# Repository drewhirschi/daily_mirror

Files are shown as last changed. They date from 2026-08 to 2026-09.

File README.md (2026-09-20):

# Daily Mirror

Daily Mirror is a small physical camera appliance: press one button, take one
photograph, and upload it to a private chronological gallery.

The current revival keeps the interaction deliberately narrow. There is no
identity recognition, comparison, notes, alignment, or time-lapse generation.

## Repository layout

- `mobile/` — native Expo iOS gallery and account app, with a persistent,
  bounded thumbnail cache. See [`docs/mobile.md`](docs/mobile.md).
  For remote iPhone builds and installation, see the
  [free Tailscale/Xcode bridge guide](docs/tailscale-xcode-bridge.md).
- `packages/api/` — portable TypeScript API client with types generated from
  the Rust server's OpenAPI contract.
- `device/` — new Rust Raspberry Pi client: camera command, GPIO button and
  three LEDs, durable upload queue, and retries.
- `server/` — new NextRS/Axum API, local filesystem storage, React gallery,
  and Docker Compose configuration.
- `processor/` — intermittent Rust face-processing CLI and leased batch runner;
  the inference adapter is intentionally pending model selection.
- `crates/vision-contract/` — shared queue and face-result wire types used by
  the server and processor.
- `src/`, `snapr/`, and `view/` — the original 2022 Python, Rust/OpenCV, and
  React prototypes retained for reference.
- `data/` — photographs and face-recognition experiments from the original
  prototype. New captures do not belong in Git.

## Prototype flow

```text
button -> LED countdown -> ArduCam JPEG -> durable Pi queue
       -> signed upload grant -> local storage or private R2 -> web gallery
```

The device writes a completed JPEG to its queue before uploading. It removes
that file only after the server acknowledges it. A stable capture ID makes
network retries idempotent.

## Start the web server

```sh
cd server
cp .env.example .env
npm install
npm run client:generate
cargo dev
```

See `server/README.md` for the upload API and container setup.

The password-protected production gallery is deployed at
<https://daily-mirror-pearl.vercel.app>.

The planned path from breadboard prototype to an enclosed Pi appliance, R2 and
Vercel deployment, and a later ESP32 port is documented in
[`docs/productization-plan.md`](docs/productization-plan.md).
Deployment commands and the direct-to-R2 upload flow are documented in
[`docs/deployment.md`](docs/deployment.md).
The local Rust processing worker, durable job queue, face landmarks, identity
review workflow, and centered portrait pipeline are documented in
[`docs/face-processing-architecture.md`](docs/face-processing-architecture.md).

## Bring up the Raspberry Pi camera

```sh
cd device
cp .env.example .env
cargo run --release -- capture-once --no-upload
```

After validating the ArduCam output, configure the server URL and test an
upload before wiring GPIO. See `device/README.md` for pin assignments and LED
behavior.

## Inspect the face-processing queue

After setting `DAILY_MIRROR_SERVER_URL`, `DAILY_MIRROR_PROCESSOR_TOKEN`, and
`DAILY_MIRROR_PROCESSING_PIPELINE` in `processor/.env`, run:

```sh
just process-status
```

The leased Rust processing loop is implemented, but `just process` will refuse
to claim production photos until a face inference engine is selected. See
[`processor/README.md`](processor/README.md) and the
[face-processing architecture](docs/face-processing-architecture.md).

## Quality gates

Run `just check` to format-check, lint, generate and validate the typed client,
type-check the gallery, and test all Rust applications. Run
`just install-hooks` once per clone to make the same suite a mandatory local
pre-push hook. GitHub Actions runs it again for every push and pull request,
and production deployment refuses to start until it passes.

The root npm workspace manages mobile and shared TypeScript packages; the
NextRS server keeps its existing generated-client workspace. Run `npm ci` at
the repository root to install mobile dependencies, then `npm run mobile` for
Metro or `npm run ios` on a Mac to build and open the simulator.

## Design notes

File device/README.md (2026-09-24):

# Daily Mirror device

Rust owns the complete Raspberry Pi interaction loop: camera invocation,
durable local queue, upload retry, button debounce, and the three status LEDs.
The camera itself is invoked through Raspberry Pi's supported
`rpicam-still` command (falling back to `libcamera-still` on older images).

## Bring up the camera before wiring GPIO

```sh
cp .env.example .env
cargo run --release -- capture-once --no-upload
cargo run --release -- upload /path/to/test.jpg
cargo run --release -- retry
```

`capture-once` writes to the durable queue first. With `--no-upload`, it prints
the resulting path and leaves the file there. Without it, the device uploads
the image and removes the local queue copy only after a successful server
response.

Every upload first requests `POST /api/uploads` with the capture ID, JPEG size,
and bearer token. A local server sends the device back to its filesystem upload
route; production returns a short-lived R2 `PUT` URL. The Pi never stores R2
credentials and requests a fresh URL for every retry.

Use `DAILY_MIRROR_CAMERA_ARGS` for sensor-specific tuning after inspecting the
ArduCam. The default is:

```text
--nopreview --timeout 3000 --encoding jpg --quality 95 --autofocus-mode continuous --autofocus-range normal --autofocus-speed fast --autofocus-window 0.2,0.15,0.6,0.7 --metadata-format json --metadata -
```

## GPIO service

Pins use BCM numbering. Defaults are button 2, green 17, yellow 27, and red 22;
all can be changed in `.env`. The button is active-low with its internal pull-up
enabled. LEDs are active-high and must use appropriate current-limiting
resistors.

```sh
cargo run --release -- run
```

- Green: two quick flashes only when the complete workflow succeeds.
  Standby and processing keep the indicator off.
- Yellow: three one-second countdown pulses only.
- Red: a capture/upload error or at least one photograph awaiting retry.

The camera process and continuous autofocus start before the first yellow pulse.
Focus keeps tracking throughout the countdown, allowing the person who pressed
the button to move into the expected 3–5 foot portrait position. The default
focus window covers the central 60% of the frame width and 70% of its height,
rather than only the camera stack's middle third. Yellow stays solid after the
third pulse only until the actual full-resolution frame arrives, so it remains
an unambiguous “hold still” indicator. Green flashes twice on success, then returns to off. Yellow is never reused for background work.

Each normal capture also writes the camera metadata JSON to standard output,
which makes fields supplied by the camera stack such as `AfState`,
`LensPosition`, and `FocusFoM` available in the service journal. Available
fields depend on the installed camera and camera software.

The physical button always takes a picture. Holding it cannot trigger multiple
captures because the service waits for release and debounces both edges.

`run` also starts a small, server-rendered Axum admin page at
`http://<pi-address>:8080`. It shows camera, queue, GPIO, and process status and
mirrors the green, yellow, and red GPIO indicators in real time. It also reports
CPU temperature, one-minute load, memory use, and used/available storage for the
durable queue's filesystem. Status changes are sent over `/api/events` using
server-sent events; the page automatically reconnects and keeps a slow status
request as a fallback. It also has controls to take a picture, retry pending
uploads, and hold any one physical LED on for wiring diagnostics. The LED test
remains active until Restore status is chosen or the physical button is pressed.
Configure the listener with
`DAILY_MIRROR_ADMIN_BIND`. The prototype has no login and should remain on a
trusted LAN; it is intentionally independent of the NextRS archive/gallery.

`GET /healthz` is the lightweight readiness probe. It returns HTTP 200 when the
service is initialized, the camera command exists, uploads are configured, and
the device is not in an error phase; otherwise it returns HTTP 503 with the same
small JSON diagnostic body. The response includes `software_version` from the
running Rust package. It does not capture a photograph.

## Upload credentials and capture metadata

Set `DAILY_MIRROR_DEVICE_TOKEN` to the token this camera was issued when it
paired, and it is used as the `Authorization: Bearer` credential for every
server call: the upload grant, the signed upload when it targets the server
itself, and the completion call. Photographs then land against this device with
`capture_source` `device`. When it is unset (or blank), the legacy shared
`DAILY_MIRROR_UPLOAD_TOKEN` is used exactly as before and photographs land as
`legacy` with no device attached.

Each queued capture also writes a `<capture-id>.json` sidecar beside its
`<capture-id>.jpg` in the durable queue, holding the `capture` object described
in `docs/capture-metadata.md` — sensor, geometry, JPEG quality, exposure, gains,
lens position, AF state, colour temperature, firmware version, trigger and
`captured_at` — plus the raw libcamera control block as `sensor_metadata`. The
uploader reads it when requesting the grant and removes it with the JPEG once
the upload completes, so the metadata survives a restart or a queue drained
hours later. A queued photograph with no sidecar (one left by an older binary,
or a corrupt sidecar) still uploads; the `capture` object is simply omitted.

The trigger is recorded as `button` for the physical button, `app` for the
admin page's Capture now and `POST /api/actions/capture`, and `debug` for the
`capture-once` subcommand. Test-mode and camera-lab captures keep their own
richer local sidecars and are never uploaded.

## Camera lab

The admin's camera lab forces the IMX519's full-field 2328×1748 binned sensor
mode, then scales it to a persistent 960×720 MJPEG viewfinder in memory. It
can adjust exposure compensation, brightness, contrast, saturation, sharpness,
denoising, white balance, metering, exposure profile, manual shutter/gain, and
the complete focus strategy. Focus controls include continuous, single, or
manual modes; range and speed; normalized autofocus-window coordinates; direct
lens position; and one-click fixed-focus presets for 3, 4, and 5 feet. The live
image overlays the selected autofocus region. Starting preview or taking a test
snap automatically applies every visible control, while Apply settings restarts
an active preview so the camera algorithms settle under the new configuration.

The lab also provides persistent 0°/180° rotation and horizontal or vertical
mirroring. Applying settings writes those mounting controls to
`data/camera-settings.json`; the service reloads them at startup and applies
them to the live preview, full-resolution test snaps, and normal button
captures. Override the file location with
`DAILY_MIRROR_CAMERA_SETTINGS_PATH` when packaging the device differently.

`Apply + test snap` stops preview, captures one 4656×3496 JPEG with the visible
lab settings, and retains only its bytes and camera metadata in service memory.
The page shows autofocus state, lens position, focus score, exposure, analogue
gain, the complete metadata JSON, and a link that opens the full-resolution
image for 100% inspection. It does not touch the durable queue, local photo
storage, or gallery upload endpoint. Starting preview again or pressing the
physical button safely releases/reclaims the camera; a physical capture always
stops lab preview before running the normal workflow.

## rpi2: common-anode RGB indicator

The four-leg LED identified on rpi2 has leg 3 as common positive (3.3 V),
leg 2 green (P17 through its own resistor), leg 1 blue (P27 through its own
resistor), and leg 4 red (P22 through its own resistor). Button: SDA/P2 to GND.
Set `DAILY_MIRROR_LED_MODE=rgb-common-anode`. Keep the legacy pin environment
names: `YELLOW_LED_PIN=27` now identifies the physical blue output.

RGB mode starts all channels HIGH/off. Countdown yellow
combines red and green; success flashes green while ready/processing stay off. A queued upload
shows steady red instead of combining ready green and error red into yellow.
The admin's green/yellow/red lamps represent logical status colors; `/api/status`
also reports `led_mode`. Blue and white are reserved for later behavior.
The default `discrete` mode preserves rpi1's active-high three-LED hardware.

Select `DAILY_MIRROR_CAMERA_PROFILE=ov5647` for Camera v1 or `imx219` for
Camera v2. Omit `DAILY_MIRROR_CAMERA_ARGS` to use the profile defaults.

A matching systemd unit is in `deploy/daily-mirror-device.service`. It expects
`/home/drew/daily-mirror-device/bin/daily-mirror-device` and a mode-0600 `.env` in
`/home/drew/daily-mirror-device`. Enable the unit after installing both.
Use `DAILY_MIRROR_ADMIN_BIND=0.0.0.0:8081` for the new Pi.

## Camera profiles and local development

Two independent settings control hardware behavior and photo destination:

```text
DAILY_MIRROR_CAMERA_PROFILE=ov5647
DAILY_MIRROR_CAPTURE_MODE=local
DAILY_MIRROR_LOCAL_DIR=./data/local
```

| Profile | Camera | Full-resolution still | Focus |
| --- | --- | --- | --- |
| `imx519` | IMX519 | 4656 × 3496 | Autofocus, manual lens control |
| `ov5647` | Pi Camera v1 / Rev 1.3 | 2592 × 1944 | Fixed focus |
| `imx219` | Pi Camera v2 | 3280 × 2464 | Fixed focus |

`camera_profile.rs` holds the sensor-specific resolution, focus capabilities,
and preview-mode choices. The shared rpicam backend owns file capture, JPEG
validation, camera locking and orientation. Both normal capture and the lab
(still and preview) use the same profile; the UI disables unsupported focus
controls. Add future rpicam-compatible sensors here rather than scattering
sensor checks through the application. A USB/OpenCV camera would require a
separate capture backend, not merely another sensor profile.

Profiles are selected explicitly; they do not install kernel drivers or identify
a disconnected sensor. The default stays `imx519` for existing installations.
`DAILY_MIRROR_CAMERA_ARGS` remains an advanced override for normal capture only;
it replaces profile-generated arguments, so remove stale overrides when changing
sensors. Preview and lab stills continue to use the selected profile.

`local` mode saves button and admin captures in `data/local`, never queues or
uploads them, disables upload retries, and ignores server credentials even if
present. The admin page shows the latest 24 local photos, with full-resolution
links. This page is accessible on the LAN. Files remain until manually removed;
monitor free disk space during development. `capture-once --no-upload` also uses
this separate local directory, even when configured for upload mode.

`upload` mode retains the existing durable queue/retry behavior in `data/pending`.
Switching to upload mode does not sweep local photos into that queue. The two
directories must be distinct. The code defaults to `upload` for compatibility;
the example environment explicitly selects `local` for new development setups.
The standalone `upload` command refuses to run in local mode.

On rpi2, uploads are disabled and production credentials have been removed.
The replacement camera is now IMX519. Boot configuration sets
`camera_auto_detect=0` and `dtoverlay=imx519`; detection was verified after reboot.
The stock sensor tuning lacked `rpi.af`, even though the AK7375 lens driver was
bound. A separate `config/imx519-portrait.json` adds contrast autofocus and a gentle
shadow lift, selected by
`LIBCAMERA_RPI_TUNING_FILE` in the device `.env` for both stills and preview.
The actuator map is provisional: reported lens position and distance presets
are not calibrated physical distances for this replacement module.
See [the calibration record](../docs/imx519-rpi2-calibration.md). The admin `camera_available` API field
remains an executable check, not a sensor probe.

### Inspect local test photos

In local capture mode, click a photo in **Local test photos** to open the
in-page viewer. Use the newer/older buttons or left/right arrow keys to move
through the listed photos; Escape or Close returns to the grid. **100%** shows
native image detail with scrolling, and **Fit** returns to the whole frame.
The Metadata button hides or shows the overlay without leaving the image.

The overlay reads embedded JPEG EXIF: exposure, ISO, reported focus distance,
camera/software, timestamp, and other supported fields, plus file size and
displayed dimensions. Missing fields are explicitly unavailable; current lab
settings are never attributed to old captures. EXIF timestamps have no assumed
timezone, and reported focus distance is not a measurement of subject distance.
This does not change capture processing or rewrite the originals.

Parser checks: `node device/tests/local_photo_viewer.test.cjs` from the repository root.

### Admin Test mode and photo profiles

In **Photo settings**, enable **Test mode**, choose a profile, and press **Save photo settings**.
This controls the physical button and **Capture now**. Test captures go to `data/local/` with
JSON sidecars containing the profile, command arguments, orientation, tuning file, and sensor
metadata. They are never queued for upload, including after Test mode is disabled. Upload
retries pause in Test mode. A mode change waits for an existing capture/upload to finish;
the saved confirmation marks when the new policy applies.

The selection survives service restarts in `data/photo-settings.json` (override with
`DAILY_MIRROR_PHOTO_SETTINGS_PATH`); saved settings take precedence over the environment's
initial capture mode. `capture-once --no-upload` still forces a local capture.

IMX519 profiles:
- **Current device configuration** preserves the configured camera arguments and tuning.
- **Neutral**: 4656×3496, stock tone with contrast AF, neutral color/sharpness.
- **Vibrant**: 4656×3496, lifted shadows, saturation/sharpness 1.15, sport exposure.
- **Fast**: 2328×1748 with the full-field binned sensor mode, Vibrant processing.

Named profiles require `config/imx519-af.json` and/or `config/imx519-portrait.json` relative
to the service working directory. These already exist on rpi2; use
`scripts/prepare_imx519_tuning.py` on the Pi to generate them (shadow exponent 1 and 0.85).
Other sensors retain their device configuration. Multi-frame merging is not yet an admin profile.

**Local test photos** offers photo and settings downloads in either mode. For bulk retrieval,
copy the device's `data/local/` directory with SCP/rsync. Existing photos predating metadata
sidecars may have no settings download. Custom camera-lab captures also save here, labeled
`custom-lab`; the lab keeps its independent controls rather than applying the photo profile.
No automatic local-photo deletion is performed; the admin page shows remaining storage.

API: `POST /api/photo-settings` with `{"test_mode":true,"profile":"vibrant"}`; active settings
appear in `/api/status`. Local files: `/api/local/photos`, `/api/local/photos/{name}`, and
`/api/local/photos/{name}/metadata`. Returning to cloud capture requires configured server
URL and upload token; it resumes the existing upload queue, never local test photos.

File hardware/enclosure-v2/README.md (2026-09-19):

# Daily Mirror - rail enclosure prototype 02

This is the September 10, 2026 revision for the **confirmed Raspberry Pi 4 Model B**.
It replaces the old rail motion study with printable mating parts, a thumb lock,
removable end stops, actual camera standoffs, and front control holes.
The earlier `hardware/enclosure` concept remains available unchanged.

**Start with `output/model-viewer.html` in a browser** to rotate the real model,
show the internals, separate the lid, and move it through its full travel.
FreeCAD's window is not needed for viewing this preview or printing the STLs.

For the mounting details, select **How the Pi screws in** or **How the rail
attaches** in the viewer. Both views separate the parts and show reference
screws; move separation to zero to see them assembled. The attachment view
shows only a short section of the actual rail for clarity. The four enclosure
screws are inserted from inside the case into the orange sliding block.
The Pi uses its four existing mounting holes; additional retaining clips are
not part of this screw-mounted design. Reference fasteners are not printed.

For scale, the enclosure is about **5.5 x 6.7 x 2.2 inches**, versus an
85 x 56 mm Pi PCB. It deliberately includes room for the camera, controls,
power-plug routing, cooling and later flash components. It is smaller than
the earlier 180 x 180 x 73 mm enclosure concept.

Enclosure, internal mounts and rail

## What is modeled

| Feature | Prototype dimensions / behavior |
| --- | --- |
| Enclosure | 140 wide x 170 tall x 55 deep mm including front panel; 3 mm walls; rounded corners |
| Pi mounts | Four 8 mm raised posts, 58 x 49 mm hole centers; 2.0 mm pilot bores |
| Camera mounts | Four 9 mm raised posts on the front panel; 21 x 12.5 mm hole centers; 1.6 mm pilots |
| Front openings | 18 mm lens, 5.2 mm status LED, 12.2 mm button |
| Power | One 14 mm bottom cable passage, internal zip-tie saddles; no exposed USB/Ethernet/HDMI ports |
| Rail | Two 208 mm sections, 416 mm assembled; 80 mm wide, 12 mm maximum wall depth |
| Rail joint | 6 mm rear alignment tongue; each section independently screws to the wall |
| Carriage | 60 x 100 mm, captive dovetail, 0.4 mm horizontal side and top allowances |
| Adjustment | 300 mm continuous travel between separately installed end stops |
| Lock | M4 thumb screw, captive nut, 8 mm rubber/TPU brake pad; knob accessible below the box |
| Wall projection | 78 mm nominal to front face, excluding button/lens projection |
| Future flash | 24 x 28 x 20 mm reserved volume; replaceable front panel for later optics |

The **entire box moves**: Pi, camera, LED, button and their wiring. Only the
external power cable flexes during height adjustment. Leave a loose service loop
that reaches both travel limits without tugging on the plug.

This design assumes a **new printed rail**, not compatibility with a purchased
rail. It uses wall screws, not adhesive strips. Each rail section must be fixed
to the wall; the small tongue aligns the joint and does not carry the wall load.

## Files and slicer basics

- `output/DailyMirror-Rail-Enclosure-v2.FCStd`: native FreeCAD document with
  named solids, grouped printable parts, hardware references and fit coupons.
- `OpenModel.FCMacro`: optional FreeCAD macro that opens the document with
  clean visibility and part colors. Run via Macro > Macros, or open the macro
  file in FreeCAD. The model can be opened directly without running the macro.
- `output/*.stl`: **one physical part per file**, in millimeters, pre-oriented
  and moved onto the print bed. Import each as an independent part at 100% scale.
- `output/*.step`: CAD solids in **assembly coordinates**, useful for editing
  or moving to another CAD program. `Assembly.step` has the nine print parts.
- `output/model-viewer.html`: self-contained interactive preview; no account,
  external library, network, or FreeCAD install needed. It requires WebGL.
- `output/enclosure-preview.png` and `output/mount-details.png`: still previews.
- `dimensions.json` and `build.py`: the coordinated dimension source and
  modeling recipe. Change the JSON and rebuild to change the fit. The FCStd
  contains editable solids, **not a fully constrained sketch-based feature tree**.
- `output/validation.json`: actual geometry/interference check results.

An STL describes the shape. Your **slicer** combines it with your printer,
nozzle and material settings to produce the printer's job file, often G-code.
No printer-specific job has been generated because the printer is not yet known.
Do not send STEP/FCStd files directly to the printer.

## Print these small pieces first

1. `RailFitMale.stl` and `RailFitFemale.stl`: matching short sections of the
   exact dovetail. They should slide by hand without being forced and without
   excessive rocking. Remove elephant's foot first. Change `rail_clearance`
   in 0.1 mm increments and rebuild if needed; do not globally scale the parts.
2. `CameraFitCoupon.stl`: a small section of the actual front panel, containing
   the real lens opening and four real posts. Screw the camera onto it from
   behind. Confirm hole positions, screw engagement, component clearance and
   full-field image coverage. The camera faces through the hole; its ribbon
   connector points toward the bottom of the enclosure.
3. Check a Pi screw gently in one post and confirm your M4 nut and bolt head fit
   the carriage and knob pockets before assembling everything.

## Full print list

| STL | Quantity | Supplied print orientation | Notes |
| --- | --- | --- | --- |
| Housing | 1 | Flat rear on bed, cavity up | Vents bridge 3 mm; tie saddles bridge 3 mm |
| FrontPanel | 1 | Exterior face on bed, camera posts up | Keep lens hole and posts clean |
| RailLower | 1 | Flat back on bed | 80 x 214 mm footprint including alignment tongue |
| RailUpper | 1 | Flat back on bed | 80 x 208 mm; small rear key pocket bridges 16.5 mm |
| Carriage | 1 | Standing on short end | 60 x 18.6 mm footprint, 100 mm tall; use brim |
| StopLower / StopUpper | 1 each | Standing on short end | These are separately installed pieces |
| LockKnob | 1 | Flat back on bed, hex pocket up | Captures M4 hex-head screw |
| BrakePad | 1 | Flat | TPU, or cut an 8 mm disc from 1.5 mm rubber |

Starting settings for a fit prototype: 0.4 mm nozzle, 0.2 mm layers, four walls,
five top/bottom layers, 25-35% infill. Use a brim on the upright carriage and
small stops. Inspect overhangs and bridging in your slicer, especially the
rail's alignment pocket and the lock-nut loading slot. Remove any support or
brim residue from sliding surfaces and threaded pilots.

All rigid parts fit a nominal **220 x 220 mm bed**, before printer-specific
exclusion zones. The 214 mm rail leaves only 3 mm at either end on that bed:
omit a wide brim there or change the segment length for a smaller printer.
The design is intended to print without extensive supports in the supplied
orientations, but the actual slicer preview and first print decide this.

PLA is suitable for the first dimensional trial. Choose the installed material
after measuring enclosure temperature; PETG is a candidate for the final trial.
Use the same material/settings for rail coupons and final rail parts. No
temperature, friction, lifetime or load performance has been physically tested.

## Hardware

Lengths below are **under the head**, with no additional washers unless you
adjust length. Use small pan/wafer heads for PCB screws. The printed pilots are
intended for thread-forming screws for plastic; do not force unsuitable screws.

| Hardware | Quantity | Purpose |
| --- | --- | --- |
| M2 x 6 thread-forming screws | 4 | Camera through PCB into front posts |
| M2.5 x 8 thread-forming screws | 4 | Pi through PCB into 8 mm posts |
| M3 x 12 thread-forming screws | 4 | Front panel to shell, 9 mm engagement |
| M3 x 10 thread-forming screws | 4 | Through inside of housing rear into carriage, 7 mm engagement |
| M3 x 12 thread-forming screws | 4 | Two per recessed end stop, 4 mm rail engagement |
| M4 x 16 hex-head machine screw | 1 | Thumb lock; nominal 7 mm across-flats head |
| M4 hex nut | 1 | Captive carriage nut, nominal 7 mm across flats x 3.2 mm thick |
| Rubber/TPU disc, 8 mm diameter x 1.5 mm | 1 | Brake contact pad; may use BrakePad STL |
| Wall screws and suitable anchors | 8 | Rail holes are 4.5 mm; heads must be <=8 mm diameter |
| Small zip ties | 2 | Internal power cable restraint |
| 5 mm LED + wiring, 12 mm panel button | 1 each | Placeholder control sizes; choose exact parts before full panel print |

The status LED's flange fits within the 7 mm baffle bore. Secure it with a small
amount of suitable removable adhesive after checking fit. The button must accept
a 3 mm panel and its internal body/nut must fit within the 18 mm diameter,
25 mm depth allowance. Hardware shown in the viewer is simplified, not supplied.

## Assembly sequence

1. Print and test the fit coupons. Deburr openings and sliding edges. Verify
   that each pilot accepts its intended screw without splitting the post.
2. Insert the M4 nut into the carriage's slot from the **lower end**. Insert
   the M4 x 16 bolt into the knob's front hex recess and engage it in the nut.
   Place the brake pad in its 8.5 mm pocket facing the rail. A tiny dab of flexible
   adhesive on the screw tip can retain the pad; keep adhesive off the rail.
   Back the knob out enough that the pad does not drag during insertion.
3. Fasten the carriage to the enclosure with four M3 x 10 screws from inside.
   Its long section projects below the housing; the knob must remain reachable.
4. Feed the unplugged USB-C lead through the bottom opening. This assumes the
   plug overmold is no more than about 13 mm across. Fit a protective sleeve if
   needed, plug into the Pi, and secure the cable to the internal saddles with
   zip ties. The printed opening itself is a passage, not a sealing gland.
5. Screw the Pi onto its four posts. Confirm that no screw tip or mounting part
   touches a PCB component. The model allows 26 mm above the board for cooler,
   components and header plugs; check your actual assembly against that space.
6. Install the camera on the front-panel posts, lens facing outward. Add the
   LED and button, connect their wiring, and route the camera ribbon with a
   relaxed service bend. No repeated ribbon flex is needed during rail motion.
   Support the lid when opening it: it carries the camera and is tethered by the
   ribbon. Use the four M3 x 12 screws to close the panel.
7. Align the two rail sections vertically on a flat mounting surface with the
   tongue engaged. **Use the carriage straddling the joint as an alignment gauge**
   before final tightening. Fix both sections with the eight wall screws. Keep
   the screw heads outside the carriage path; the model allows <=8 mm heads.
8. Fit the lower stop. Slide the carriage onto the rail from the open upper end,
   then screw on the upper stop. The separate stops make insertion and servicing
   possible. Do not leave the sliding assembly without both stops fitted.
9. Support the enclosure with one hand, loosen the knob, choose a height, and
   tighten gently. The pad presses the rail and takes up play against the
   dovetail. Check holding force at several heights and across the joint before
   leaving it mounted. The stops limit travel but are not a rated safety catch.

**There is no validated holding-load rating yet.** Weigh the complete unit and
bench-test the actual printed rail, brake, fasteners and wall attachment with
that load, including repeated adjustment and button presses. After fit-up,
verify that sustained camera operation does not cause Pi throttling or excess
heat inside the enclosure. Keep the external power service loop free through
the full 300 mm of travel.

## Remaining measurements

The Pi model is confirmed. These dimensions remain provisional:

- Actual sensor board/lens: 25 x 23.862 mm PCB reference, 21 x 12.5 mm mounting
  centers; lens center assumed 9.5 mm from the top PCB edge, lens envelope
  15 mm diameter x 11 mm projection. PiCam-compatible holes do **not** guarantee
  identical lens position or component heights. The camera coupon checks this.
- Exact button and LED parts, printer model, material and useful bed area.
- Installed cooler, GPIO connectors, ribbon length/bend and USB-C plug overmold.
- Required wall location, useful height range and mounting surface.

The flash is **reserved space only**, not a working flash mount, diffuser or
electrical design. A future flash can use a revised front panel; it needs its
own chosen light source, optics, driver and heat management. The status LED
opening does not assume it can light a photograph.

## Geometry checks and rebuilding

```bash
bash hardware/enclosure-v2/build.sh
```

The build uses the installed FreeCAD 1.1.3 modeling engine without opening a
window. It checks all printable solids, closed meshes, pairwise printable-part
interference, hardware-to-shell/front clearances, sampled movement across the
rail joint and through both travel limits, and geometric retention by the
dovetail and end stops. Saved FCStd/STEP/STL files are reopened to check that
geometry, volumes, print dimensions and bed placement survive export.

These checks establish coherent printable geometry, **not physical fit or
structural certification**. The numeric report is in `output/validation.json`.
The generator asserts the minimum fixed-layout envelope when dimensions change;
larger layout changes may require edits to the Python recipe as well as JSON.
Rebuild with the model closed, or save manual FreeCAD edits to another filename.

## Dimension sources

- [Official Raspberry Pi 4 B mechanical drawing](https://datasheets.raspberrypi.com/rpi4/raspberry-pi-4-mechanical-drawing.pdf):
  85 x 56 mm board, 58 x 49 mm hole pattern, 3.5 mm edge offsets. Saved in `reference/`.
- [Official Camera Module 2 mechanical drawing](https://datasheets.raspberrypi.com/camera/camera-module-2-mechanical-drawing.pdf):
  25 x 23.862 mm board, four 2.2 mm holes, 21 x 12.5 mm pattern after orienting
  the ribbon downward. Saved in `reference/`. This establishes a reference
  pattern, not the dimensions of the user's different sensor/lens.
- [Raspberry Pi camera hardware documentation](https://www.raspberrypi.com/documentation/accessories/camera.html):
  shared board/hole geometry does not imply interchangeable lens clearance.

Camera posts and locking carriage

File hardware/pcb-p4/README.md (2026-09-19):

# Daily Mirror custom PCB - A1 component study

Open **daily-mirror-p4.kicad_pro** in KiCad 10. This is an editable starting
project with the connected controls schematic and **64 additional candidate
components** on four new schematic pages and the board. It now has 80 electrical
references plus four mounting holes. The imported main components have no circuit
connections yet; the board has no routed traces. **Do not order this board.**

See [sourcing.md](sourcing.md) for the part choices, 3D-model limitations and
open-reference workflow. [candidate-parts.csv](candidate-parts.csv) records
the new parts and their sources; it is not an order-ready BOM.

An editable, routed Olimex P4 development-board reference is in
[reference/olimex-esp32-p4-devkit](reference/olimex-esp32-p4-devkit).
Open its `ESP32-P4-DevKit_Rev_D1.kicad_pro` separately to inspect the original
connected design. It has not been merged into the Daily Mirror circuit.
The previous A0 files/previews are saved in `revisions/a0`.

## Decisions from this session

- Keep the existing Arducam IMX519 as the camera baseline; preserve the goal of
  16 MP stills. Use a purchased camera module on a ribbon cable. The image
  sensor and lens do not need to be integrated onto the main custom PCB.
- USB-C wall power; a new enclosure designed around the final electronics.
- Cost matters: favor a standard four-layer main board for the P4, common
  stocked components, and assembly on one side where practical. Evaluate total
  assembled cost, including setup and shipping, rather than promotional bare-PCB
  prices. No per-unit budget or production quantity has been specified yet.
- One small four-pin RGB status indicator, plus a momentary capture/pairing button.
- **White-only emitters are preferred** around the perimeter for photographs.
  The three-color CL651-3S modules are optional prototype parts, not a required
  final component. Choose documented white LEDs/modules and their current
  drivers once the brightness, optical layout and power budget are established.
- Snap-in removable diffuser above the light modules. Include an opaque lens
  baffle, room between diffuser and emitters, and space behind the modules for
  a heat-spreading mount. Diffuser material, thickness, gap and clips need an
  optical/mechanical prototype; the current enclosure models are Pi-specific.

## Important processor finding

**The ESP32-P4 is still a candidate, not a confirmed solution for full-resolution
IMX519 capture.** Having a matching MIPI interface does not establish camera support.

Espressif's current ISP header defines `ISP_LL_HSIZE_MAX` as **1920**. Its ISP
driver rejects larger `h_res` values. The IMX519 full image is **4656 x 3496**.
Thus the ordinary P4 ISP processing path cannot process a full-width 16 MP frame.
This is an image-processing-path limit, not proof that every raw CSI/DMA capture
path is impossible. A bypass-and-upload approach would need a sensor driver,
working DMA/buffer handling, exposure/focus control and a server image pipeline.
It has not been implemented or tested here.

The official sensor list does not list a native IMX519 driver. Its Arducam
PIVARIETY entry does not establish support for the user's native IMX519 module.
The community IMX driver project checked lists other IMX sensors, not IMX519;
its results cannot be assumed to apply to this camera.

A packed RAW10 full frame is 20,346,720 bytes (19.40 MiB); a 16-bit-per-pixel
buffer takes 32,554,752 bytes (31.05 MiB), before firmware and other buffers.
Capturing infrequently reduces average throughput, but not those per-frame
buffer requirements. Streaming approaches must be proven separately.

**Next hardware gate:** demonstrate a full-field still from the actual IMX519
on the proposed processor, with usable exposure/focus and successful upload.
If P4 raw capture cannot meet that requirement, select a processor with a
validated IMX519 pipeline before drawing its main circuit. A custom board
does not require a Raspberry Pi, and a P4 has not been chosen merely for size.

Source snapshot: ESP-IDF commit `c712a0dde385d659a1470a136251980d31a70bc1`,
checked September 14, 2026. See [reference/isp-limits.md](reference/isp-limits.md).

## What is actually drawn

| Reference | Circuit | Current choice |
| --- | --- | --- |
| D1 | Common-anode RGB indicator | Project symbol preserves documented pin order: 1 blue, 2 green, 3 common positive, 4 red |
| R1-R3 | One current-limiting resistor per color | 1 kohm provisional; adjust after measuring forward voltage and brightness |
| R5-R7 | Pull each color control high while GPIO is floating | 100 kohm; high = off, low = on |
| SW1 | Normally-open momentary button | Generic 6 mm tactile footprint, 4.3 mm actuator height candidate |
| R4 / C1 | Button pull-up and filter | 10 kohm / 100 nF; approximately 1 ms RC; use firmware debounce as well |
| TP1-TP6 | Future processor/control test access | 3.3 V, ground, blue, green, red, button |
| H1-H4 | Board-only mounting holes | M3 clearance, provisional 92 x 92 mm spacing |

The LED's common positive leg has **no fourth series resistor**. Three separate
color resistors avoid the brightness interactions caused by sharing one resistor.
The 1 kohm starting values cap direct GPIO current below 3.3 mA per channel at
3.3 V; final brightness, GPIO limits and resistor power must be checked against
the chosen parts. This is only the small indicator circuit, not the COB driver.

The RGB symbol follows [the existing wiring record](../../device/README.md),
but the loose LED's view/orientation, lead size and lead order must be confirmed.
The candidate **wide-pin** footprint uses formed leads at 2.54 mm pitch; it is
not a claim that the unbent loose LED has that pitch. The generic button's
mechanical height must also be chosen with the new faceplate.

The board is a **100 x 100 mm, four-copper-layer space study**. None of those
dimensions, mounting holes or layer rules is a final manufacturing specification.
The PCB now contains the imported candidate footprints, including eight white
emitters. The camera faceplate clearance is still a drawing guide; the separate
camera module, cable, diffuser and enclosure have not been mechanically modeled.
The 3D preview represents these placed components; five package types use explicitly
approximate models. See the sourcing notes before using this for mechanical fit.

## Existing CL651-3S prototype light modules

The final board can use white-only parts instead. The notes below apply only
if the already-owned three-color modules are used for prototype measurements.

The supplied photo and the manual linked from the exact
[Temu listing](https://www.temu.com/goods.html?goods_id=606385509136562&sku_id=99388093393455)
identify a three-color, common-negative COB module. The manual explicitly maps:

| Pad marking | Seller's stated function |
| --- | --- |
| `B+` | White positive |
| `W+` | Blue positive |
| `R+` | Red positive |
| `-` | Shared negative |

This unusual B/W assignment should be checked at low current on a current-limited
bench supply before wiring a batch. Only white and negative will be used;
unused red/blue positives stay unconnected.

The listing/manual states **3.2-3.7 V** and warns of heating at 3.7 V. It provides
**no rated current, pulse current, pulse width, thermal resistance, CRI or CCT**.
It is not a complete electrical datasheet. Do not substitute its broad listing
category `<=36 V` for the actual operating voltage.

Plan a controlled-current path for each white module, with default-off enable
and a bounded illumination time. Do not drive COB modules from GPIO, connect
them directly to USB's 5 V, or infer a current limit from voltage alone. Do not
parallel bare modules behind one driver without a validated current-sharing scheme.
The appropriate buck/linear topology, current sense resistor, module count,
connector, copper area and USB supply rating remain unresolved.

These parts already have their own substrate. The likely integration is short
two-wire connections to modules mounted around the faceplate/perimeter, with
control electronics on the main PCB. Direct mechanical/electrical attachment
to the main board needs measured pad positions, mounting holes and a thermal
design. No guessed CL651-3S solder footprint is included.

### Flash timing and diffuser

Short duty cycles reduce average heat: `average electrical power = V * I *
on-time * flashes-per-second` for constant rectangular pulses. Peak junction
temperature and safe pulse current still matter; average power alone does not
establish safety. Repeated presses and a stuck-on software state must be tested.
No pulse overdrive is assumed without a manufacturer rating.

The IMX519 is a rolling-shutter camera. Start with steady white illumination
through the full frame exposure/readout window, then characterize the shortest
uniform pulse from actual captured images. Avoid unsynchronized PWM during
capture. Test for bands, face shadows, clipping, diffuser hot spots, lens flare
and enclosure temperature at the maximum intended repeat rate.

Record current, measured light output and duration before deciding whether a
small heat spreader is enough. Keep diffuser clips clear of the thermal path.

## What the main circuit still needs

- Camera-proven processor, package/revision and memory capacity.
- For a P4 design: external flash, reference crystal, core regulator, PHY and
  other supplies/decoupling, reset/boot circuitry and programming access. Use
  Espressif's revision-v3-or-later reference; older revisions differ electrically.
- Wi-Fi/BLE companion and antenna layout if using P4. ESP32-C6-MINI-1 with SDIO
  is the reference direction; P4 itself does not contain a Wi-Fi/BLE radio.
- USB-C connector, CC handling, input protection, regulator and current budget.
  Two CC pull-downs establish a sink attachment but do not by themselves authorize
  a 3 A load. Detect the source's available current or negotiate PD as required.
- Exact Arducam module SKU/revision and ribbon. Pi-style connectors can be 15-pin
  1 mm or 22-pin 0.5 mm. Confirm connector-side pin numbering, contacts, supply,
  controls, level shifting and cable orientation before assigning the footprint.
- CSI differential pairs routed against the chosen fabricator's stackup and
  Espressif's guidelines; impedance is not established by arbitrary trace widths.
- Flash/illumination driver and any local storage required for failed uploads.

The phone experience is firmware/app work too: BLE discovery while pairing,
authenticated ownership setup, transfer of Wi-Fi credentials, association and
account registration, then normal capture/upload. Add long-press recovery,
factory reset, signed updates and upload retry. KiCad does not implement this.
The existing Pi program invokes `rpicam-still`; that part cannot run unchanged
on the P4. Backend protocols and device states can be reused where applicable.

## KiCad setup and working together

KiCad **10.0.6** was installed without its library packages. The matching official
Arch packages (`kicad-library` and `kicad-library-3d`, 10.0.6-1) were downloaded,
their signatures verified against the installed Arch keyring, and extracted to:

`/home/drew/.local/share/kicad/10.0/official-10.0.6`

This per-user install avoids the system installer's password requirement. It
does not register those two library packages with pacman. KiCad's global library
table references and `KICAD10_*` paths were updated. The previous settings are in:

`/home/drew/.config/kicad/10.0/before-daily-mirror-20260914-214132`

The dangling default reference to a nonexistent optional design-block library
was also removed; its original table is in that backup. Design blocks are not
needed for this project.

Restart KiCad once if it was already open. Then:

1. **File > Open Project** and select `daily-mirror-p4.kicad_pro` in this directory.
2. Open the `.kicad_sch` for the architecture and control circuit.
3. Open the `.kicad_pcb`; enable `User.Drawings` to see the reserved areas.
4. Use **View > 3D Viewer** to inspect the placed candidate parts.

The current 3D render is `output/board-3d.png`. The STEP assembly in
`output/daily-mirror-a0.step` contains the current board and the placed component
models, and can be opened in mechanical CAD for enclosure work. Neither includes
the unselected processor, camera module, power connectors or white emitters.

### Reading the design

The schematic describes electrical connections. Green lines are wires in that
diagram; repeated net names identify the same electrical connection without
drawing a long line across the page. The PCB shows real component locations and
solder pads. Its connections become copper **traces** routed between pads;
this initial board has no routed traces yet. In the PCB editor, thin ratsnest
lines can show which pads still need connections; those are guides, not copper.
The 3D viewer shows physical models, not schematic symbols or ratsnest lines.

| Label | Meaning |
| --- | --- |
| J1, J2 | Connectors, such as camera ribbon or USB |
| U1, U2 | Integrated circuits/chips; exact function depends on the part |
| R1, R2 | Resistors |
| C1, C2 | Capacitors; often resemble tiny resistors |
| D1 | Diode or LED |
| SW1 | Switch/button |
| TP1 | Test point |

For a sourced part, check three separate CAD representations: its schematic
symbol (electrical pins), footprint (solder pads and holes), and STEP/3D model
(physical shape). Matching physical shape alone does not prove the pin mapping
or circuit works. Use exact manufacturer part numbers and package drawings.

### Making a physical unit

PCB fabrication makes the patterned copper board. PCB assembly adds and solders
the purchased components. An assembly order typically needs Gerbers/drill files,
a bill of materials with exact part numbers, and placement/orientation data.
Fabricators do not print silicon image sensors or lenses. A camera module can
be purchased separately and connected after board assembly.

JLCPCB offers an assembly parts library and sourcing/consignment options;
PCBWay offers turnkey, partial-turnkey and customer-supplied component assembly.
Stock, exact packages and service eligibility must be checked before choosing
the final bill of materials. Firmware flashing and functional testing require
their own agreed process; soldering the board does not establish that it works.

- [DigiKey CAD models](https://www.digikey.com/en/product-highlight/a/accelerated-designs/ultra-librarian)
- [KiCad 10 PCB and 3D documentation](https://docs.kicad.org/10.0/en/pcbnew/pcbnew.html)
- [JLCPCB bill of materials requirements](https://jlcpcb.com/help/article/bill-of-materials-for-pcb-assembly)
- [JLCPCB parts sourcing](https://jlcpcb.com/help/article/how-to-build-your-own-parts-library-in-jlcpcb)
- [PCBWay component sourcing](https://www.pcbway.com/pcb_prototype/Electronic_Components.html)

There is no callable KiCad MCP in this session. We can edit the native files
and use KiCad CLI for validation and previews. Close the affected editor before
external edits and reopen it afterward; do not assume live reload. For edits
made in the schematic editor, **Update PCB from Schematic (F8)** transfers changes.
The `.kicad_pro` file is the project, `.kicad_sch` is the circuit, and
`.kicad_pcb` is the physical board.

Small project-local symbol, footprint and 3D libraries make the study portable.
The generator refuses to overwrite an existing design. Interactive KiCad files
are the source of truth once editing begins. To reproduce the initial study in
a separate directory:

```sh
python build_starter.py --output /tmp/daily-mirror-pcb-study
```

## Checks

See [output/validation.json](output/validation.json) for the final counts.
The controls schematic still has zero ERC violations and its nine nets match
the board pads. All 80 schematic component pin-number sets match the footprints,
with J2's additional mechanical mounting tabs explicitly accounted for. All 74
placed model references resolve. No component courtyards overlap.

The whole project has **377 ERC findings** from unconnected/undriven candidate
pins and **96 DRC findings** (USB pad nets/connector hole clearance and silkscreen
size/overlaps). The 21 unrouted controls connections remain; because the new
circuits have no assigned nets, that number does not count their future routing.
No Daily Mirror Gerbers, assembly order or firmware release has been produced.

## Sources

- [Espressif P4 reference board](https://docs.espressif.com/projects/esp-dev-kits/en/latest/esp32p4/esp32-p4-function-ev-board/user_guide.html): P4/C6 architecture.
- [P4 schematic guidance](https://docs.espressif.com/projects/esp-hardware-design-guidelines/en/latest/esp32p4/schematic-checklist-esp32p4.html): revision changes and support circuitry.
- [P4 layout guidance](https://docs.espressif.com/projects/esp-hardware-design-guidelines/en/latest/esp32p4/pcb-layout-design-esp32p4.html): signal and power layout.
- [Espressif sensor support](https://github.com/espressif/esp-video-components/tree/master/esp_cam_sensor): supported sensors.
- [Arducam IMX519 documentation](https://docs.arducam.com/Raspberry-Pi-Camera/Native-camera/16MP-IMX519/): resolution, RAW formats and rolling shutter.
- [Community IMX driver project](https://github.com/mushBrainDave/esp32-p4-imx-camera): context only; not an IMX519 compatibility claim.
- [Raspberry Pi camera documentation](https://www.raspberrypi.com/documentation/accessories/camera.html): connector families.
- [Seller's LED manual](reference/cl651-3s-manual.pdf): voltage, terminal labels and heat warning; no current rating.

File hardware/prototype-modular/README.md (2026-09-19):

# Daily Mirror — modular prototype comparison

Research date: September 14, 2026. USD. Purchasing candidates, not a verified working kit.

## Preferred first prototype

Use a purchased processor board, a ribbon-connected camera, and hand-soldered lighting and controls. This avoids the setup cost of assembling a new processor PCB for the first unit. Keep the custom PCB placement study in `../pcb-p4/` for later development.

The first decision remains **camera compatibility**. The existing 16 MP Arducam IMX519 is required. Neither its driver nor full-resolution still capture on the ESP32-P4 has been demonstrated here. A matching-looking MIPI connector does not establish compatible pinout, voltage, cable contact orientation, driver, or image pipeline. Do not order a P4 board on the assumption that this camera will work without development.

## Parts and budget

| Item | One prototype | Ten prototypes | Basis |
| --- | ---: | ---: | --- |
| Waveshare ESP32-P4-NANO basic board | $18.99 | $189.90 | Store lists from $18.99; ten uses the same unit price, not a bulk quote |
| White photo lights and driver | $10–20 | $100–200 | Planning allowance; exact light/driver pairing remains to be selected |
| Perfboard, wiring, button, RGB indicator, resistors | $5–10 | $50–100 | Planning allowance; existing parts may reduce this |
| **Base parts budget** | **$33.99–48.99** | **$339.90–489.90** | Calculated from the rows above |
| Optional VEML7700 light sensor, Adafruit #4162 | $4.95 | $44.60 | In stock when checked; ten-unit price $4.46 each |
| Optional LIS3DH accelerometer, Adafruit #2809 | $4.95 | $44.60 | In stock when checked; ten-unit price $4.46 each |
| **With both sensors** | **$43.89–58.89** | **$429.10–579.10** | Sensor cables may add cost |

Excludes camera, camera cable/adapters, USB power supply/cable, enclosure and diffuser, shipping, tax, tools, and soldering labor. No Amazon listing, delivered checkout price, or complete compatible kit has been verified. These are budgeting numbers, not a vendor quote.

The NANO includes an ESP32-C6 for Wi-Fi/Bluetooth, USB-C, and a MIPI camera connection. The P4 chip itself does not include Wi-Fi. The board's documented camera examples use other sensors, including OV5647. The reference files below are for this particular NANO board; do not substitute another P4 variant without checking its schematic and firmware support.

## What the optional sensors do

- **Ambient light sensor:** measures room brightness. Sample it before the photo lights turn on, and give it a window or position that limits glare from the device's own lights. It can help choose a lighting preset; camera exposure still needs control.
- **Accelerometer:** measures the direction of gravity while stationary, enough to decide which way is up and rotate a photo. A gyroscope is unnecessary for that basic use. It does not determine compass heading, and motion can temporarily disturb its tilt reading.
- Both recommended breakouts support I²C, allowing shared data/clock wiring with suitable free GPIOs. Final pins and bus pull-ups depend on the processor-board schematic. No pin assignment has been approved yet.

## Physical arrangement

Mount the purchased processor board behind the camera/light faceplate. Run the original camera ribbon directly to a compatible CSI connection. Put white LEDs around the camera opening, with a snap-in diffuser above them and the separate RGB status LED/button accessible from outside. A small two-layer controls/light carrier can be considered after the camera and lights work on the bench.

Keep a proper current-regulated light driver and check pulse duration, power supply capacity, and LED temperature. A short flash reduces average heat, but does not eliminate peak current or thermal limits. The Temu CL651-3S image alone does not establish its electrical ratings; it is not a qualified lighting part in this budget.

## Saved references and sources

- [Waveshare NANO product](https://www.waveshare.com/esp32-p4-nano.htm)
- [Waveshare NANO documentation](https://docs.waveshare.com/ESP32-P4-NANO)
- [Official resources and examples](https://docs.waveshare.com/ESP32-P4-NANO/Resources-And-Documents)
- [Downloaded official schematic](reference/ESP32-P4-NANO-schematic.pdf), fetched from https://files.waveshare.com/wiki/ESP32-P4-NANO/ESP32-P4-NANO-schematic.pdf. Vendor reference PDF; not an editable KiCad design or a verified redistribution license for manufacturing copies.
- [Adafruit VEML7700 breakout #4162](https://www.adafruit.com/product/4162)
- [Adafruit LIS3DH breakout #2809](https://www.adafruit.com/product/2809)
- [Custom board quote findings](../pcb-p4/quotes/2026-09-14/quote-findings.md)

## Next engineering work

1. Establish a supported path for the IMX519's required still resolution before committing to a processor board.
2. Select and bench-test a white LED/driver combination, then measure required pulse power and diffusion.
3. Assign free GPIOs and make a wiring diagram for RGB, button, and optional sensors.
4. Measure the purchased boards and camera to design the new enclosure and snap-in diffuser.

No parts have been purchased and no fabrication order has been placed.

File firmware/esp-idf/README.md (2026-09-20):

# Daily Mirror camera firmware

One ESP-IDF project, two boards, a board-adapter layer between them.

| Board | `MIRROR_BOARD` | Camera | Focus | Status LED | Wi-Fi |
| --- | --- | --- | --- | --- | --- |
| Waveshare ESP32-P4-WIFI6 | `p4_imx519` | Arducam IMX519 over MIPI-CSI (esp_video + ISP), 1920×1080, hardware JPEG | AK7375 VCM, continuous contrast-detect AF in the ISP | discrete RGB LED on three LEDC PWM channels | ESP32-C6 over esp_hosted/SDIO |
| Freenove ESP32-S3-WROOM CAM | `s3_ov5640` | OV5640 over DVP (esp32-camera), 1600×1200, JPEG from the sensor | OV5640 MCU firmware blob, single-shot AF | one WS2812 | on-chip |

Everything above the adapter is shared: `app_main`, the press flow, the admin
HTTP server, the uploader, Wi-Fi bring-up with a SoftAP fallback, settings and
mDNS.

---

## Build

```sh
source ~/esp/esp-idf/export.sh            # ESP-IDF v5.5.5

idf.py -B build_p4 -DMIRROR_BOARD=p4_imx519 build
idf.py -B build_s3 -DMIRROR_BOARD=s3_ov5640 build
```

or, from the repository root, `just fw-build-p4` / `just fw-build-s3`.

### How the board is chosen

`-DMIRROR_BOARD=<name>`, and nothing else. It is a cached CMake variable, so it
only has to be passed the first time a build directory is configured; after
that `idf.py -B build_p4 build` is enough.

One variable sets three things that must not drift apart, in
`firmware/CMakeLists.txt` before `project()`:

1. `IDF_TARGET` — `esp32p4` or `esp32s3`.
2. `SDKCONFIG_DEFAULTS` — `sdkconfig.defaults` then
   `boards/<board>/sdkconfig.defaults`.
3. The Kconfig choice `MIRROR_BOARD_*`, set in that per-board defaults file.
   `components/mirror_board/CMakeLists.txt` compiles exactly one
   `src/board_*.c` from it.

`sdkconfig` is written **into the build directory**, so the two boards'
configurations coexist and building one never invalidates the other.
`dependencies.lock` cannot be redirected the same way — the component manager
insists on writing it beside the manifest — so it lives in `firmware/`, is
rewritten whenever you switch boards, and is git-ignored.

Both are ignored along with `build*/`, `managed_components/` and anything named
`wifi_credentials.h` or `*.sdkconfig`; see `.gitignore`.

### Credentials, and why none are in this directory

A device with no settings comes up on its own setup network and is configured
through `/config`. Nothing in the repository ever needs an SSID, a password or
a token.

For a bench unit that should land straight on the house network, put the
build-time defaults in a file **outside the repository** and point at it:

```sh
# ~/esp/bench.sdkconfig — never inside the repo
CONFIG_MIRROR_DEFAULT_WIFI_SSID="..."
CONFIG_MIRROR_DEFAULT_WIFI_PASS="..."
CONFIG_MIRROR_DEFAULT_SERVER_URL="https://..."
CONFIG_MIRROR_DEFAULT_UPLOAD_TOKEN="..."

idf.py -B build_p4 -DMIRROR_BOARD=p4_imx519 \
       -DMIRROR_EXTRA_SDKCONFIG=~/esp/bench.sdkconfig build
```

It is applied last, after the board defaults. The build refuses a path inside
the repository. Note these are **build-time fallbacks only**: anything stored
through `/config` wins, and they are baked into the image in plain text, so
they are for the bench, not for a product.

## Flash and monitor

```sh
cd build_p4 && python -m esptool --chip esp32p4 -p /dev/ttyACM0 -b 921600 \
    --before default_reset --after hard_reset write_flash "@flash_args"
cd build_s3 && python -m esptool --chip esp32s3 -p /dev/ttyUSB0 -b 921600 \
    --before default_reset --after hard_reset write_flash "@flash_args"
```

**Always check the output for `Hash of data verified`.** A failed write is not
loud: the board simply keeps running the previous firmware, and you spend the
next hour debugging code that is not on it.

Console baud is **2,000,000** on the P4 (CH343 bridge) and **921,600** on the
S3 (CH340). `just fw-monitor-p4` / `just fw-monitor-s3`.

On a machine whose user is not in the serial group for this session, prefix
serial commands with `newgrp`:

```sh
echo '<command>' | newgrp uucp
```

## What it does

Start-up order is `log ring → settings → LED → camera → network → server →
mDNS → upload spool → button`.
The camera comes up before the network so the ISP's AE/AWB/AF convergence,
which needs a few seconds of frames, overlaps the Wi-Fi association instead of
following it. A camera that fails to initialise does **not** stop the rest:
`/config` is how someone fixes whatever is wrong, so it has to be served.

### Endpoints (port 80)

| | |
| --- | --- |
| `GET /` | status page, titled with the board name |
| `GET /snapshot.jpg` | focus, capture, send — the live scene |
| `GET /last.jpg` | the last committed press photo |
| `POST /press` | run the press flow |
| `POST /upload` | capture straight into the upload spool |
| `GET /stats` | plain text: board, camera, network, heap, and the spool |
| `GET /logs` | plain text: the last ~8 KB of the console log |
| `POST /debug/upload-block?on=1` | make every upload fail, for testing retry |
| `GET /config`, `POST /config` | the settings form, from `mirror_config` |

### The press flow

The Pi's, on this hardware (`device/src/main.rs`; pattern names from
`crates/mirror-core/src/ring.rs`):

```
countdown  AmberSlowPulse       4 × 350 ms on / 650 ms off — focus, AE/AWB
                                settle and the frame flush all run UNDER these
shutter    WhiteFlash           160 ms, at the instant the frame is taken
error      RedTriplePulse       then back to whatever is underneath

uploading  GreenSlowPulse       the spool has work in hand
sent       GreenTripleFlash     once, when the queue empties
ready      SolidWhite
```

Button: active low to GND with the internal pull-up, 60 ms debounce, 20 ms
poll. The press ends when the photo is on flash; the upload is not part of it.

**Deliberate divergences from `crates/mirror-core/src/ring.rs`**, both about
making one glance answer one question:

- Uploading is **green**, not `BlueSlowPulse`. Blue keeps its other meaning —
  joining a network, claiming — so the ring distinguishes "talking to the
  network to get set up" from "your photo is on its way".
- There is no `GreenFlash` at commit. The white shutter flash is the cue that
  the photo was taken, and a second flash a moment later read as noise.

The old flow put `AmberRapidPulse` *after* the countdown while autofocus and
the frame flush ran — about three seconds of fast blinking between "3, 2, 1"
and the actual photograph, so the countdown counted down to nothing. That work
now happens during the blinks, with `board_camera_prepare()` given the
countdown as a budget: if focus has not locked by the last blink the shutter
fires anyway and `af_state` records `searching`.

**Layers.** `mirror_ring` renders the topmost active layer of BASE (idle,
pairing, claiming), UPLOAD (the spool) and CAPTURE (a press), so a press
pre-empts the upload pulse instantly and the pulse resumes by itself
afterwards, with no caller having to know what to restore. Pairing patterns on
BASE outrank UPLOAD — "press the button to confirm" must not be painted over
by a photo going out — and do not need to outrank CAPTURE, because
`mirror_pair_confirm()` swallows the press before a capture can start. A
second press during a countdown is ignored (`mirror_press_busy()`); a press
while an upload is in flight starts its countdown immediately, since the
spool's lock is held only while a file is written, never across an upload.

### Networking

Station from the stored SSID, retrying **forever** — 1 s for the first five
attempts, then 10 s. If there is no SSID, or no address within
`MIRROR_STA_TIMEOUT_S` (60 s), the device also brings up a setup access point:

- SSID `mirror-<last 3 MAC bytes>`, the same name mDNS publishes.
- **10.10.0.1/24**, not Espressif's default 192.168.4.0/24 — this household's
  LAN is 192.168.4.0/22 and the two would overlap, leaving a phone that knows
  both networks able to reach neither reliably.
- WPA2 with `MIRROR_AP_PASSWORD`, default **`dailymirror`** (set it under
  *Daily Mirror application* in menuconfig). Under 8 characters and the network
  comes up open. This is a bench default in plain sight, not a secret; a
  shipping product should derive a per-device password.
- The same admin server, so `/config` is reachable at
  `http://10.10.0.1/config`.
- With an SSID stored the mode is APSTA, so the station keeps trying
  underneath and the device rejoins on its own once the credentials or the
  router are fixed.

### Uploads

`POST {server_url}/api/uploads` with `Authorization: Bearer <upload_token>` →
grant `{url, method, headers, complete_url}` → PUT/POST the JPEG with the
grant's headers → `POST complete_url`. The same contract as the Pi. The bearer
token is attached to the second step **only when the target is the same origin
as `server_url`**, so a signed object-storage URL never sees it.

TLS verifies against the certificate bundle (`esp_crt_bundle_attach`). The
bench firmware this came from used `CONFIG_ESP_TLS_SKIP_SERVER_CERT_VERIFY`;
that is deliberately gone.

The JPEG is streamed to the grant's URL from the spool file in 8 KB chunks out
of PSRAM. That is not tuning: the internal-heap low-water mark across a TLS
upload is around 50-70 KB, and a 386 KB JPEG held in internal RAM alongside
mbedTLS' buffers does not fit.

The grant body carries an optional `capture` object with the provenance of
that frame — see **The upload spool** below.

### The upload spool

`mirror_spool.c`, on a 3.5 MB LittleFS partition in the flash tail. Every
capture is written there first; a single drain task sends them oldest-first,
one at a time.

- **Retry.** 30 s doubling to 15 min, ±20% jitter, reset on
  `IP_EVENT_STA_GOT_IP` — the failure is nearly always the network having been
  away, and once it is back there is no reason to sit out the rest of a
  fifteen-minute backoff.
- **Power loss.** Entries are written to `tmp.dm` and renamed into `q/`, so a
  file under `q/` was written all the way through. Start-up deletes a stale
  `tmp.dm` and discards anything too short to hold a header.
- **Full.** The *oldest* entry is dropped and counted in `drops`. Roughly a
  dozen 1600×1200 JPEGs fit.
- **No clock, no upload.** A capture taken before SNTP answered would be filed
  under 1970, which the server rejects, so it is held and stamped with the
  time the clock first becomes valid.
- **4xx is not "retry forever".** `401`/`403` stops the drain entirely and
  shows `token_bad=1` in `/stats` — every photo is kept, because retrying
  cannot help and deleting would not be ours to do. `400`/`409`/`413` moves
  that one photo to `r/` (at most 2 kept) so one bad file cannot wedge the
  queue behind it. Everything else retries.

`/stats` reports `spool_count`, `spool_bytes`, `spool_capacity`,
`oldest_age_s`, `uploads_ok`, `uploads_failed`, `drops`, `rejected`,
`next_retry_s`, `last_http_status`, `last_error`, `token_bad`, and the last
capture's metadata.

To test the retry path without touching the stored claim:

```sh
curl -X POST 'http://mirror-4a30e4.local/debug/upload-block?on=1'   # photos pile up
curl -X POST 'http://mirror-4a30e4.local/debug/upload-block?on=0'   # they drain, in order
```

It is RAM-only, so a reboot clears it, and it can only make uploads fail.

### Capture metadata

The `capture` object on the grant request, all fields optional — anything the
board cannot read is **omitted**, never guessed:

```json
{"firmware_version":"0d4bb7b","sensor":"ov5640","width":1600,"height":1200,
 "jpeg_quality":89,"exposure_us":100682,"analog_gain":2.250,"mean_luma":34,
 "af_state":"focused","trigger":"button","capture_source":"device",
 "captured_at":"2026-09-20T03:16:03Z"}
```

The sensor registers are read in the board adapter immediately after the frame
is grabbed, behind `board_camera_capture_info_t`, so they describe *that*
frame — auto-exposure moves between frames. The S3 reads exposure
(`0x3500-0x3502`), gain (`0x350A/0x350B`), mean luma (`0x56A1`) and the AF
firmware status (`0x3029`); the P4 adapter returns "unknown" for all of them
for now, because on that board they live inside the ISP's closed-loop 3A
rather than in sensor status registers.

**The exposure line time is measured, not derived.** The OV5640's exposure is
in sixteenths of a row, and the row time is `HTS / (the sensor array clock)` —
which is *not* the DVP PCLK, and the PLL formula in esp32-camera's
`calc_sysclk()` gives an answer that is out by exactly 2×. So `board_s3_ov5640.c`
times six frames at start-up and divides by VTS. On this bench, at
1600×1200 JPEG:

| | |
| --- | --- |
| HTS / VTS | 2844 / 1968 |
| register-derived (`HTS/PCLK`, PCLK 12.5 MHz) | 227.52 µs |
| **measured** (223.9 ms frame / 1968 rows) | **113.77 µs** |

The measured figure implies a 25 MHz array clock, i.e. 2× the DVP PCLK, which
is what the datasheet's 8-bit DVP output mode does. The measurement is used;
the derived value is logged next to it so the two can be compared in the
field. Both appear in `/logs` on every boot.

### /logs

`esp_log_set_vprintf` tees the last 8 KB of log text into a PSRAM ring, served
as `text/plain` at `GET /logs`; serial output is unchanged. ISR context is
skipped (PSRAM is unreachable with the cache off) and the ring is guarded by a
spinlock rather than a mutex, because the log macros are reachable from an
ISR. The boot banner carries the firmware version, the reset reason and the
clock state.

No credential is ever logged: presigned URLs are printed with their query
string replaced by `?<redacted>`, and neither the device token, the Wi-Fi
password nor a claim token appears in any log line.

## Configuration

`idf.py -B build_p4 menuconfig`, under:

- **Daily Mirror board** — the board choice, button GPIO, JPEG quality, LED
  pins, camera pins, and the capture flash. Every pin below is a Kconfig
  option with these defaults.

The **capture flash** is `MIRROR_FLASH_GPIO`, **GPIO 47** on the S3 (`-1`, and
so disabled, on the P4). It comes on for the last `MIRROR_FLASH_LEAD_MS`
(1500 ms) of the press countdown and goes off the instant the frame is in
hand. That lead is not padding: the frame flush that settles auto-exposure
runs *after* the light is on, so AE meters the lit room rather than the dark
one, and the light is held rather than strobed because a pulse shorter than a
frame lights only part of a rolling-shutter readout — both written up in
`docs/burst-processing-experiment.md`. The board layer arms a 6 s one-shot on
every turn-on and the pin is driven off at start-up, so no error path, abort or
reset can leave the light on. `board_flash_set_level()` already takes a 0–255
level, so LEDC dimming drops in when the MOSFET stage arrives.
- **Daily Mirror application** — firmware version, station timeout, AP
  password, `MIRROR_DEBUG_ISP_STATS`.
- **Daily Mirror settings defaults** — the `MIRROR_DEFAULT_*` fallbacks.
- **Camera Sensor (IMX add-on)** — IMX519 mode index, `CAMERA_IMX519_DEBUG_LOG`.

### Wiring

**ESP32-P4 + IMX519**

| Signal | GPIO |
| --- | --- |
| Camera I2C SDA / SCL | 7 / 8 (IMX519 at 0x1a, AK7375 VCM at 0x0c) |
| RGB LED R / G / B | 21 / 22 / 23, one 330 Ω per colour, LEDC PWM |
| LED common leg | 3V3 — `MIRROR_LED_COMMON_ANODE=y` (outputs inverted) |
| Button | 20, to GND |
| Console UART | 37 / 38 at 2,000,000 baud |

Taken on this board and not available: 7/8 camera I2C, 9–13 + 53 I2S, 14–19 +
54 the C6 link, 24/25 USB, 37/38 UART, 39–44 SD. Check any change against the
header silkscreen.

**ESP32-S3 + OV5640** (Freenove ESP32-S3-WROOM CAM)

| Signal | GPIO |
| --- | --- |
| XCLK | 15 |
| SCCB SDA / SCL | 4 / 5 |
| D0…D7 | 11, 9, 8, 10, 12, 18, 17, 16 |
| VSYNC / HREF / PCLK | 6 / 7 / 13 |
| WS2812 | 48 |
| Button | 1, to GND |

The module is mounted upside down on the bench rig, hence `MIRROR_CAM_VFLIP=y`.

### Debug aids (off by default, not deleted)

- `MIRROR_DEBUG_ISP_STATS` — esp_ipa and esp_video at DEBUG: every exposure
  decision, white-balance gain and focus score. This is how the IMX519's focus
  band and the purple-blacks pedestal were found. P4 only in practice.
- `CAMERA_IMX519_DEBUG_LOG` — the sensor-side exposure and gain writes.

## Partitions

`partitions.csv`, one table for both boards: `nvs`, `phy_init`, `otadata`, two
6 MB OTA app slots, and a 3.5 MB `spool` LittleFS partition. There is no OTA
client yet; the layout is laid down now because changing a partition table
later means erasing NVS and losing every deployed device's settings. 15.6 MB
total, which fits the smaller board (16 MB on the S3, 32 MB on the P4).

```
nvs        data  nvs       0x009000    24K
phy_init   data  phy       0x00f000     4K
otadata    data  ota       0x010000     8K
ota_0      app   ota_0     0x020000     6M
ota_1      app   ota_1     0x620000     6M
spool      data  littlefs  0xc20000  3584K
```

`spool` was **appended** into flash that was already unallocated, so every
offset above it is byte for byte what it was. That matters: `nvs` holds the
`device_token` a claim issued, and moving it by one byte un-claims every
device in the field. Flashing the new table writes only the sector at
`0x8000`, which ends exactly where `nvs` begins.

## Adding a new board

Everything hardware-specific is behind `mirror_board.h`. The app in `main/`
never includes `esp_camera`, `esp_video`, `led_strip` or `ledc`, so a new board
is one adapter file, one defaults file, and a checklist.

### 1. The adapter: `components/mirror_board/src/board_<name>.c`

Four pieces, and nothing else:

| piece | functions |
| --- | --- |
| identity | `board_name`, `board_id` |
| camera | `board_camera_init`, `board_camera_prepare_focus`, `board_camera_prepare_settle`, `board_camera_capture`, `board_camera_release`, `board_camera_last_size`, `board_camera_capture_info`, `board_camera_status` |
| button | `board_button_gpio` |
| signal LED | `board_led_init`, `board_led_set_rgb` |
| capture flash | `board_flash_init`, `board_flash_available`, `board_flash_set`, `board_flash_on` |
| radio | `board_net_init` |

Every one must exist even when the hardware does not — a board with no flash
returns `false` from `board_flash_available()` and makes the other three
no-ops, which is exactly what `board_p4_imx519.c` does. Return "unknown"
values from `board_camera_capture_info()` rather than zeros: a missing field is
omitted from the upload, a fabricated one is a lie nothing downstream can see
through.

`board_camera_prepare_focus()` and `board_camera_prepare_settle()` are split
because the flash comes on between them (see **The press flow**). A board whose
pipeline runs continuously, like the P4's, can leave both empty.

### 2. `boards/<name>/sdkconfig.defaults`

The one file that carries values. `components/mirror_board/Kconfig` only
*declares* options, all defaulting to `-1` or `n`, so anything this file
forgets is absent rather than wrong. It sets:

- `CONFIG_IDF_TARGET` and `CONFIG_MIRROR_BOARD_<NAME>=y`.
- Every pin and polarity for the four pieces above.
- Flash size, and **PSRAM type and speed** — quad or octal, and the clock. The
  camera's frame buffers and the log ring live there; get this wrong and the
  symptom is an allocation failure a long way from the cause.
- Console UART baud, if the board's USB bridge will not take the default.
- **BLE**, if the chip has it: NimBLE plus
  `ESP_PROTOCOMM_SUPPORT_SECURITY_VERSION_2`. Without a Bluetooth radio
  `mirror_pair_start()` reports that the board cannot pair and the device has
  to be set up through `/config` on the fallback access point — a working
  path, but a different one, so decide it deliberately.

### 3. Wiring the name up

- `CMakeLists.txt`: add the name to `MIRROR_BOARDS` and map it to an
  `IDF_TARGET`.
- `components/mirror_board/CMakeLists.txt`: compile the new adapter under its
  `CONFIG_MIRROR_BOARD_*`.
- `justfile`: a `fw-build-<name>` / `fw-flash-<name>` pair, and a build
  directory of its own (`build_<short>`), since `sdkconfig` is per board and
  lives in the build directory.
- `partitions.csv` is shared. Check the **total fits the new board's flash**
  (15.6 MB today) and size the `spool` partition for it — it is the only
  partition that is a judgement call rather than a requirement.

### 4. Bring-up checklist

In this order; each step depends on the one before.

1. **Boots.** Serial shows the banner, the board name, and `boot: ... reset=`.
2. **`/stats`** answers: board id, camera line, IP, heap. `camera=` must not
   say "not started".
3. **Capture.** `POST /press` returns `captured`; `/last.jpg` is a whole image.
4. **Countdown and LED.** Four amber blinks, one white flash at the end, and
   the shutter on the last blink — `shutter at ~4000 ms` in the log.
5. **Flash**, if fitted: the light is on for the last 1.5 s and off straight
   after. Compare `mean_luma` / `exposure_us` in `/stats` `last_capture`
   against a capture with it disabled to confirm auto-exposure adapted.
6. **Pairing**, if the board has BLE: a long press enters it, the app finds it,
   and `/stats` ends at `claimed=1`.
7. **Upload.** A capture drains: `uploads_ok` increments and
   `last_http_status=204`.
8. **Spool under failure.** `POST /debug/upload-block?on=1`, two presses,
   watch `spool_count` rise with no attempts; reset the board and confirm the
   count survives; `?on=0` and watch it drain oldest-first.

### Standalone operation

The device is meant to run from a wall supply with nothing attached, so:

- **Nothing waits on the console.** Logging is plain UART with no flow control
  and the USB-serial-JTAG console is secondary, so an absent host is an absent
  reader, not a blocked writer. No code reads from stdin.
- **Brownout detection is on** (`CONFIG_ESP_BROWNOUT_DET`, level 7, plus
  `SPI_FLASH_BROWNOUT_RESET`) — a sagging USB supply resets the chip cleanly
  rather than corrupting flash mid-write.
- **Wi-Fi retries forever** (`mirror_net.c`): 1 s for the first five attempts,
  then 10 s, with no attempt limit. An access point that goes away overnight is
  rejoined on its own.
- **The spool outlives the outage.** Photos taken while the network is down sit
  on flash; `IP_EVENT_STA_GOT_IP` resets the retry backoff, so they start
  draining as soon as the address comes back rather than waiting out the
  remainder of a 15-minute timer.
- **A power cut costs nothing.** The queue is on LittleFS and entries are
  renamed into place, so start-up finds them and carries on.

## Traps

Every one of these cost hours on the bench.

- **The P4 on this rig is silicon rev v1.3.** ESP-IDF 5.5.5 defaults the
  minimum revision to v3.1 and esptool then refuses to flash at all
  (`requires chip revision in range [v3.1 - ...]`).
  `CONFIG_ESP32P4_SELECTS_REV_LESS_V3=y` and `CONFIG_ESP32P4_REV_MIN_100=y` are
  what make the image loadable.
- **The IPA JSON must be registered by the project CMakeLists**, between
  `include(project.cmake)` and `project()`. esp_ipa's own existence check is
  spelled `message(FETAL_ERROR ...)` — not a real CMake mode — so a wrong path
  prints a line, the build succeeds, and the camera runs with no auto-exposure
  and no white balance.
- **`idf.py fullclean` plus deleting `sdkconfig` and `dependencies.lock`** is
  the fix when configure fails with *"Missing required kconfig option after
  retry"*.
- **`vTaskDelay(pdMS_TO_TICKS(5))` is zero ticks at 100 Hz.** The OV5640 AF
  poll loops use `vTaskDelay(1)` for that reason, and the S3 build deliberately
  stays at the 100 Hz default — their iteration counts are tuned to 10 ms ticks.
- **The IMX519 module's VCM is an AK7375, not a DW9714/DW9807.** The DW97xx
  two-byte word protocol leaves the lens motionless and the focus sweep flat.
- **`Failed to detect camera sensor with address=1a` on the P4 is usually the
  ribbon**, which is marginal on this rig. Reboot once or twice before
  suspecting the firmware.
- **The IMX519 has no reset line**, so register state (e.g. a test pattern at
  0x0600) survives a reboot. The driver clears it in `set_format`.
- **`esp_read_mac(ESP_MAC_WIFI_STA)` fails on the P4 until the Wi-Fi driver has
  started** — the station MAC lives on the C6 — which is why the setup network
  is named after `esp_wifi_start()`, not before.
- **esp_hosted's SDIO mempool** does not fit alongside the camera stack at the
  default queue sizes, and the failure is the *idle task's* stack allocation
  returning NULL inside `vTaskStartScheduler`, before `app_main`, with nothing
  in the log mentioning Wi-Fi. Halved queue sizes fix it;
  `ESP_HOSTED_MEMPOOL_PREFER_SPIRAM` also boots but stalls every response
  larger than the initial congestion window.
- **esp_ipa ABI on older ESP-IDF**: below v5.4.4 / v5.5.3 the AWB sub-window
  macros are undefined, `esp_ipa_stats_t` is 400 bytes short of what the
  prebuilt library expects, and autofocus silently scores unrelated heap.
  `firmware/CMakeLists.txt` defines them for those versions.

## Layout

```
firmware/
  CMakeLists.txt              board selection, IPA JSON registration, ABI guard
  sdkconfig.defaults          common
  boards/<board>/sdkconfig.defaults
  partitions.csv              two OTA slots
  main/                       app_main, press flow, HTTP admin, uploader, net
  components/
    mirror_board/             the adapter interface + one src per board
    esp_cam_sensor_imx/       vendored IMX519 + AK7375 (see its README)
    mirror_config/            NVS settings and the /config form
    mirror_mdns/              mirror-xxxxxx.local and _dailymirror._tcp
```

## Licences

The project's own license is declared at the repository root. What in this
directory came from elsewhere, and under what terms, is recorded in
[NOTICE](NOTICE). The two items that need a decision before hardware is sold
are the GPL-2.0 IMX519 register tables and the OV5640 autofocus microcode;
both are described there and in `docs/firmware-roadmap.md`.

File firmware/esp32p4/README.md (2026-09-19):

# Daily Mirror ESP32-P4 firmware

The product target. An ESP32-P4 with a companion ESP32-C6 radio and an
Arducam IMX519 sensor, running the same `daily-mirror-core` state machine and
driver loop that `firmware/host` runs under `cargo test`.

**This crate does not compile without the ESP-IDF toolchain**, which is why it
is excluded from the firmware workspace (`../Cargo.toml`) and from
`just check`. Everything in `src/` is an adapter skeleton with `todo!()` where
the FFI goes; the logic it feeds is already written and already tested on the
host.

## Toolchain

```sh
# 1. The Rust toolchain for Espressif targets. The P4 is RISC-V, so the
#    xtensa fork is not strictly required, but espup installs ldproxy and the
#    export script either way.
cargo install espup --locked
espup install
. $HOME/export-esp.sh          # add this to your shell profile

# 2. ESP-IDF 5.3 or newer — the first release that supports the P4 and
#    esp_wifi_remote. `embuild` will fetch and cache it on the first build,
#    or point ESP_IDF_PATH at an existing checkout.
cargo install ldproxy --locked
cargo install espflash cargo-espflash --locked

# 3. Build and flash.
cargo build --release
cargo espflash flash --release --monitor
```

The target (`riscv32imafc-esp-espidf`) comes from `.cargo/config.toml`. Note
the `f` and `c`: the P4's core has the float and compressed extensions, and
the C3/C6 target `riscv32imc-esp-espidf` is a different, non-working target
that is easy to reach for by accident.

`cargo build` also needs nightly-style `build-std`, which the espup toolchain
provides. If the build complains about `std` for an unknown target, the export
script has not been sourced in that shell.

## What the files are

| File | Job |
| --- | --- |
| `Cargo.toml` | Crate plus the `esp-idf-sys` `extra_components` entries that pull the C libraries |
| `.cargo/config.toml` | Target, linker (`ldproxy`), runner (`espflash`), `MCU`, IDF version |
| `sdkconfig.defaults` | Hosted Wi-Fi, SoftAP provisioning, ISP and JPEG, PSRAM, partition table |
| `partitions.csv` | NVS, two OTA slots, a small FAT partition |
| `build.rs` | Hands the ESP-IDF build off to `embuild` |
| `bindings.h` | The C headers bindgen turns into the FFI surface |
| `components.yml` | The same component set in `idf.py` form, for debugging the C side alone |
| `src/*.rs` | One adapter per core trait, plus `main.rs` |

## Components

Four come from Espressif's registry and one from GitHub:

- `espressif/esp_hosted` and `espressif/esp_wifi_remote` — the P4 has no
  radio. `esp_wifi_remote` presents the ordinary `esp_wifi_*` API and
  forwards it over SDIO to the C6.
- `espressif/network_provisioning` — SoftAP provisioning, the Curve25519
  handshake with proof of possession, and the custom endpoint carrying the
  claim token. BLE is the better first-run experience, but P4 BLE
  provisioning is unfinished upstream; when it lands it is a scheme swap in
  `net.rs` and one line in `sdkconfig.defaults`, with no protocol change.
- `espressif/esp_video` — MIPI CSI capture, the ISP pipeline, hardware JPEG.
- [`NB11B/esp32p4-imx519-driver`](https://github.com/NB11B/esp32p4-imx519-driver)
  — the IMX519 is not one of the sixteen sensors in `esp_cam_sensor`. This
  community port carries register tables derived from the Raspberry Pi kernel
  driver and drives the DW9714 focus motor directly. **It is GPL-derived;
  review the licence before shipping firmware built on it.**

## Bring-up order

Each step is independently verifiable, and each one that fails fails visibly
on the ring. Do not skip ahead — the camera is last for a reason.

1. **Ring and long-press.** `clock.rs`, `button.rs`, `ring.rs`. No network, no
   storage. Success: the ring breathes dim white, fills amber from 2 s into a
   hold, and goes amber-chase at 5 s. This is also the whole of the
   "the button works before Wi-Fi exists" requirement.
2. **Hosted Wi-Fi join.** `net.rs`, `HostedNet::new` and `join`, with
   credentials hard-coded. Success: an IP address in the monitor log. If this
   does not work, nothing after it can.
3. **SoftAP provisioning.** `start_provisioning`, `poll_credentials`,
   `report`. Success: the phone finds `DailyMirror-<suffix>`, completes the
   handshake, and the device reaches `AwaitingConfirm` with the ring pulsing
   amber fast. Espressif's stock SoftAP example is the fallback comparison if
   the app side is in doubt.
4. **Claim.** `claim`, plus `store.rs` NVS read and write. Success: a device
   token in NVS, the ring solid white, and the device visible in the
   household. Power-cycle: it must come back Ready without pairing again.
5. **Fixture upload.** Build with `--features fixture-camera` so `capture`
   returns a JPEG flashed into the image. This exercises the queue, the
   grant / PUT / complete sequence, and the per-device bearer token with no
   camera on the bench. Success: the photograph appears in the gallery.
6. **Camera.** `camera.rs`. Write the standalone probe first — initialize the
   IMX519, set focus, write one 1080p frame to the SD card — and only then
   wire it into the loop.

## IMX519 and 1080p

- The P4's ISP caps at **1920×1080**. That is the product resolution for v1;
  full-resolution raw bypass is not available.
- The sensor's binned mode runs at video rate, which makes burst capture cheap
  later: one press, several frames, one capture id, and the server picks the
  sharpest or stacks them. Firmware-wise that is "upload N JPEGs under one
  capture id" and needs no protocol change.
- Focus is driven directly through the DW9714 voice-coil motor over I²C, so
  the Pi rig's focus work transfers. That work's conclusion stands: autofocus
  was never the problem, low light was. Budget for the light before blaming
  the lens.
- A 1080p JPEG plus the frame buffers does not fit in internal RAM. PSRAM is
  enabled in `sdkconfig.defaults` and is not optional.

## What cannot be verified off the board

| Layer | Off-board | Confidence |
| --- | --- | --- |
| State machine, pairing, queue, upload | `firmware/host` + `cargo test` | High — this is where the bugs live, and it is covered |
| Wi-Fi join, HTTP upload, NVS | Wokwi P4, beta, virtual access point | Medium, smoke only |
| SoftAP provisioning | Wokwi's simulated hosted co-processor | Medium, smoke only |
| BLE provisioning | Nowhere; unsupported upstream on the P4 | None |
| Camera | Nowhere | None |

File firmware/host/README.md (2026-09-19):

# Daily Mirror host firmware

The device firmware, running on Linux. Same `daily-mirror-core` state machine,
same driver loop, same upload protocol as the board — only the six adapters
differ. This is where the pairing flow is developed and where CI proves it
still works.

```sh
cargo run -- --store /tmp/mirror --fixture ../../feed.jpg --port 8088
```

Type at it:

| Key | Effect |
| --- | --- |
| `p` / `r` | press and release the button |
| `c` | a short click — capture, or confirm a pairing |
| `hold 5000` | enter pairing |
| `hold 20000` then `c` `c` `c` | full reset |
| `q` | quit |

The ring prints one timestamped line per change. Send credentials the way the
app would:

```sh
curl -X POST http://127.0.0.1:8088/provision \
  -H 'content-type: application/json' \
  -d '{"ssid":"home","psk":"secret","server_url":"http://127.0.0.1:3000","claim_token":"ct_..."}'
```

Get a claim token from a signed-in session with
`POST /api/devices/claim-tokens`. `GET /` on the provisioning port reports the
device id, and `GET /status` reports what the device last said about pairing.

## Scripts

`--script` replays timestamped events against a virtual clock, so a five-minute
pairing timeout costs nothing:

```sh
cargo run -- --script scripts/happy-path.txt --store /tmp/mirror-script
```

See `scripts/` for the format. The integration tests in `tests/pairing.rs` use
the same parser and driver against a mock server built on `std::net`.

## Adapters

| Trait | Here | On the P4 |
| --- | --- | --- |
| `Clock` | `std::time::Instant`, or a virtual clock | `esp_timer_get_time` |
| `Button` | stdin | GPIO 4, active low |
| `Ring` | terminal | WS2812 over RMT |
| `Camera` | a fixture JPEG | IMX519 through `esp_video` |
| `Store` | a directory | NVS plus an SD card |
| `Net` | `reqwest` + a local HTTP provisioning link | `esp_wifi_remote` + SoftAP provisioning |

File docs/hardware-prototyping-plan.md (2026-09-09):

# Daily Mirror hardware prototyping plan

> Current next-version direction (2026-09-05): Raspberry Pi 4 Model B,
> a camera mount, and one probably-white LED. Follow
> [the next enclosure plan](next-enclosure-plan.md) for the immediate build.
> The RGB ring and illuminated-button requirements below are earlier proposals,
> not requirements for this version.

## Goal

Turn the working Raspberry Pi, IMX519 camera, pushbutton, and loose LED wiring
into a dependable enclosed appliance. The finished front face should expose
only two intentional features:

1. the camera lens through a fitted bezel; and
2. one illuminated, multicolor pushbutton or a button surrounded by an RGB
   ring.

Power should enter through the rear or bottom. The Pi, wiring, connectors,
resistors, level shifter, fasteners, and service access should be hidden inside.
This plan deliberately keeps the Raspberry Pi and proven software through the
first enclosed versions. A smaller compute platform is a later product decision,
not a prerequisite for eliminating jumper wires.

## The shortest path away from jumper wires

Do not jump directly from a breadboard to a custom PCB. Build one soldered
carrier on perfboard first. That version establishes the real wire lengths,
connector locations, mounting-hole pattern, thermal behavior, and enclosure
dimensions. Those facts become the input to the PCB rather than guesses made
in CAD.

Use this progression:

```text
breadboard proof
  → soldered perfboard + locking connectors
  → enclosed engineering prototype
  → custom Pi carrier PCB
  → refined enclosure + small pilot batch
```

## Target physical architecture

### Front assembly

- A rigid camera bracket locates the IMX519 module independently of the Pi.
- The lens sits in an open, matte-black bezel. Do not put ordinary acrylic in
  the optical path. Add an anti-reflection optical window only if impact or dust
  protection proves necessary.
- A panel-mount momentary button provides the only user control.
- An addressable RGB ring around that button provides every visible status.
  This replaces the separate green, yellow, and red LEDs.
- A short internal light baffle prevents the RGB ring from reflecting into the
  lens.

### Internal assembly

- The Raspberry Pi mounts on threaded standoffs to a removable internal plate.
- A small carrier board handles the button connector, RGB data-level shifting,
  power distribution, and test points.
- The camera ribbon is folded only within its specified bend radius and is
  retained so enclosure service cannot pull on the camera connector.
- Internal cable connections use keyed or locking connectors. Dupont jumper
  sockets are not acceptable after the perfboard phase.
- Power enters through a rear/bottom panel opening with strain relief. No bare
  power conductors or inline breadboard adapters remain inside.
- Vent slots are hidden on the bottom and upper rear to create a passive airflow
  path without exposing the electronics from the front.

## Electrical baseline

The current software uses BCM GPIO 2 for the active-low button and GPIO 17, 27,
and 22 for three active-high LEDs. During the perfboard phase, keep that working
interface unchanged so mechanical work can be tested without a simultaneous
software rewrite.

The RGB-button conversion is a separate, measured step:

- Button contacts: GPIO input to ground, using the Pi's internal pull-up.
- RGB ring: 5 V, ground, and one addressable data signal.
- Data signal: one 3.3 V-to-5 V logic-level shifter channel designed for a fast
  digital signal; do not rely on a direct 3.3 V connection in the enclosed unit.
- Add local bulk and ceramic decoupling at the ring connector.
- Add an inline data resistor near the level shifter output.
- Use a shared ground and size the 5 V wiring for Pi peak load plus the RGB ring
  at its configured brightness limit.
- Keep labeled test pads for 5 V, 3.3 V, ground, button, and RGB data.

Before ordering a PCB, update the device software to represent status as one
logical RGB output and verify every capture state on the actual ring. Keep the
three-LED implementation available behind a configuration choice until the new
hardware has completed a soak test.

## Phase 0 — freeze and document the working breadboard

**Purpose:** preserve a known-good reference before changing the mechanics.

Tasks:

- Photograph both sides of the working assembly and every Pi header connection.
- Draw a wiring schematic with GPIO names, resistor values, LED polarity, button
  contacts, power rails, and connector orientation.
- Record the exact Pi model, IMX519 board revision, camera ribbon length, power
  supply rating, button dimensions, and current LED part numbers.
- Measure the maximum current at idle, during autofocus/capture, during upload,
  and with all status LEDs active.
- Save one known-good capture and record focus, orientation, temperature, and
  software version.
- Label the current wiring physically before removing anything.

Exit criteria:

- Another person could reconstruct the breadboard from the schematic and parts
  list.
- A capture, offline queue, retry, reboot, and error indication all pass.

## Phase 1 — soldered bench prototype

**Purpose:** remove intermittent jumper-wire connections without yet solving
the final enclosure.

Build a small perfboard carrier with:

- a keyed cable or terminal block to the button/LED assembly;
- a short keyed harness to the Pi GPIO header;
- soldered current-limiting resistors and power distribution;
- strain relief for every wire leaving the board;
- mounting holes or adhesive standoffs; and
- labeled test points.

Use crimped connectors where parts must be removable and soldered joints with
heat-shrink where they do not. Use consistent wire colors and create a simple
harness drawing with pin numbers. Do not solder wires directly to the Pi or the
camera module.

Exit criteria:

- No breadboard or loose Dupont jumpers remain.
- The assembly survives being picked up, rotated, and lightly shaken without a
  reboot, false button press, or LED flicker.
- Fifty consecutive button captures succeed.
- Unplugging and reconnecting every serviceable cable cannot reverse polarity
  or shift a connector by one pin.

## Phase 2 — enclosure geometry prototype

**Purpose:** determine layout, camera alignment, usability, thermals, and service
access with inexpensive, quickly revised parts.

Create a rough 3D-printed or laser-cut enclosure around the perfboard assembly.
Start with a two-part shell and a removable internal mounting plate. Avoid
designing decorative curves until the component locations work.

Mechanical experiments:

- Test camera height and angle in the intended wall location before fixing the
  lens opening.
- Print at least three lens-bezel depths to find the shortest baffle that blocks
  LED flare without reducing the field of view.
- Test whether the button is comfortable and obvious at the installed height.
- Verify that the enclosure can be opened without disturbing camera alignment.
- Provide access to the SD card only after opening the enclosure.
- Put power and any temporary service port on the rear/bottom, never the front.
- Measure CPU temperature after one hour idle and after repeated captures with
  the enclosure installed.
- Check Wi-Fi signal at the final wall position with the enclosure closed.

Exit criteria:

- The front shows only the lens and illuminated button/ring.
- The captured image has no enclosure obstruction, internal reflection, or RGB
  flare.
- The unit can run continuously for 24 hours without thermal throttling.
- The enclosure can be opened, serviced, and reassembled without tools touching
  the lens or changing framing.

## Phase 3 — enclosed engineering prototype

**Purpose:** make one unit that behaves like the intended appliance even though
it still uses perfboard internally.

Improvements over Phase 2:

- Use threaded inserts or captured nuts instead of screws driven repeatedly
  into printed plastic.
- Add a real wall plate, keyholes, or French-cleat-style mounting feature.
- Add power strain relief and a hidden hardware power-disconnect method.
- Use a matte, opaque interior around the camera.
- Secure the camera ribbon and every harness at both ends.
- Replace the three discrete LEDs with the selected RGB ring and enable the
  single-RGB software mode.
- Add an internal label with device ID, power requirement, GPIO/connector
  revision, and recovery URL.

Validation matrix:

| Test | Pass condition |
| --- | --- |
| Cold boot | Ready indication and admin health recover without intervention. |
| Network loss | Captures queue locally; red/error state is understandable. |
| Network return | Queue drains and gallery/Turso metadata appear exactly once. |
| Power interruption | No queue corruption; unit recovers on restored power. |
| Button abuse | Holds, double taps, and rapid presses produce no duplicate capture. |
| Thermal soak | 72 hours enclosed with periodic captures and no throttling. |
| Optical test | Day/night captures show no bezel clipping or LED reflections. |
| Mounting test | Removing and reinstalling the unit preserves framing. |

Exit criteria:

- The unit operates for one week in its real location without opening the case.
- All failures are diagnosable through LED behavior and the LAN admin page.
- A second person can install and power it using a one-page guide.

## Phase 4 — custom Pi carrier PCB

**Purpose:** replace hand-wired perfboard with a repeatable assembly after the
mechanical and electrical interfaces are proven.

The first PCB should remain intentionally boring. It is a carrier/interface
board, not a redesigned computer. Include:

- a keyed connection to the Pi GPIO header;
- a locking connector for the button and RGB ring;
- the 3.3 V-to-5 V data-level shifter;
- decoupling, the RGB data resistor, and conservative power traces;
- clearly labeled polarity and connector pin 1;
- test pads for all important rails and signals;
- mounting holes matching the proven internal plate; and
- board name, revision, date, and open-source schematic reference.

Before ordering:

- Have someone other than the designer review the schematic and connector
  pinout against the Phase 0 wiring record.
- Print the PCB at 1:1 scale and physically place the connectors, fasteners, and
  enclosure over it.
- Run electrical-rule and design-rule checks.
- Order a small quantity and assemble one board before committing the rest.

Exit criteria:

- Two independently assembled boards pass the Phase 3 validation matrix.
- No bodge wires or cut traces are required.
- Board replacement takes minutes and does not require soldering inside the
  enclosure.

## Phase 5 — pilot enclosure and small batch

**Purpose:** learn whether the design is repeatable, installable, and maintainable
beyond the original unit.

- Build three to five complete units using the same PCB, harness lengths,
  fasteners, image, and installation instructions.
- Create a manufacturing BOM with exact manufacturer part numbers and approved
  substitutions.
- Add a connector/harness drawing, assembly order, torque guidance where needed,
  and a final inspection checklist.
- Give each unit a unique device ID and record its Pi, camera, PCB, and enclosure
  revisions.
- Track assembly time and every step that requires rework or tribal knowledge.
- Install units in different lighting and Wi-Fi conditions for at least two
  weeks.

Exit criteria:

- All pilot units pass the same acceptance test without hand tuning.
- Assembly and service instructions work for someone who did not design it.
- Known thermal, optical, electrical, and mounting margins are documented.
- The remaining reasons to leave the Pi platform are cost, size, or supply—not
  unresolved prototype reliability.

## Parts and tools needed for the next phase

The immediate purchase/build list is deliberately for Phase 1 and Phase 2, not
for a production run:

- small plated perfboard;
- appropriately sized stranded hookup wire in consistent colors;
- keyed locking connector housings, crimp contacts, and matching headers;
- crimp tool matched to the selected contact family;
- heat-shrink tubing and cable lacing or small tie mounts;
- Pi-compatible standoffs and assorted M2/M2.5/M3 fasteners;
- panel-mount momentary button or the selected illuminated RGB button;
- addressable RGB ring if it is separate from the button;
- 3.3 V-to-5 V logic-level shifter and supporting passives;
- multimeter and, ideally, a basic logic analyzer;
- calipers for component and enclosure measurements;
- opaque black material or prints for lens-bezel experiments; and
- two or three inexpensive enclosure iterations rather than one polished print.

Do not order a custom PCB until the Phase 3 unit has completed its one-week
installed soak. Do not choose an ESP32 solely to make the enclosure smaller;
that changes the camera, software, storage, diagnostics, and update system at
the same time. First prove the physical product around the working Pi.

## Immediate next sprint

The next concrete milestone is **Phase 1: soldered bench prototype**.

1. Draw and review the current schematic.
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

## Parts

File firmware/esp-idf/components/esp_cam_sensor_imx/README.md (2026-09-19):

# esp_cam_sensor_imx (vendored, trimmed)

Sony **IMX519** MIPI-CSI driver plus the **AK7375** autofocus VCM for the
ESP32-P4, plugging into Espressif's `esp_cam_sensor` / `esp_video` framework.

This directory is a **vendored copy**, not original work. It is kept in-tree
rather than pulled from the component registry because the IMX519 and AK7375
sources here are local additions that have not been published upstream.

## Provenance

| Path | Origin | Licence |
| --- | --- | --- |
| `CMakeLists.txt`, `Kconfig`, component scaffolding | [mushBrainDave/esp32-p4-imx-camera](https://github.com/mushBrainDave/esp32-p4-imx-camera), `components/esp_cam_sensor_imx` | Apache-2.0 (`LICENSE`) |
| `sensors/imx519/imx519.c`, `include/imx519.h`, `private_include/imx519_regs.h`, `cfg/imx519_default.json` | Written for Daily Mirror against that project's driver skeleton | Apache-2.0 |
| `sensors/imx519/private_include/imx519_settings.h` | **Register tables taken verbatim from the Raspberry Pi Linux kernel driver** `drivers/media/i2c/imx519.c` (Arducam Technology / Raspberry Pi Ltd) | **GPL-2.0-only** |
| `motors/ak7375/*` | Written for Daily Mirror | Apache-2.0 |

### The GPL-2.0 register tables

`sensors/imx519/private_include/imx519_settings.h` carries
`SPDX-License-Identifier: GPL-2.0-only`. Its mode and common register arrays are
copied from the Raspberry Pi kernel's IMX519 driver. **Do not relicense that
file, and do not strip its SPDX header.** It means this component as a whole is
distributed as `Apache-2.0 AND GPL-2.0-only`, and anything linking the P4 image
inherits the GPL-2.0 obligation for those tables. If that becomes a problem for
a shipping product, the tables have to be re-derived from the sensor datasheet
rather than copied.

## What was dropped from upstream

Upstream also ships IMX219, IMX708 and the DW9807 VCM. None of them are used by
Daily Mirror, so their sources, Kconfig blocks, CMake branches, IPA JSON configs
and README sections are not present here. The upstream repository remains the
place to get them.

## Traps worth knowing

- **The IPA JSON must be registered by the *project* CMakeLists**, between
  `include(project.cmake)` and `project()` — see `firmware/CMakeLists.txt`.
  esp_ipa reads `ESP_IPA_JSON_CONFIG_FILE_PATH` while its own CMakeLists is
  processed, which is too late for a component to set it. Get it wrong and
  nothing errors: esp_ipa's own check is spelled `message(FETAL_ERROR ...)`,
  which is not a real CMake mode, so it prints and carries on, and you get a
  stream with no auto-exposure and no white balance.
- **The VCM on the Arducam IMX519 module is an AK7375, not a DW9714/DW9807.**
  A DW97xx-style two-byte word write leaves the lens motionless and the focus
  sweep flat. The AK7375 wants `code << 4` as a 16-bit write to register 0x00,
  with 0x00/0x40 in register 0x02 for active/standby.
- **The sensor has no reset line**, so register state (e.g. the 0x0600 test
  pattern) survives a reboot. The driver clears it in `set_format`.
- `CAMERA_IMX519_DEBUG_LOG` logs every exposure/gain write. Off by default.

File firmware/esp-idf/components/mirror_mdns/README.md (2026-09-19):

# mirror_mdns

LAN discovery: a `mirror-xxxxxx.local` hostname and a `_dailymirror._tcp` service
whose TXT records let the app match a device on the network to a device in the
household.

## API

See `include/mirror_mdns.h` for the authoritative contract.

| Function | Notes |
| --- | --- |
| `mirror_device_id(char out[13])` | 12 lowercase hex chars of the station MAC, NUL-terminated. |
| `mirror_mdns_start(info)` | Call after the network interface has an address. Safe to call twice: the second call updates the advertisement rather than failing. |
| `mirror_mdns_set_claimed(bool)` | Updates the `claimed` TXT item in place. Returns `ESP_ERR_INVALID_STATE` before `start()`. |
| `mirror_mdns_hostname()` | `"mirror-xxxxxx"` without `.local`; valid after `start()`. |

## What is advertised

- Hostname: `mirror-<last 3 MAC bytes, hex>` → `mirror-a1b2c3.local`
- Instance name: `Daily Mirror camera`
- Service `_dailymirror._tcp` on `info->http_port` (falling back to 80 if zero), TXT:
  - `id` — the 12-hex device id
  - `board` — `info->board`, e.g. `esp32p4-imx519`
  - `fw` — `info->fw_version`
  - `claimed` — `"0"` or `"1"`
- Service `_http._tcp` on the same port, no TXT.

Verify from a Linux host with:

```sh
avahi-browse -rpt _dailymirror._tcp
```

## MAC address, and the ESP32-P4

`mirror_device_id()` and the hostname both come from the station MAC, resolved in
this order:

1. `esp_read_mac(mac, ESP_MAC_WIFI_STA)` — the normal path on the ESP32-S3.
2. `esp_wifi_get_mac(WIFI_IF_STA, mac)` — ask the driver for the address the
   interface actually uses.
3. `esp_read_mac(mac, ESP_MAC_BASE)` — the host chip's own efuse MAC.

Step 1 **cannot succeed on the ESP32-P4**: the P4 has no radio of its own, so
`SOC_WIFI_SUPPORTED` is undefined and IDF's `generate_mac()` has no
`ESP_MAC_WIFI_STA` case, returning `ESP_ERR_NOT_SUPPORTED`. Step 2 is the one
that yields the real radio address there, via `esp_wifi_remote`/`esp_hosted`,
and it only answers once `esp_wifi_init()` has run — which is true by the time
`mirror_mdns_start()` is legitimately called.

Results from steps 1 and 2 are cached, so the id cannot change under a caller.
The step 3 fallback is deliberately *not* cached: calling `mirror_device_id()`
before Wi-Fi is up on a P4 would otherwise freeze the host chip's efuse MAC as
the device id for the whole boot, instead of upgrading to the radio's address.
If you need the id to match what the server sees, read it after Wi-Fi starts.

## Dependencies

The managed component `espressif/mdns` (`idf_component.yml`). Only public
`esp_wifi` / `esp_mac` APIs are used, so the same source builds for both the
ESP32-S3 and the ESP32-P4; there is no direct dependency on `esp_hosted`.

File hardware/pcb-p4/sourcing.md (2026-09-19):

# Sourced parts and open P4 designs

## What was imported

The A1 project adds **64 candidate component instances**, with **19 symbol types**
and **21 footprint types**, to the original 16-reference controls circuit. All
80 electrical references appear in the schematic and PCB. Component pin numbers
were compared against footprint pad numbers; J2 has additional mechanical `MP`
tabs, which are not ribbon contacts. Current P4 pin 54 is `VDD_HP_1`.

Main circuits are not yet wired. No no-connect markers were added to conceal that
work. ERC reports the open pins; DRC still reports unset USB connector nets,
silkscreen issues and connector hole spacing against provisional board rules.
Physical component courtyards no longer overlap. The checks are import and
placement checks, not an electrical or manufacturing approval.

| Function | Imported candidate | Status |
| --- | --- | --- |
| Processor | Espressif ESP32-P4NRW32X | Current P4X symbol, 32 MB in-package PSRAM; IMX519 capture unproven |
| Wi-Fi and phone pairing | ESP32-C6-MINI-1-N4 | Manufacturer footprint and STEP; SDIO/firmware/antenna integration pending |
| Firmware flash | Winbond W25Q128JVSIQ | 16 MiB, SOIC-8 5.3 mm package |
| USB-C | GCT USB4105-GF-A | Footprint and KiCad STEP; final stake-length/order suffix pending |
| USB current detection | TI TUSB320IRWBR | 5 V sink direction; detects advertised current, does not negotiate USB PD |
| Main 3.3 V supply | TI TPS62132RGTR | 3 A buck candidate; complete output network and load budget pending |
| P4 core supply | TI TLV62569DBVR | Requires P4 rev3+ feedback/control circuit |
| Camera supply switch | TI TPS22919DCKR | Confirm module current, rails and startup behavior |
| USB ESD | ST USBLC6-2SC6 | Data-line protection; input/CC protection still needs design |
| Camera ribbon connector | Molex 2005280150 | 15 contacts, 1 mm pitch, bottom contact; verify actual ribbon/module |
| White emitters, D2–D9 | Cree XPGDWT-U1-0000-00J3E | 5000 K, minimum 90 CRI, quantity eight provisional |
| White LED driver | TI TPS61165DBVR | Constant-current boost candidate; tentative eight in series at 100 mA for optical tests |
| Inductors | Coilcraft XAL4020-222MEC / XAL4040-103MEC | Initial package/value choices; regulator-loop and current calculations pending |
| Boost diode | Vishay SS16-E3/61T | 60 V Schottky candidate; peak current/loss checks pending |
| P4 crystal | Abracon ABM8-40.000MHZ-10-1-U-T | 40 MHz / 10 pF, manufacturer test report; current ordering/temperature qualification pending |
| Decoupling and resistors | Murata GRM / Yageo RC families | Candidate MPNs and packages recorded; quantities and values remain preliminary |
| Boot and reset | Two 6 mm tactile switch positions | Generic package; B3F-1000 is a documented 4.3 mm-high candidate |

The new parts, MPNs, source links and individual qualifications are in
[candidate-parts.csv](candidate-parts.csv). Existing controls are listed in
[parts.json](parts.json) and README. A complete order list cannot yet be frozen:
camera processor compatibility, protection/inrush circuitry, final support-part
counts, flash/SDIO series terminations, antenna clearances, and light power/thermal
requirements remain open. Inventory and assembler stocking were not confirmed.
No parts were purchased.

The older TPS62133 is **5 V output**, not the intended 3.3 V part; A1 uses
TPS62132. The TPS61165's **1.2 A rating is its switch rating**, not a promise of
1.2 A output at the boosted LED voltage. Actual output capability requires a
converter power/loss calculation. The MIPI PHY uses the P4's reference power
scheme; it is not an arbitrary external 1.8 V rail.

## Camera connector requested for this board

**J2 is the camera ribbon connector**, placed to the right of the camera mounting
area. Its board label is `CAMERA CSI / 15P`. The intended interface is the standard
Raspberry Pi-style **15-contact, 1 mm pitch FFC** camera connection, carrying
MIPI CSI-2 signals. The physical connector candidate is Molex 2005280150.
The camera sensor and lens remain on the purchased module, connected by ribbon.

[Raspberry Pi's connector documentation](https://www.raspberrypi.com/documentation/accessories/camera.html#camera-connector-pinout-15-pin)
distinguishes this standard connector from the smaller 22-pin connector on Pi 5
and Pi Zero boards. The chosen footprint is the standard 15-pin format. Electrical
pin assignment and cable contact orientation still need validation when the camera
circuit is connected; the matching format alone does not establish camera support.

## What R1–R7, C1, D1 and TP1–TP6 mean

| Marking | Explanation |
| --- | --- |
| D1 | Four-legged RGB indicator: three colors plus a shared positive leg. Mixing colors gives approximate white; the separate white LEDs illuminate photographs. |
| R1, R2, R3 | One series current-limiting resistor for each blue, green and red element. No resistor is needed on the shared fourth leg. |
| R4 | Pulls the button input high while the button is released. |
| R5, R6, R7 | Pull the three color-control signals high so the common-anode LED stays off while processor outputs are floating. |
| C1 | Button filter capacitor; R4/C1 form about a 1 ms filter. Firmware debounce is also needed. |
| TP1, TP2 | Exposed copper test pads for 3.3 V and ground. |
| TP3, TP4, TP5 | Test pads for blue, green and red control signals. |
| TP6 | Test pad for the button input. |

The old image had only one capacitor because only the button/indicator circuit
had been populated. C2–C28 now illustrate the main circuit's preliminary support
population. They are not connected to the required rails yet. Test pads are part
of the manufactured copper pattern, not six extra components to buy.

For the original controls, Yageo RC0603FR-071KL (1 kΩ), RC0603FR-0710KL (10 kΩ)
and RC0603FR-07100KL (100 kΩ), and Murata GRM188R71C104KA01D (100 nF), are package
candidates. The loose RGB LED's manufacturer and physical lead orientation are
still unknown; the existing symbol preserves the recorded B/G/common+/R order.

## 3D and library provenance

- KiCad symbol/footprint/package assets come from official **10.0.6** libraries.
- P4X and C6 symbol/footprint assets come from
  [Espressif's official KiCad library](https://github.com/espressif/kicad-libraries)
  at commit `dd76561812ab300351234ba6e0ec1295641796f0`.
- The C6 STEP model is provided by Espressif. Stock package models are KiCad
  representations; they are not certifications of a selected manufacturer's part.
- Five types lack a matching available model: **P4, camera FFC, TUSB320, TPS62132,
  and XP-G3 LED**. Local approximate body/package envelopes make their placement
  visible. These are explicitly recorded in `libraries/import-manifest.json`.
  The XP-G LED land pattern is a candidate for the XP-G3 and still needs a
  manufacturer recommended-land-pattern audit. It is not an exact XP-G3 STEP.
- All referenced models live under `libraries/3dmodels`, with project-relative
  paths. STEP exports substitute the paired body-envelope STEP for approximate
  VRML models. Small lens/latch detail may differ between the preview and STEP.
- Neither the camera module nor the diffuser/enclosure is included in this board
  model. Nominal package models are not sufficient to approve enclosure fit.

License notices and hashes accompany the assets. The generator only creates a
new directory and retains the original A0 snapshot as its input, so it does not
overwrite interactive edits when rerun.

## Layer count and cost target

The user is cost-sensitive and is comfortable with additional layers when the
price difference is modest. The current board already has four copper layers.
For a P4 implementation, retain four as the baseline:
[Espressif's layout guidance](https://docs.espressif.com/projects/esp-hardware-design-guidelines/en/latest/esp32p4/pcb-layout-design-esp32p4.html)
specifies at least four layers for high-speed signal quality and RF coexistence.
Its suggested arrangement is top signals/components, solid ground, power, and
bottom signals. The manufacturer's dielectric thicknesses and copper weights
must be chosen before final impedance-controlled routing; they are not finalized.

Favor standard fabrication materials, ordinary through-vias and one-side assembly
where practical. Six or more layers need a routing/electrical justification and
an actual cost comparison. Do not remove the ground-reference layer to chase a
low bare-board headline price.

Qualifying small-prototype promotions can make four-layer bare boards inexpensive,
but they are not an assembled device quote. Parts, setup, soldering, inspection,
shipping and order quantity all affect delivered cost. P4's 0.35 mm pin spacing
also needs an assembler capability check; JLCPCB currently lists 0.4 mm for
Economic PCBA and 0.35 mm for Standard PCBA in its
[prototype assembly capabilities](https://jlcpcb.com/solutions/pcb-prototype-assembly).
No assembler tier or device price has been committed.

A compact four-layer main board plus a simpler separate light board is a future
cost comparison against the current 100 x 100 mm combined study. Extra connectors,
assembly and mechanical work may offset the area savings. Do not split the design
solely on an assumed saving; quote both if the enclosure/optics make it useful.

## Reusing an open P4 circuit

### Native KiCad reference downloaded

[Olimex ESP32-P4-DevKit](https://github.com/OLIMEX/ESP32-P4-DevKit) provides real
KiCad schematic and PCB sources, including routed copper and local 3D assets.
Revision **D1**, commit `26705d36407a07324348927dfd30fbf4ffc1d94c`, is copied into
`reference/olimex-esp32-p4-devkit`. Its original files are retained unchanged;
`SOURCE.json` records file hashes. The original schematic parses in KiCad 10 and
its PCB renders with the supplied models. External Olimex libraries would need
resolution before using Update PCB from Schematic in that reference project;
the files contain their current symbols/footprints for inspection.

This reference has P4, power, flash, USB, camera/display connections and other
development-board functions. It does not supply our C6 radio/phone provisioning
or establish IMX519 support. It uses a combined `NC(VDD_HP_1)` pin-54 symbol and
a different regulator implementation. Its pin 54 connects to R35/C30. That is
evidence to audit against the current P4X reference, not a reason to copy the
old circuit unchecked.

Olimex's README states **CERN Open Hardware Licence v2, Strongly Reciprocal** for
hardware. Its root `LICENSE` is GPL for software; do not mistake that file for the
hardware license. Retain attribution and follow the hardware license's source
requirements when distributing a derivative. These reference circuits have not
been copied into the Daily Mirror main schematic in A1.

### Espressif reference

Espressif publishes
[P4X Function EV Board and P4X EYE reference designs](https://docs.espressif.com/projects/esp-hardware-design-guidelines/en/latest/esp32p4/related-documentation-and-resources.html).
Those archives use **OrCAD Capture `.DSN` and Allegro `.brd`**, so they are not a
native KiCad schematic import. Their terms are linked on that page. Use the
current revision-v3-or-later reference and the
[schematic checklist](https://docs.espressif.com/projects/esp-hardware-design-guidelines/en/latest/esp32p4/schematic-checklist-esp32p4.html)
to check or redraw a core circuit in KiCad.

### How the reuse works

1. Select the exact processor revision and suitable reference/license.
2. Copy useful **connected schematic sections** into a child sheet: power,
   crystal, flash, reset/boot and programming, including their support components.
3. Map the camera, radio, status LED, button and light-driver signals to available
   pins. Audit voltage levels, boot straps and supply sequencing.
4. Bring the resulting footprints into the PCB. Where useful, copy matching
   placement/routing from the source board and remap references/nets carefully.
5. Adapt the outline and component locations; route connections against a chosen
   fabricator's layer stack. Moving a component can invalidate the copied routing.
6. Check the final schematic/PCB, then prototype camera capture and illumination.

Copying a reference circuit puts the chips directly on our custom PCB. A different
option is soldering a complete purchased processor module onto the PCB; that can
reduce layout work, but it changes cost, dimensions and the available interfaces.

## Primary component references

- [Cree XP-G3 data sheet](https://downloads.cree-led.com/files/ds/x/XLamp-XPG3.pdf),
  current white ordering table: `U1` 90-CRI code, `3E` 5000 K kit.
- [Molex 2005280150](https://www.molex.com/en-us/products/part-detail/2005280150)
- [TI TPS62132](https://www.ti.com/product/TPS62132),
  [TPS61165](https://www.ti.com/product/TPS61165),
  [TUSB320IRWBR](https://www.ti.com/product/TUSB320/part-details/TUSB320IRWBR)
- [Omron B3F switch data sheet](https://components.omron.com/us-en/datasheet_pdf/A070-E1.pdf)
- [Murata 100 nF data sheet](https://search.murata.co.jp/Ceramy/image/img/A01X/G101/ENG/GRM188R71C104KA01-01.pdf)
- [Yageo 10 kΩ data sheet](https://www.yageogroup.com/component-documentation/download/specsheet/RC0603FR-0710KL)

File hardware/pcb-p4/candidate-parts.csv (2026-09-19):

ref | value | manufacturer | mpn | footprint | sheet | status | source | note
U1 | ESP32-P4NRW32X | Espressif | ESP32-P4NRW32X | ESP32-P4 | processor | Candidate; wiring and qualification pending | https://documentation.espressif.com/esp32-p4_datasheet_en.html | Current X / rev3+ symbol. IMX519 full-resolution path unproven. 32 MB in-package PSRAM; external flash required.
U2 | ESP32-C6-MINI-1-N4 | Espressif | ESP32-C6-MINI-1-N4 | ESP32-C6-MINI-1 | processor | Candidate; wiring and qualification pending | https://www.espressif.com/sites/default/files/documentation/esp32-c6-mini-1_datasheet_en.pdf | Wi-Fi/BLE companion. SDIO/ESP-Hosted integration pending. Antenna needs copper/component keepout.
U3 | W25Q128JVSIQ | Winbond | W25Q128JVSIQ | SOIC-8_5.3x5.3mm_P1.27mm | processor | Candidate; wiring and qualification pending | https://www.winbond.com/resource-files/w25q128jv_dtr%20revc%2003272018%20plus.pdf | 16 MiB external SPI flash; boot flash voltage and strapping pending.
J2 | Pi-style CSI camera - 15 pin | Molex | 2005280150 | Molex_200528-0150_1x15-1MP_P1.00mm_Horizontal | processor | Candidate; wiring and qualification pending | https://www.molex.com/en-us/products/part-detail/2005280150 | Bottom-contact, 1 mm pitch. Confirm actual Arducam module/ribbon contact side and pinout before wiring.
Y1 | 40 MHz / 10 pF | Abracon | ABM8-40.000MHZ-10-1-U-T | Crystal_SMD_3225-4Pin_3.2x2.5mm | processor | Candidate; wiring and qualification pending | https://abracon.com/Support/SPICE/Resonators/ABM8-Series%20ParameterTest%20Data_SPICE%20MODEL.pdf | Manufacturer test report gives +/-10 ppm. Ordering availability and temperature specification need confirmation; generic package model.
U4 | TPS62132RGTR | Texas Instruments | TPS62132RGTR | VQFN-16-1EP_3x3mm_P0.5mm_EP1.68x1.68mm | power | Candidate; wiring and qualification pending | https://www.ti.com/product/TPS62132 | Fixed 3.3 V, 3 A main buck. Inductor/output network and load budget pending.
U5 | TLV62569DBVR | Texas Instruments | TLV62569DBVR | SOT-23-5 | power | Candidate; wiring and qualification pending | https://www.ti.com/product/TLV62569 | P4 core buck. Use rev3+ feedback/control circuit, not a fixed generic 1.1 V assumption.
U6 | TUSB320IRWBR | Texas Instruments | TUSB320IRWBR | Texas_X2QFN-12_1.6x1.6mm_P0.4mm | power | Candidate; wiring and qualification pending | https://www.ti.com/product/TUSB320/part-details/TUSB320IRWBR | 5 V Type-C source-current detection. Configure sink. Not a PD controller; gate load to advertised current. Stock availability not confirmed.
U8 | USBLC6-2SC6 | STMicroelectronics | USBLC6-2SC6 | SOT-23-6 | power | Candidate; wiring and qualification pending | https://www.st.com/en/protection-devices/usblc6-2.html | USB data-line ESD protection; additional VBUS/CC protection design pending.
U9 | TPS22919DCKR | Texas Instruments | TPS22919DCKR | SOT-363_SC-70-6 | power | Candidate; wiring and qualification pending | https://www.ti.com/product/TPS22919 | Camera power switch candidate; confirm camera module supply and startup current.
J1 | USB-C / 5 V | GCT | USB4105-GF-A | USB_C_Receptacle_GCT_USB4105-xx-A_16P_TopMnt_Horizontal | power | Candidate; wiring and qualification pending | https://gct.co/connector/USB4105 | Select exact stake length/order suffix with board thickness; input load protection/inrush circuitry pending.
J3 | Service UART / boot | Generic | TBD 1x06 2.54 mm header | PinHeader_1x06_P2.54mm_Vertical | power | Candidate; wiring and qualification pending | https://gitlab.com/kicad/libraries/kicad-footprints | Service pinout not assigned; prefer production test pads in final design.
SW2 | RESET | Generic | TBD 6 mm tactile | SW_PUSH_6mm_H4.3mm | power | Candidate; wiring and qualification pending | https://gitlab.com/kicad/libraries/kicad-footprints | Generic body; choose exact switch force/actuator height for enclosure.
SW3 | BOOT | Generic | TBD 6 mm tactile | SW_PUSH_6mm_H4.3mm | power | Candidate; wiring and qualification pending | https://gitlab.com/kicad/libraries/kicad-footprints | Generic body; choose exact switch force/actuator height for enclosure.
U7 | TPS61165DBVR | Texas Instruments | TPS61165DBVR | SOT-23-6 | lighting | Candidate; wiring and qualification pending | https://www.ti.com/product/TPS61165 | Constant-current boost candidate. 1.2 A is switch rating, not available LED output current. Tentative eight-series / 100 mA for initial optical study only.
D10 | SS16-E3/61T | Vishay | SS16-E3/61T | D_SMA | lighting | Candidate; wiring and qualification pending | https://www.vishay.com/en/product/88746/ | Boost rectifier candidate; calculate peak current, losses and reverse voltage.
D2 | White 5000 K / CRI90 | Cree LED | XPGDWT-U1-0000-00J3E | LED_Cree-XP-G | lighting | Candidate; wiring and qualification pending | https://downloads.cree-led.com/files/ds/x/XLamp-XPG3.pdf | Plain white XP-G3. Qty eight provisional. Shared XP-G footprint and package STEP are candidates, not an exact manufacturer XP-G3 model. Thermal pad electrically isolated from LED; heat-spreading copper required.
D3 | White 5000 K / CRI90 | Cree LED | XPGDWT-U1-0000-00J3E | LED_Cree-XP-G | lighting | Candidate; wiring and qualification pending | https://downloads.cree-led.com/files/ds/x/XLamp-XPG3.pdf | Plain white XP-G3. Qty eight provisional. Shared XP-G footprint and package STEP are candidates, not an exact manufacturer XP-G3 model. Thermal pad electrically isolated from LED; heat-spreading copper required.
D4 | White 5000 K / CRI90 | Cree LED | XPGDWT-U1-0000-00J3E | LED_Cree-XP-G | lighting | Candidate; wiring and qualification pending | https://downloads.cree-led.com/files/ds/x/XLamp-XPG3.pdf | Plain white XP-G3. Qty eight provisional. Shared XP-G footprint and package STEP are candidates, not an exact manufacturer XP-G3 model. Thermal pad electrically isolated from LED; heat-spreading copper required.
D5 | White 5000 K / CRI90 | Cree LED | XPGDWT-U1-0000-00J3E | LED_Cree-XP-G | lighting | Candidate; wiring and qualification pending | https://downloads.cree-led.com/files/ds/x/XLamp-XPG3.pdf | Plain white XP-G3. Qty eight provisional. Shared XP-G footprint and package STEP are candidates, not an exact manufacturer XP-G3 model. Thermal pad electrically isolated from LED; heat-spreading copper required.
D6 | White 5000 K / CRI90 | Cree LED | XPGDWT-U1-0000-00J3E | LED_Cree-XP-G | lighting | Candidate; wiring and qualification pending | https://downloads.cree-led.com/files/ds/x/XLamp-XPG3.pdf | Plain white XP-G3. Qty eight provisional. Shared XP-G footprint and package STEP are candidates, not an exact manufacturer XP-G3 model. Thermal pad electrically isolated from LED; heat-spreading copper required.
D7 | White 5000 K / CRI90 | Cree LED | XPGDWT-U1-0000-00J3E | LED_Cree-XP-G | lighting | Candidate; wiring and qualification pending | https://downloads.cree-led.com/files/ds/x/XLamp-XPG3.pdf | Plain white XP-G3. Qty eight provisional. Shared XP-G footprint and package STEP are candidates, not an exact manufacturer XP-G3 model. Thermal pad electrically isolated from LED; heat-spreading copper required.
D8 | White 5000 K / CRI90 | Cree LED | XPGDWT-U1-0000-00J3E | LED_Cree-XP-G | lighting | Candidate; wiring and qualification pending | https://downloads.cree-led.com/files/ds/x/XLamp-XPG3.pdf | Plain white XP-G3. Qty eight provisional. Shared XP-G footprint and package STEP are candidates, not an exact manufacturer XP-G3 model. Thermal pad electrically isolated from LED; heat-spreading copper required.
D9 | White 5000 K / CRI90 | Cree LED | XPGDWT-U1-0000-00J3E | LED_Cree-XP-G | lighting | Candidate; wiring and qualification pending | https://downloads.cree-led.com/files/ds/x/XLamp-XPG3.pdf | Plain white XP-G3. Qty eight provisional. Shared XP-G footprint and package STEP are candidates, not an exact manufacturer XP-G3 model. Thermal pad electrically isolated from LED; heat-spreading copper required.
L1 | 2.2 uH | Coilcraft | XAL4020-222MEC | L_Coilcraft_XAL4020-XXX | power | Candidate; wiring and qualification pending | https://www.coilcraft.com/en-us/products/power/shielded-inductors/molded-inductor/xal/xal40xx/xal4020-222/ | Electrical value and current/temperature margin provisional; package imported from KiCad.
L2 | 2.2 uH | Coilcraft | XAL4020-222MEC | L_Coilcraft_XAL4020-XXX | power | Candidate; wiring and qualification pending | https://www.coilcraft.com/en-us/products/power/shielded-inductors/molded-inductor/xal/xal40xx/xal4020-222/ | Electrical value and current/temperature margin provisional; package imported from KiCad.
L3 | 10 uH | Coilcraft | XAL4040-103MEC | L_Coilcraft_XAL4040-XXX | lighting | Candidate; wiring and qualification pending | https://www.coilcraft.com/en-us/products/power/shielded-inductors/molded-inductor/xal/xal40xx/xal4040-103/ | Electrical value and current/temperature margin provisional; package imported from KiCad.
C2 | 100nF | Murata | GRM188R71C104KA01D | C_0603_1608Metric | support | Candidate; wiring and qualification pending | https://www.murata.com/en-us/products/capacitor/ceramiccapacitor | 16 V X7R; quantities/value/rail assignments provisional, DC-bias derating pending.
C3 | 100nF | Murata | GRM188R71C104KA01D | C_0603_1608Metric | support | Candidate; wiring and qualification pending | https://www.murata.com/en-us/products/capacitor/ceramiccapacitor | 16 V X7R; quantities/value/rail assignments provisional, DC-bias derating pending.
C4 | 100nF | Murata | GRM188R71C104KA01D | C_0603_1608Metric | support | Candidate; wiring and qualification pending | https://www.murata.com/en-us/products/capacitor/ceramiccapacitor | 16 V X7R; quantities/value/rail assignments provisional, DC-bias derating pending.
C5 | 100nF | Murata | GRM188R71C104KA01D | C_0603_1608Metric | support | Candidate; wiring and qualification pending | https://www.murata.com/en-us/products/capacitor/ceramiccapacitor | 16 V X7R; quantities/value/rail assignments provisional, DC-bias derating pending.
C6 | 100nF | Murata | GRM188R71C104KA01D | C_0603_1608Metric | support | Candidate; wiring and qualification pending | https://www.murata.com/en-us/products/capacitor/ceramiccapacitor | 16 V X7R; quantities/value/rail assignments provisional, DC-bias derating pending.
C7 | 100nF | Murata | GRM188R71C104KA01D | C_0603_1608Metric | support | Candidate; wiring and qualification pending | https://www.murata.com/en-us/products/capacitor/ceramiccapacitor | 16 V X7R; quantities/value/rail assignments provisional, DC-bias derating pending.
C8 | 100nF | Murata | GRM188R71C104KA01D | C_0603_1608Metric | support | Candidate; wiring and qualification pending | https://www.murata.com/en-us/products/capacitor/ceramiccapacitor | 16 V X7R; quantities/value/rail assignments provisional, DC-bias derating pending.
C9 | 100nF | Murata | GRM188R71C104KA01D | C_0603_1608Metric | support | Candidate; wiring and qualification pending | https://www.murata.com/en-us/products/capacitor/ceramiccapacitor | 16 V X7R; quantities/value/rail assignments provisional, DC-bias derating pending.
C10 | 100nF | Murata | GRM188R71C104KA01D | C_0603_1608Metric | support | Candidate; wiring and qualification pending | https://www.murata.com/en-us/products/capacitor/ceramiccapacitor | 16 V X7R; quantities/value/rail assignments provisional, DC-bias derating pending.
C11 | 100nF | Murata | GRM188R71C104KA01D | C_0603_1608Metric | support | Candidate; wiring and qualification pending | https://www.murata.com/en-us/products/capacitor/ceramiccapacitor | 16 V X7R; quantities/value/rail assignments provisional, DC-bias derating pending.
C12 | 100nF | Murata | GRM188R71C104KA01D | C_0603_1608Metric | support | Candidate; wiring and qualification pending | https://www.murata.com/en-us/products/capacitor/ceramiccapacitor | 16 V X7R; quantities/value/rail assignments provisional, DC-bias derating pending.
C13 | 100nF | Murata | GRM188R71C104KA01D | C_0603_1608Metric | support | Candidate; wiring and qualification pending | https://www.murata.com/en-us/products/capacitor/ceramiccapacitor | 16 V X7R; quantities/value/rail assignments provisional, DC-bias derating pending.
C14 | 100nF | Murata | GRM188R71C104KA01D | C_0603_1608Metric | support | Candidate; wiring and qualification pending | https://www.murata.com/en-us/products/capacitor/ceramiccapacitor | 16 V X7R; quantities/value/rail assignments provisional, DC-bias derating pending.
C15 | 100nF | Murata | GRM188R71C104KA01D | C_0603_1608Metric | support | Candidate; wiring and qualification pending | https://www.murata.com/en-us/products/capacitor/ceramiccapacitor | 16 V X7R; quantities/value/rail assignments provisional, DC-bias derating pending.
C16 | 100nF | Murata | GRM188R71C104KA01D | C_0603_1608Metric | support | Candidate; wiring and qualification pending | https://www.murata.com/en-us/products/capacitor/ceramiccapacitor | 16 V X7R; quantities/value/rail assignments provisional, DC-bias derating pending.
C17 | 100nF | Murata | GRM188R71C104KA01D | C_0603_1608Metric | support | Candidate; wiring and qualification pending | https://www.murata.com/en-us/products/capacitor/ceramiccapacitor | 16 V X7R; quantities/value/rail assignments provisional, DC-bias derating pending.
C18 | 10uF | Murata | GRM21BR61A106KE19L | C_0805_2012Metric | support | Candidate; wiring and qualification pending | https://www.murata.com/en-us/products/capacitor/ceramiccapacitor | 10 V X5R; quantities/value/rail assignments provisional, DC-bias derating pending.
C19 | 100nF | Murata | GRM188R71C104KA01D | C_0603_1608Metric | support | Candidate; wiring and qualification pending | https://www.murata.com/en-us/products/capacitor/ceramiccapacitor | 16 V X7R; quantities/value/rail assignments provisional, DC-bias derating pending.
C20 | 100nF | Murata | GRM188R71C104KA01D | C_0603_1608Metric | support | Candidate; wiring and qualification pending | https://www.murata.com/en-us/products/capacitor/ceramiccapacitor | 16 V X7R; quantities/value/rail assignments provisional, DC-bias derating pending.
C21 | 10uF | Murata | GRM21BR61A106KE19L | C_0805_2012Metric | support | Candidate; wiring and qualification pending | https://www.murata.com/en-us/products/capacitor/ceramiccapacitor | 10 V X5R; quantities/value/rail assignments provisional, DC-bias derating pending.
C22 | 10uF | Murata | GRM21BR61A106KE19L | C_0805_2012Metric | support | Candidate; wiring and qualification pending | https://www.murata.com/en-us/products/capacitor/ceramiccapacitor | 10 V X5R; quantities/value/rail assignments provisional, DC-bias derating pending.
C23 | 10uF | Murata | GRM21BR61A106KE19L | C_0805_2012Metric | support | Candidate; wiring and qualification pending | https://www.murata.com/en-us/products/capacitor/ceramiccapacitor | 10 V X5R; quantities/value/rail assignments provisional, DC-bias derating pending.
C24 | 100nF | Murata | GRM188R71C104KA01D | C_0603_1608Metric | support | Candidate; wiring and qualification pending | https://www.murata.com/en-us/products/capacitor/ceramiccapacitor | 16 V X7R; quantities/value/rail assignments provisional, DC-bias derating pending.
C25 | 1uF | Murata | GRM21BR71H105KA12L | C_0805_2012Metric | support | Candidate; wiring and qualification pending | https://www.murata.com/en-us/products/capacitor/ceramiccapacitor | 50 V X7R; LED boost output candidate; quantities/value/rail assignments provisional, DC-bias derating pending.
R8 | 499k | Yageo | RC0603FR-07499KL | R_0603_1608Metric | support | Candidate; wiring and qualification pending | https://www.yageogroup.com/component-documentation/download/specsheet/RC0603FR-07499KL | P4 rev3 core control network; not wired; value and MPN ordering check pending.
R9 | 499k | Yageo | RC0603FR-07499KL | R_0603_1608Metric | support | Candidate; wiring and qualification pending | https://www.yageogroup.com/component-documentation/download/specsheet/RC0603FR-07499KL | P4 rev3 core control network; not wired; value and MPN ordering check pending.
R10 | 4.02k | Yageo | RC0603FR-074K02L | R_0603_1608Metric | support | Candidate; wiring and qualification pending | https://www.yageogroup.com/component-documentation/download/specsheet/RC0603FR-074K02L | CSI REXT; not wired; value and MPN ordering check pending.
R11 | 4.02k | Yageo | RC0603FR-074K02L | R_0603_1608Metric | support | Candidate; wiring and qualification pending | https://www.yageogroup.com/component-documentation/download/specsheet/RC0603FR-074K02L | DSI REXT if DSI used; not wired; value and MPN ordering check pending.
R12 | 10k | Yageo | RC0603FR-0710KL | R_0603_1608Metric | support | Candidate; wiring and qualification pending | https://www.yageogroup.com/component-documentation/download/specsheet/RC0603FR-0710KL | Reset pull-up candidate; not wired; value and MPN ordering check pending.
R13 | 10k | Yageo | RC0603FR-0710KL | R_0603_1608Metric | support | Candidate; wiring and qualification pending | https://www.yageogroup.com/component-documentation/download/specsheet/RC0603FR-0710KL | Boot pull-up candidate; not wired; value and MPN ordering check pending.
R14 | 100k | Yageo | RC0603FR-07100KL | R_0603_1608Metric | support | Candidate; wiring and qualification pending | https://www.yageogroup.com/component-documentation/download/specsheet/RC0603FR-07100KL | LED enable default-off candidate; not wired; value and MPN ordering check pending.
R15 | 2 ohm | Yageo | RC0805FR-072RL | R_0805_2012Metric | support | Candidate; wiring and qualification pending | https://www.yageogroup.com/component-documentation/download/specsheet/RC0805FR-072RL | LED current sense: 0.2 V / 2 ohm = 100 mA initial study; not wired; value and MPN ordering check pending.
R16 | 2.2k | Yageo | RC0603FR-072K2L | R_0603_1608Metric | support | Candidate; wiring and qualification pending | https://www.yageogroup.com/component-documentation/download/specsheet/RC0603FR-072K2L | Camera I2C pull-up candidate; not wired; value and MPN ordering check pending.
R17 | 2.2k | Yageo | RC0603FR-072K2L | R_0603_1608Metric | support | Candidate; wiring and qualification pending | https://www.yageogroup.com/component-documentation/download/specsheet/RC0603FR-072K2L | Camera I2C pull-up candidate; not wired; value and MPN ordering check pending.
C26 | 22pF | Murata | GRM1885C1H220JA01D | C_0603_1608Metric | support | Candidate; wiring and qualification pending | https://www.murata.com/en-us/products/capacitor/ceramiccapacitor | Core compensation; crystal capacitors require load/stray calculation and measurement.
C27 | TUNE pF | Murata | TBD C0G 0603 | C_0603_1608Metric | support | Candidate; wiring and qualification pending | https://www.murata.com/en-us/products/capacitor/ceramiccapacitor | Crystal load; crystal capacitors require load/stray calculation and measurement.
C28 | TUNE pF | Murata | TBD C0G 0603 | C_0603_1608Metric | support | Candidate; wiring and qualification pending | https://www.murata.com/en-us/products/capacitor/ceramiccapacitor | Crystal load; crystal capacitors require load/stray calculation and measurement.

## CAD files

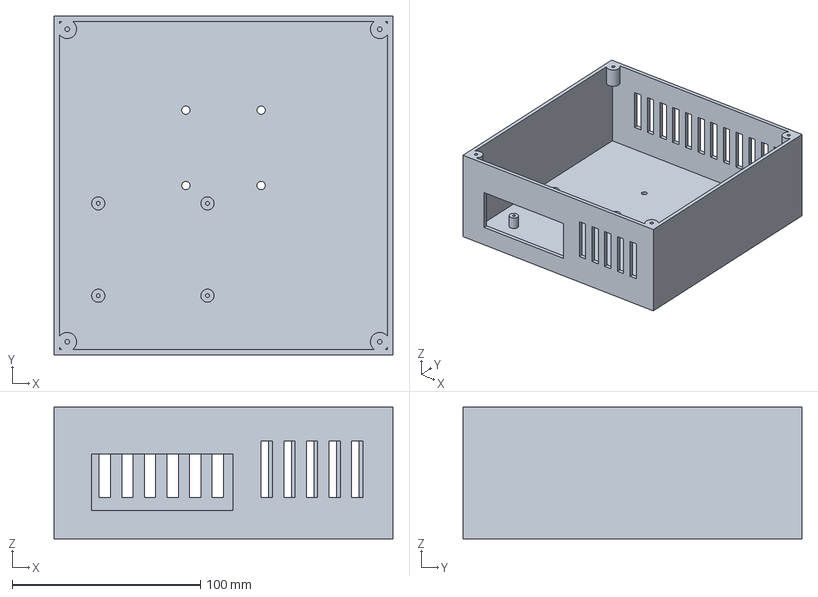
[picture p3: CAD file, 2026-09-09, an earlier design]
hardware/enclosure/output/Base.step
180.0 x 180.0 x 70.0 mm

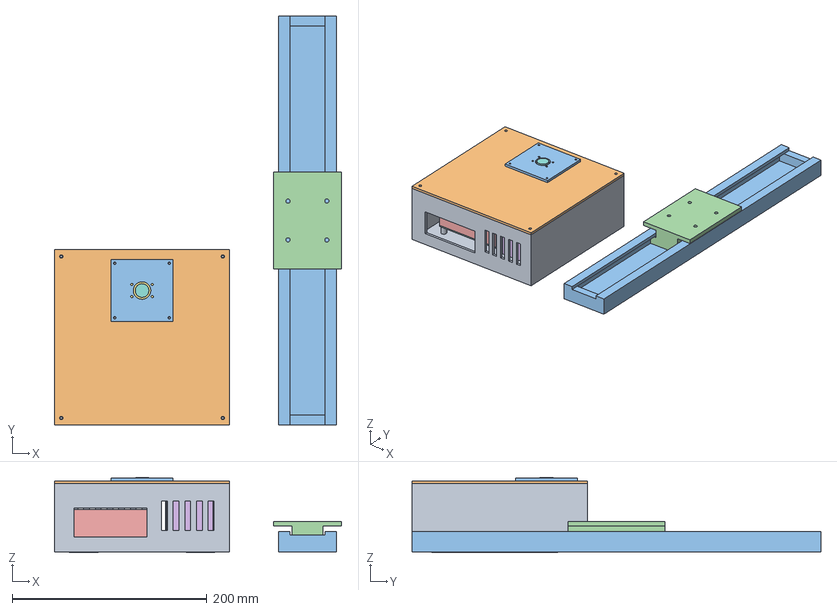
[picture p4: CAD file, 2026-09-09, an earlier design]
hardware/enclosure/output/DailyMirrorEnclosure.FCStd
295.0 x 420.0 x 77.6 mm
01 • Roomy base 180 × 180 × 70
02 • Lid — controls remain undrilled
03 • Camera plate — provisional hole pattern
REFERENCE • Pi 4 board envelope
REFERENCE • component/cooler allowance
REFERENCE • wiring/perfboard reserve
REFERENCE • unconfirmed camera PCB
REFERENCE • unconfirmed lens envelope
REFERENCE • adhesive land, select actual strips
REFERENCE • adhesive land, select actual strips001
STUDY • 420 mm rail, removable top stop required
STUDY • carriage, clamp/detent not yet designed

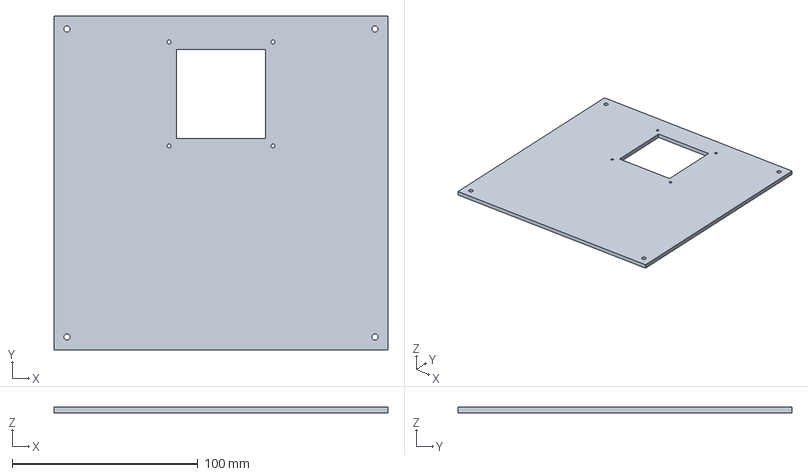
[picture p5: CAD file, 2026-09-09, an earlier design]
hardware/enclosure/output/Lid.step
180.0 x 180.0 x 3.00 mm

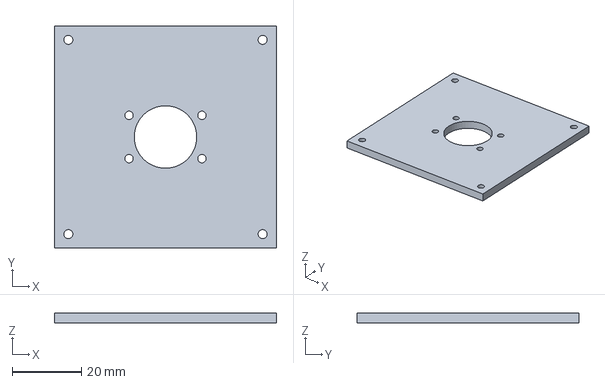
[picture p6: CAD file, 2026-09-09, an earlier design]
hardware/enclosure/output/CameraAdapter.step
64.0 x 64.0 x 3.00 mm

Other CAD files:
hardware/enclosure/output/Base.stl
hardware/enclosure/output/CameraAdapter.stl
hardware/enclosure/output/Lid.stl

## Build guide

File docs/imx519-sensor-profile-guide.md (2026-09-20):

# IMX519 unit: evidence and profiles to carry into portrait testing

This record describes the replacement module on **rpi2**, including its lens,
Raspberry Pi 4 camera software and image processing. It is not a specification
for every IMX519 module, nor a completed characterization of the bare sensor.
The module brand/lens model and measured target distance remain unknown.

## What we can carry forward

| Finding | Evidence | Practical consequence |
| --- | --- | --- |
| Sensor and lens control operate | Post-reboot IMX519 detection, 4656×3496 JPEGs, AK7375 binding | Hardware/software bring-up is complete for this unit |
| Stock tuning omitted autofocus | Missing `rpi.af`, explicit no-algorithm logs; adding a separate AF block enabled focused captures | Keep the custom tuning file; preserve stock files |
| Focus works at the tested positions | Focused metadata and legible small chart text over repeated captures | Retain central autofocus region; verify again on eyes/faces and at measured distances |
| Forced high-quality denoising slowed focus | Two 3-second runs were still searching; auto denoising restored three focused repeats | Use `auto` rather than forcing `cdn_hq` throughout acquisition |
| Color/exposure choices visibly matter | Saved neutral, brighter, sport and tone-curve comparisons | Start with modest saturation/sharpening and lifted shadows; avoid blanket positive EV |
| Exposure timing can affect wall bands | 16 MP row-residual proxy improved near 1/60 s; 4 MP did not show the same improvement | Test flicker per sensor mode with final lights; don't call it solved |
| Stacking can reduce visible grain | Five aligned 16 MP frames reduced wall high-pass variation about 56%, with some edge softness | Carry best-frame fallback into merging; inspect detail as well as smoothness |
| Current capture path has a speed/detail tradeoff | Five-frame sensor spans: 16 MP ~2.56 s, 4 MP ~0.63–0.77 s | Benchmark a faster acquisition path before enabling portrait bursts |

## Candidate profiles

These are reproducible starting points, not a ranking established on portraits.

| Profile | Configuration | Status and intended test |
| --- | --- | --- |
| Neutral reference | IMX519 AF tuning, stock tone curve, saturation/contrast/sharpness 1, automatic exposure/WB | Captured; retain as the control for every new lighting setup |
| Vibrant single photo | Portrait tone file (stock output gamma raised to 0.85), saturation 1.15, sharpness 1.15, contrast 1, brightness/EV 0, sport exposure, auto denoise | Saved in normal device captures; verify skin tone and facial texture |
| Detail-first burst | 4656×3496, five frames; settled focus then locked lens/WB/exposure/gain; aligned mean with rejection of local changes | Offline prototype tested on static scene; current span too long for casual portrait movement |
| Faster burst | Same method at full-field 2328×1748 | Static scene tested; faster but finer text is softer; compare at equal delivered image dimensions |
| Exposure-bracketed fusion | Multiple exposure levels, aligned with motion rejection | **Not yet tested**; intended for bright-background/dark-face scenes |

Normal and lab profiles are distinct: the device `.env` contains quoted normal
capture arguments and the tuning-file path. Lab controls are session settings.
See `evidence/imx519-rpi2/portrait-lab-settings.json` and the calibration record
for exact settings and reproduction commands. A saved `lens_position` value in
continuous mode is inactive; current distance presets are not calibrated.

## Data preserved

- Original JPEGs, reference photos and separate processed PNGs.
- Actual exposure, analogue/digital gain, white-balance gains, AF state and lens
  position where supplied; sensor timestamps for burst cadence.
- Capture commands/settings, registration results, rejected areas, and
  scene-specific wall/detail measurements.
- Local archive: `captures/characterization/2026-09-10/` (ignored by Git).
  `evidence/imx519-rpi2/archive-index.json` inventories it with hashes.
- Burst originals also remain on rpi2 under `data/experiments/`.
- Metadata/reports and scripts are in the repository working tree. The local
  archive is durable beyond `/tmp`, but is not an off-machine backup.

## What we still do not know

- Real skin-tone accuracy, eye/eyelash/hair detail, blinking and subject motion.
- The focus-distance relationship, depth of field at measured subject positions,
  and edge performance for the actual lens.
- Calibrated sensor read noise, dynamic range, color response or RAW behavior.
  JPEG grain and edge metrics mix sensor, optics, ISP, display and lighting.
- Final LED intensity, spectrum, flicker/PWM behavior, diffusion, illumination
  uniformity, and the settle time needed before a photo.
- Whether a faster burst with independently moving people beats the best single
  frame, including latency and memory costs of a complete end-to-end pipeline.

## Controlled next pass when lighting arrives

Measure distance, fix the camera and target positions, and record LED drive/
brightness/diffuser settings. Use a printed detail target and a neutral reference
under the same light as the face. Run the neutral and vibrant single profiles,
then motion-tested bursts. Change one variable at a time and repeat each case.
Compare skin and hair at the same output size, highlight retention, visible noise,
focus hit rate and time to the final image. Retain the neutral original even when
a processed version is preferred. Revisit flash timing using actual frame
acquisition, rather than assuming that a short pulse illuminates every row.

Supporting records: [bring-up and portrait tuning](imx519-rpi2-calibration.md)
and [burst experiments](burst-processing-experiment.md).

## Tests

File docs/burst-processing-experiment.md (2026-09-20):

# Burst and banding experiment — September 10, 2026

## Scope

Tested the current rpi2 IMX519 using the existing rpicam stack and a static
monitor/wall scene. No people or flash hardware were tested. Normal capture
settings are unchanged; the usual lab preview was restored after the experiments.

## Capture

`scripts/capture_burst_experiment.py` runs **on the Pi**, with the device service
stopped and restarted by the caller in a shell EXIT trap. It first autofocuses a
reference, then locks lens position, white balance, shutter and gain within each
five-frame group. It uses `rpicam-still --zsl --signal`, with completed metadata
files as capture acknowledgements. This avoids restarting the camera per photo.
A first run using stdout acknowledgements hit buffering and was abandoned.
Original JPEGs and actual per-frame metadata are retained.

Each run compares the reference shutter near 20 ms to a 16.667 ms shutter,
adjusting gain to approximately match total exposure. Full resolution is
4656×3496; `--binned` requests 2328×1748. Both retain the full field of view.
Five-frame spans measured from sensor timestamps:

| Output | Original timing | 60 Hz-compatible timing |
| --- | ---: | ---: |
| 16 MP | 2.555 s | 2.555 s |
| 4 MP | 0.633 s | 0.767 s |

These exclude autofocus, settling, file transfer and offline processing. They
are not total button-to-result times. JPEG encoding and acknowledgement incur
gaps, so this is not a demonstration of the sensor's maximum frame rate.

Raw experiments remain on rpi2 under
`/home/drew/daily-mirror-device/data/experiments/burst-20260911-02` (16 MP) and
`burst-20260911-03` (4 MP). Readiness was restored after both runs. No gallery
uploads were made. No system camera packages were installed or upgraded.

## Processing

`scripts/process_burst_experiment.py EXPERIMENT_DIRECTORY` runs offline with
NumPy and OpenCV. OpenCV 5.0.0 was installed in an isolated temporary directory
on the workstation for this run. The source frames are untouched.

1. Rank frames using a lightly smoothed sharpness metric in the chart ROI.
2. Align candidate frames using phase-correlation initialization and ECC
   translation refinement. Reject failed alignment, low correlation or large
   displacement.
3. Produce a simple aligned mean.
4. Produce a second mean that rejects pixels with large local changes, retaining
   the reference at those locations. Rejecting a whole frame is also permitted.
5. Save lossless PNG results and reports beside the original JPEGs.

This is averaging of already-rendered pixels, not calibrated radiance merging,
RAW processing, HDR, face-aware selection, or a production motion model. It
cannot restore clipped highlights. Scene-specific sharpness and wall metrics
must not be used as universal photo-quality scores.

Synthetic tests (`scripts/test_burst_processing.py`) verify known translation
recovery, actual error reduction against a clean image, and rejection of a
changed foreground patch. All three pass. Real portrait motion remains untested.

## Findings

In the 16 MP run, mean wall row-residual variation fell from 1.749 to 0.858
8-bit levels with the 60 Hz-compatible shutter. This is consistent with a
flicker contribution, not proof of the lighting source. The 4 MP run did not
show that benefit (1.728 versus 2.178). Broad illumination gradients, wall
texture, sensor timing and the changing display confound a definitive diagnosis.

For the 16 MP 60 Hz group, combining five frames reduced the wall's high-pass
variation from about 2.49 to 1.10 levels: roughly 56%. This metric includes
texture and processing artifacts, not just sensor noise. The wall visibly
looks smoother. Fine text remains readable but some edges are softer after
alignment/interpolation. The 4 MP output is faster and smoother but resolves
less fine text; its incremental stacking gain is smaller.

Detailed metadata and measured results live in `docs/evidence/burst-20260911/`.
The comparison graphic uses native-pixel crops without additional denoising.

## Next implementation choices

- First identify the lighting source and test flicker suppression in each actual
  sensor mode. The installed CLI supports `--flicker-period 8333us` for 60 Hz
  mains-related flicker; PWM or display flicker need not follow mains frequency.
- Test portrait motion and blinking. Select a good anchor frame and fall back to
  it where registration or motion checks fail. Global translation alone cannot
  align expression changes or independently moving facial features.
- Improve capture throughput by retaining consecutive buffers before encoding,
  then compare 4 MP and 16 MP at the same delivered image dimensions.
- Add exposure bracketing only after motion rejection is reliable. Mertens-style
  exposure fusion is a reasonable offline comparison, but multi-exposure ghosting
  is a separate problem from same-exposure denoising.
- For LED lighting, hold illumination steady through settling and the entire
  burst, then switch it off. Establish exposure/focus under the capture light.
  A short strobe can cause partial-frame illumination with rolling readout.
  Diffusion softens lighting but does not fix driver flicker; choose/test the
  driver and dimming mode along with the strips. No flash timing is calibrated.

References:
- [Raspberry Pi camera tuning guide](https://datasheets.raspberrypi.com/camera/raspberry-pi-camera-guide.pdf)
- [rpicam still capture implementation](https://github.com/raspberrypi/rpicam-apps/blob/main/apps/rpicam_still.cpp)
- [OpenCV HDR and exposure fusion](https://docs.opencv.org/4.13.0/d2/df0/tutorial_py_hdr.html)

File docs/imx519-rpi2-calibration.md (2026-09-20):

# rpi2 replacement IMX519 calibration

Verified September 10, 2026 (Denver). The replacement module's brand/model was
not supplied. Sensor detection identifies IMX519 at I2C 10-001a and the AK7375
lens driver at 10-000c. Full-resolution capture is 4656 × 3496.

## Installed changes

- Replaced the obsolete OV5647 boot overlay with `dtoverlay=imx519`, leaving
  automatic camera detection disabled. Rebooted and verified sensor detection.
- Set `DAILY_MIRROR_CAMERA_PROFILE=imx519`. Capture mode remains local.
- Installed the device binary with standby and processing LEDs off. Successful
  normal capture flashes green twice, then goes dark. Countdown yellow and
  error red remain. The admin lamp is labeled Success.
- Stock IMX519 tuning had no `rpi.af`; logs explicitly reported no AF algorithm.
  The existing AK7375 driver did expose focus controls. Added a separate
  `/home/drew/daily-mirror-device/config/imx519-af.json`, selected through
  `LIBCAMERA_RPI_TUNING_FILE` in the device `.env`. Stock package files are intact.
- `scripts/prepare_imx519_tuning.py OUTPUT` recreates the tuning candidate from
  installed IMX519 calibration and installed autofocus settings. PDAF is disabled
  in favor of contrast autofocus. Its actuator map is provisional, based on the
  [IMX519 upstream proposal](https://lists.libcamera.org/pipermail/libcamera-devel/2023-June/038295.html).
  Lens-position numbers do not yet represent calibrated physical distances.

The old boot config and environment are backed up beside their originals with
`.before-imx519` suffixes. The previous device binary is kept in `bin/`.

## Screen calibration

`scripts/calibration_target.py` opens a Tk window. Write `chart`, `text`, `gray`,
or `image:/absolute/path` to `/tmp/mirror-target-mode` to change its contents.
Escape closes the window. Requires tkinter and Pillow.

Far-right display: portrait HP E243, HDMI-A-1, workspace 5, monitor ID 2.
This Hyprland version uses Lua dispatch; after discovering the current window
address with `hyprctl clients -j`, use:

```sh
hyprctl dispatch 'hl.dsp.window.move({workspace = "5", follow = false, window = "address:CURRENT_ADDRESS"})'
```

Chart settings are in `evidence/imx519-rpi2/screen-lab-settings.json`. Apply with
`POST /api/lab/settings` using a JSON body. These are screen-test settings:
1/60 second shutter, gain 3, default color processing, continuous focus and a
focus region covering the monitor. They are not general portrait exposure
settings. The lab retains them in memory; only orientation persists through the
lab settings endpoint. Normal capture retains automatic exposure and the normal
portrait focus window, using the newly installed AF tuning.

Observed chart metadata: AfState 2 (focused), LensPosition 6.607428,
ExposureTime 16662 microseconds, AnalogueGain 2.994152. Text and grayscale steps
were visibly resolved. Camera placement changed during setup, so raw sharpness
scores across those frames are not a controlled comparison. Color accuracy is
not certified by a photograph of an uncalibrated display.

## Validation

- 20 unit tests and one integration test pass; device Clippy passes with warnings
  denied. The release cross-build succeeded and deployed health check passed.
- Normal local capture completed. Live LED events showed both success flashes,
  followed by ready with every logical output off. Recorded in
  `evidence/imx519-rpi2/led-events.json`.
- Full-resolution chart, text, and image-target lab captures completed without gallery upload.
- Boot sensor selection and service tuning survive a service restart; the boot
  overlay itself was verified by reboot.

## Portrait rendering follow-up

A later pass moved the camera farther from the chart and compared eight lab/
direct captures. No person was in those frames, so skin tone, facial texture,
and subject-motion quality are still unverified.

Selected starting preset:

- Separate tuning file `config/imx519-portrait.json` retains the AF fix and
  gently lifts the stock output gamma curve (`y → y^0.85`, normalized 0–1).
  Black and white endpoints remain unchanged. This is single-frame tone tuning,
  not HDR fusion or calibrated color processing.
- Saturation 1.15 and sharpening 1.15. Contrast 1, brightness 0, EV 0.
- Automatic white balance and gain, `sport` exposure, and automatic denoising.
- Continuous fast autofocus with the standard central portrait window.

The brighter +0.3 EV / contrast 1.08 variant washed out more of the bright chart.
The selected tone lift opens shadows without that extra exposure. In the
controlled tone pair, shutter was 19983 µs with gain about 4.6 and AfState 2 in
both frames. Baseline normal exposure was 29944 µs / gain about 3.1. Shorter
shutter reduces motion-blur risk but the static chart cannot quantify that gain.

Forced `cdn_hq` during the whole camera run caused two three-second captures to
report AfState 1 (searching), with visibly soft text. Returning to `auto`
produced three focused repeats. Raspberry Pi's [camera documentation](https://www.raspberrypi.com/documentation/computers/camera_software.html)
notes that forced high-quality denoising reduces viewfinder frame rate; auto
already selects high-quality color denoising for still images. Do not force
`cdn_hq` as a blanket quality upgrade.

The preset is saved for normal button/admin captures in the device `.env`.
`DAILY_MIRROR_CAMERA_ARGS` must be quoted because it contains spaces; an unquoted
trial was not applied by the environment loader and was corrected before final
verification. Previous settings are backed up as `.env.before-portrait-tuning`.
The lab uses `evidence/imx519-rpi2/portrait-lab-settings.json` with the same tuning
file. Its controls remain session settings; normal capture uses the saved args.

Recreate the full tuning file on the Pi with:

```sh
python3 scripts/prepare_imx519_tuning.py --shadow-exponent 0.85 /tmp/imx519-portrait.json
```

The script reproduced the installed tuning file byte for byte. Comparison
metadata is saved in `evidence/imx519-rpi2/portrait-comparison.json`.

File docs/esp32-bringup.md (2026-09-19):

# ESP32 camera bring-up notes

What it took to get a photo out of each board, recorded 2026-09-17 to 09-19 so
nobody has to rediscover it. The firmware itself lives in `firmware/esp-idf/`; the plan
is in [firmware-roadmap.md](firmware-roadmap.md).

## The two bench boards

| | ESP32-P4 board | ESP32-S3 board |
| --- | --- | --- |
| Chip | ESP32-P4 rev v1.3, 32 MB flash, 32 MB PSRAM | ESP32-S3 rev v0.2, 16 MB flash, 8 MB octal PSRAM |
| Board | Waveshare P4 family (JD9365 LCD and ES8311 codec in its BSP), ESP32-C6 radio over SDIO | Freenove ESP32-S3-WROOM CAM pinout |
| Camera | Arducam 16 MP IMX519 on MIPI CSI, I2C on GPIO 7/8, sensor at 0x1a, focus motor at 0x0c | OV5640 on DVP (XCLK 15, SDA 4, SCL 5, D0..D7 = 11, 9, 8, 10, 12, 18, 17, 16, VSYNC 6, HREF 7, PCLK 13) |
| Serial | CH343, 2 Mbaud console | CH340, 921600 baud console |
| LED | external RGB LED, GPIO 21/22/23 through 330 Ω each | onboard WS2812 on GPIO 48 |
| Button | GPIO 20 to GND | GPIO 1 to GND |

Wiring drawings: [S3](../hardware/wiring/s3_button_led.svg),
[P4](../hardware/wiring/p4_rgb_led.svg).

## Traps, in the order they bit

1. **The Arducam IMX519's focus motor is an AK7375, not a DW9714.** The
   Raspberry Pi overlay binds `asahi-kasei,ak7375`. It is a 12-bit DAC: write
   `code << 4` as a 16-bit value to register 0x00, and 0x00 / 0x40 to register
   0x02 for active / standby. With the DW9714 protocol the chip ACKs and the
   lens never moves: a focus sweep comes back perfectly flat. On our module the
   useful travel is codes 1024 to 2816, peaking near 2050 at about one metre.
2. **ISP statistics are garbage on ESP-IDF 5.4.0–5.4.3 and 5.5.0–5.5.2.** The
   prebuilt `libesp_ipa.a` expects a 5x5 white-balance sub-window grid inside
   `esp_ipa_stats_t`; those IDF versions compile it out, so every field after
   it is read from the wrong offset. Auto-exposure sees a black frame, the
   focus score is a float bit pattern. Either define
   `ISP_AWB_WINDOW_X_NUM=5` and `ISP_AWB_WINDOW_Y_NUM=5` project-wide or use
   5.5.3 or later. We use 5.5.5.
3. **ESP32-P4 silicon before rev v3.0 has no ISP black-level correction.**
   The driver returns "not supported" and esp_video swallows it, so black-level
   values in the tuning file do nothing. The sensor's pedestal then passes
   through the white-balance gains and the colour matrix and turns dark areas
   purple. A sensor solid-black test pattern comes out as exact black, which
   proves the pipeline adds nothing itself. Workaround: a gamma curve whose
   first points are zero. Real fix: a rev 3.x module. White-balance gain,
   crop and sub-window white balance are gated the same way.
4. **ESP-IDF 5.5.5 defaults the P4 minimum chip revision to v3.1**, and
   esptool then refuses to flash a rev 1.3 board. A failed flash leaves the old
   firmware running, which looks like "my change did nothing". Set
   `CONFIG_ESP32P4_SELECTS_REV_LESS_V3=y` and `CONFIG_ESP32P4_REV_MIN_100=y`,
   and always check for "Hash of data verified".
5. **The sensor has no reset line on the Pi-style connector**, so register
   state such as a test pattern survives reboots. The driver clears it on every
   mode set.
6. **Tuning borrowed from another sensor looks terrible.** The first P4 frames
   used an IMX708 file: strong colour matrix, contrast 130, heavy sharpening,
   a white-balance gain step of 0.5 that froze the gains, and gain allowed to
   reach 16x. The current file is a neutral starting point, not a calibration.
7. **Average metering blows out a bright subject in a dark room.** Use
   highlight-priority metering on the P4; on the OV5640 use manual exposure or
   more light.
8. **OV5640 autofocus needs its firmware blob loaded at boot** (about 4 KB to
   0x8000 over I2C), then command 0x03 and wait for status 0x10. A delay of
   `pdMS_TO_TICKS(5)` is zero ticks at the default 100 Hz tick rate, which
   turns a polling loop into a 0.6 s busy-wait that gives up too early.
9. **The default access-point subnet is 192.168.4.0/24.** That collides with
   this house's LAN, so the device's fallback access point uses 10.10.0.1.
10. **The P4's C6 radio ships with old firmware** (reports 0.0.0). Scanning and
    joining work; Espressif warns of RPC timeouts and it can be updated from
    the P4 over SDIO.
11. **If configure fails with "Missing required kconfig option after retry"**,
    run `idf.py fullclean` and delete `sdkconfig` and `dependencies.lock`.
12. **The P4's camera ribbon is marginal.** "Failed to detect camera sensor
    with address=1a", or frames that suddenly go solid black, mean reseat the
    cable before suspecting software.

## Host setup on the dev machine

- ESP-IDF v5.5.5 in `~/esp/esp-idf`, toolchains for `esp32p4` and `esp32s3`.
- Serial ports need the `uucp` group on Arch. Without logging out,
  `echo '<command>' | newgrp uucp` runs one command with the group.
- Espressif's clang wants a legacy `libxml2.so.2`; only the Rust spike needed
  it.

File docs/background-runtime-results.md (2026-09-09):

# Rust background lifecycle: live Vercel test

Verified 2026-09-07 on protected previews of `daily-mirror-bundle-trial`.
The diagnostic uses no photo storage, database, or application credentials.

| Runtime | HTTP response | Background ticks | Completion |
| --- | ---: | ---: | --- |
| Stock `vercel_runtime 2.4.0` | 0.303 seconds | 0 / 30 | Absent |
| Fin Streams lifecycle patch | 0.334 seconds | 30 / 30 | 30.034 seconds |

Each POST schedules thirty one-second waits using `nextrs::WaitUntil` and returns
immediately. After the POST, no further application requests were made to either
deployment. Logs were read through Vercel's control plane. Stock remained without
ticks after the full observation window. Patched logged every tick and completion.
This is one quiet-window run per runtime, not a concurrency/load or durability test.

- [Stock preview](https://daily-mirror-bundle-trial-gkreq0cy4-ashirsc.vercel.app)
- [Patched preview](https://daily-mirror-bundle-trial-qztm4v1n5-ashirsc.vercel.app)
- Preview deployment IDs: `dpl_7oDg1rEzrJn5yMfEj2Rbrg661BMv` (stock),
  `dpl_9HQdT6FKcnCCByHCnkveXVkgSt3b` (patched).
- Raw local probe events were lost during a workstation restart; the observations above were recorded before that restart.
- Probe source: `../tools/background-probe/src/main.rs`.

The pinned NextRS revision `9fa4141d145f5afba869a42857e601c08a74e5fc` already
provides `WaitUntil`. Its adapter forwards tasks to `AppState.wait_until`; the
problem is below that API. Stock Rust runtime reports the invocation's IPC `end`
before its registered work settles. The Fin Streams patch creates a per-request
collector and delays that signal while allowing the HTTP response to return.

Patch source: Fin Streams commit `0d3d23a543910852b78a3cc6fa209146403cf4c5`.
Its historical experiment is in commit `873911584aad761528c3855c7aeb8f01cae7418c`.
The patch is vendored under `../vendor/vercel_runtime` and selected by the server's
Cargo patch. The exact NextRS pin remains unchanged. Local regression tests prove
that one request cannot drain another's tasks, nested work is awaited, and a
background panic does not abort draining. Both passed.

The preview reports glibc 2.34, above the existing MediaPipe library's 2.27 minimum.
Actual native inference was subsequently verified in production; see
`vercel-image-processing-results.md` for package sizes, timing and result checks.

Keep durable work in the existing database queue. `WaitUntil` does not provide
retries, crash recovery or exactly-once execution. The eventual worker should
return success only after committing its result; use the lifecycle extension for
bounded dispatch work, with recovery for failed dispatches.

## Deployment notes

`vercel curl` successfully generated a project protection-bypass token using the
existing CLI login. Anonymous requests to the patched preview redirect to access
protection (HTTP 302); the probe POST through the CLI returned HTTP 200. No bypass
token is stored in this report.

Vercel automatically promoted the empty project's first diagnostic deployment
despite a default preview deploy command. That deployment was removed. Both URLs
above were then created with explicit `--target=preview`, and their runtime logs
confirm `environment=preview`. Daily Mirror production was untouched.

## Reproduce

Build `tools/background-probe/Cargo.toml` with `cargo zigbuild --release --target
x86_64-unknown-linux-gnu.2.26`. Set `PROBE_RUNTIME_LABEL=patched-2.4.0`. For the stock
control, use a disposable copy of the probe without its Cargo patch section and
with a separately resolved lockfile; label it `stock-2.4.0`.

Package each executable as a Rust executable function using the Vercel Build
Output API, with `supportsResponseStreaming=true` and `maxDuration=60`. Route
requests to that diagnostic function. This standalone probe is separate from the
framework-generated Daily Mirror deployment. Link only the isolated trial project
and deploy with `vercel deploy --prebuilt --target=preview --yes`.

POST `{"run_id":"unique-test-name"}` to `/probe` with `vercel curl --deployment
<url>`. Wait at least 40 seconds without application requests, then read
`vercel logs <url> --json --expand --since 10m`. Count all thirty ticks and the
completion event; record HTTP latency independently of task completion.

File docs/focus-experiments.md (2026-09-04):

# Focus & sharpness experiments (2026-09-02/04)

**2026-09-04, second update — the real root cause was sensor rotation.**
Production captures were focusing at infinity (LensPosition ~0.0) while
identical SSH test invocations focused correctly. The difference: the
device appends the saved orientation (`--rotation 180`, the camera is
mounted upside down) to still captures. Flipping the IMX519 readout
changes the Bayer phase and breaks AF: on the same static scene, AF landed
at ~1.2 (FocusFoM ~15.5k) with any flip vs ~2.5 (FocusFoM ~29.2k) without,
and with a subject in production it collapsed to 0. Fix (shipped): stills
capture unrotated and the JPEG is rotated losslessly afterward with
`jpegtran -rotate 180` (requires `libjpeg-turbo-progs` on the Pi); the lab
live preview keeps sensor rotation since it is only used for framing.
Verified end to end: a production capture via `/api/actions/capture` now
lands at LensPosition 2.48, matching the measured scene peak.

**2026-09-04 update — root cause found with a person in frame (lights on,
Lux ≈ 60):** the production AF config had no `--autofocus-window`, so AF
averaged the whole scene and consistently landed 0.4–0.5 dioptres *behind*
the subject's face — visibly soft at the ~30–40 cm distance people stand
from the mirror, where depth of field is millimeters. Adding a centered
window (`--autofocus-window 0.3,0.3,0.4,0.4`) made AF land dead-on and
perfectly repeatable (lens position 2.57–2.61 over three runs) and more
than doubled measured center sharpness (152–157 vs 61–71), beating even the
best manual lens position from the sweep. Even with room lights on, auto
exposure still maxed out at 60 ms shutter, so `--exposure sport` (44 ms)
stays recommended and daylight remains the crisp-motion case. The
recommended args below include the window.

Empirical results from ~40 captures on the actual Pi (`rpi1.local`, Arducam
16MP IMX519) using `scripts/focus_sweep.py`. Each capture logged rpicam
metadata and was scored with variance-of-Laplacian on a center crop, then
key crops were inspected visually. Run conditions: pre-dawn living room,
**Lux ≈ 4** (very dark) — rerun in real usage light before locking anything in.

## Finding 1: autofocus works; manual dioptre calibration was a dead end

The manual lens sweep (0.0 → 3.0 dioptres) peaked at **~2.6 dioptres**
(sharpness 70.6). The production AF config (`--autofocus-mode auto
--autofocus-on-capture`, from the Pi's `.env`) landed at 2.34–2.44 on every
repeat — right at the peak. The lab default preset of **0.82 dioptres scored
3× worse** (20.4) and is visibly out of focus.

Related trap: the admin lab's focus calibration is **temporary** — only
camera orientation persists (`device/src/lab.rs:252`). Real captures use the
`.env` `DAILY_MIRROR_CAMERA_ARGS`, so lab dioptre tweaking never affected
production captures. Tweaking dioptres was never going to fix blur.

## Finding 2: light is the real bottleneck

Every auto-exposed capture metered **60 ms shutter (1/17 s) at 4.4× analogue
gain**. Two consequences:

- **Motion blur**: at 1/17 s a person swaying normally moves several mm
  during the exposure — many pixels at 16 MP portrait distance. No focus
  setting can fix this.
- **Noise smear**: high gain forces the ISP denoiser to eat fine detail
  (skin/hair texture), reading as "soft".

For crisp people you want ≤ ~10 ms (1/100 s). At Lux 4 that needs ~26× gain
(max is 16) — i.e. **the room needs more light**, not a better sensor. A ring
light / LED strip at the mirror is the single highest-impact fix.

## Finding 3: settings grid (at locked best focus)

| Setting | Metric | Visual verdict |
|---|---|---|
| baseline (defaults) | 70.9 | reference |
| `--denoise cdn_hq` | 69.5 | no visible gain |
| `--denoise off` | 82.8 | metric is noise, not detail — grainy |
| `--sharpness 0.5` | 53.5 | softer, worse |
| `--sharpness 1.5` | 83.0 | **crisper, no artifacts — safe win** |
| `--sharpness 2.0` | 99.0 | good; slight texture crunch |
| `--sharpness 3.0` | 150.1 | over-sharpened, noisy — reject |
| `--exposure sport` | 78.4 | 44 ms @ gain 6 — less motion blur, worth it |
| `--shutter 30000 --gain 8` | 85.7 | same brightness, half the motion blur |
| `--shutter 20000 --gain 12` | 112.6 | dimmer, noisier, but motion-blur-proof |

## Recommended production args

Update `DAILY_MIRROR_CAMERA_ARGS` in the Pi's
`/home/drew/daily-mirror-device/.env`:

```
--nopreview --timeout 3000 --autofocus-mode auto --autofocus-on-capture \
--autofocus-window 0.3,0.3,0.4,0.4 \
--width 4656 --height 3496 --encoding jpg --quality 95 \
--sharpness 1.5 --exposure sport --metadata - --metadata-format json
```

Changes vs current: `--autofocus-window 0.3,0.3,0.4,0.4` (the root-cause
fix — see the 2026-09-04 update above), `--sharpness 1.5` (visually
crisper, artifact-free),
`--exposure sport` (biases toward short shutter — big deal in daylight,
mild gain cost at night), and restoring `--metadata -` so every real capture
logs `LensPosition` / `ExposureTime` / `AnalogueGain` / `AfState` to the
journal for future diagnosis (the defaults in `main.rs` include this; the
`.env` override had dropped it).

## Rerun checklist (daylight, before finalizing)

1. Put a face or newspaper where subjects actually stand, in usage lighting.
2. `scp scripts/focus_sweep.py drew@rpi1.local:~/ && ssh drew@rpi1.local 'python3 ~/focus_sweep.py --grid'`
3. Check `ExposureTime` in the output: if it's still > ~15 ms in usage
   lighting, add light at the mirror.
4. Eyeball crops in the run's `crops/` dir — the Laplacian metric inflates
   with noise and over-sharpening; trust eyes for ties.

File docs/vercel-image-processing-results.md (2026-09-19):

# Vercel image processing verification

Verified September 7, 2026 (Mountain time), on production
[Daily Mirror](https://daily-mirror-pearl.vercel.app).
Final deployment: `dpl_J1gW7ZK55Cb8ZkAv5b3MBrgfj16c`,
[immutable URL](https://daily-mirror-1oyf0lama-ashirsc.vercel.app).
All three functions run in `pdx1`. Existing native password/passkey APIs and
Apple association were preserved from the concurrently deployed mobile work.

## What runs where

- `default`: pages, authentication, queue coordination, identity APIs and recovery cron.
- `images`: upload finalization, JPEG/WebP handling, thumbnails, rotation and crops.
- `vision`: existing YuNet detection, MediaPipe landmarks, SFace embeddings and
  database completion with conservative identity proposals.

An upload persists the job before starting a NextRS `WaitUntil` notification.
The worker claims one photo, renews its lease independently of native inference,
commits results, then notifies the next worker. A database lease serializes hosted
inference across instances. Five attempts is the limit; exhausted jobs remain
visible as failed. Crashed workers become eligible after lease expiry.
No separate queue service was added.

Recovery uses `#[nextrs::cron(schedule = "*/5 * * * *", provider = "cloudflare")]`
and `nextrs cron deploy`. The generated Cloudflare worker is only a timer;
processing remains on Vercel. The recovery HTTP request awaits a worker response.
The original daily reconciliation cron remains on Vercel. The shared cron secret
was synchronized on both providers; the local copy is in ignored `server/.env.local`.

## Measured function sizes

File lengths of final generated, uncompressed function trees:

| Function | Executable bytes | Native libraries | Models | Other | Total bytes | MiB |
| --- | ---: | ---: | ---: | ---: | ---: | ---: |
| default | 19,901,048 | 0 | 0 | 203 | 19,901,251 | 18.98 |
| images | 14,398,584 | 0 | 0 | 203 | 14,398,787 | 13.73 |
| vision | 13,951,240 | 65,598,512 | 42,687,538 | 203 | 122,237,493 | 116.57 |

Combined: **156,537,531 bytes**. An equivalent unsplit executable with both features
is **23,173,912 bytes**: the default executable is **3,272,864 bytes (14.12%) smaller**.
The unsplit baseline was compiled, not separately packaged. The vision function
has 127,762,507 bytes of headroom against 250,000,000 bytes before any provider
layers; provider-layer accounting is unavailable locally.

Vercel CLI separately reports **7.66 MB / 5.86 MB / 65.56 MB** for the deployed
functions. Those are provider-reported sizes, not the uncompressed file totals
above. Do not compare the two metrics directly. Exact inventories, hashes,
features and toolchain information are in [bundle-sizes.json](evidence/bundle-sizes.json).

## Verification

- 42 Rust unit tests, 2 native-session integration tests, 2 native-passkey
  integration tests, and 2 patched-runtime lifecycle regressions pass.
- Pinned NextRS client generation and TypeScript typecheck pass.
- 12 tests against the actual packaged Vercel adapters pass, including real native
  inference, isolated assets/routes, authorization, duplicate delivery and missed
  upload notification recovery. [Local evidence](evidence/local-packaged-verification.json).
- Real production face processing saved **478 landmarks**, a **128-value embedding**
  and an existing-library identity proposal (`centroid-v1`, score about 0.75).
  Warm request: **1,269 ms**, model load **0 ms**, peak process RSS **469,180 KiB**.
  Initial cold request: **3,005 ms**, model load **1,077 ms**, peak RSS **419,788 KiB**.
  These are individual observations, not load-test percentiles or a cost estimate.
- A production R2 signed upload finalized in **1.14 seconds** and completed
  automatically on its first attempt. No follow-up function request was made for
  30 seconds; the result was checked through the database. That worker chain also
  drained the eight originally pending photos. [Live evidence](evidence/live-inference-and-upload.json).
- The actual five-minute scheduled tick recovered a synthetic photo uploaded
  through the old deployment (which has no notification): pending/attempt 0 became
  complete/attempt 1 at `2026-09-08 04:46:04 UTC`. The generated timer logged HTTP
  **200**, with 3,483 ms wall time. No manual worker or cron request triggered it.
  [Scheduled recovery evidence](evidence/live-scheduled-recovery.json),
  [timer delivery log](evidence/cron-delivery.json).
- Final web login page hydrates with no observed console errors. Signed-in browser
  gallery navigation was not exercised because this browser has no active session;
  authentication and passkey behavior were covered by integration tests.

The three synthetic verification photos and their thumbnails/database records were
removed afterward. Final production queue: **59 complete, 0 pending, 0 leased,
0 failed**. All eight original pending images are processed.

## Operations and limitations

### Hosted inference concurrency

`DAILY_MIRROR_HOSTED_CONCURRENCY` sets how many hosted inference workers may
hold a lease at once. It defaults to `1`, must parse as a whole number from `1`
to `8`, and an out-of-range or unparseable value is rejected when the worker
reads it rather than silently falling back, so a typo makes the invocation fail
visibly instead of quietly changing throughput. The variable belongs on the
vision bundle, which is where the claim gate runs; the web bundles only dispatch
to it. Each invocation still claims exactly one photo, so the variable is purely
a cap on how many invocations may be mid-inference for one pipeline version.
Raising it changes nothing else: per-photo dispatch from upload finalization,
the chained dispatch of the next photo, five-minute leases and the recovery cron
all behave as before, and a worker that finds the queue empty or already at the
limit returns its fast `idle-or-busy` report without claiming.

The ceiling is memory, not CPU. A single warm inference peaked at **469,180 KiB**
(about 470 MB) of process RSS on the 2 GB function measured above, and the
MediaPipe engine is cached per process, so concurrent invocations do not share
that cost. Four concurrent workers therefore sit near 1.9 GB of the 2 GB budget
with nothing left for the JPEG buffers and runtime overhead that ride along with
each request, which makes **4 the sensible ceiling on the default plan** and 2 or
3 the comfortable operating range; the allowed maximum of 8 is only reachable on
a function with a larger memory size. Exceeding the real budget does not degrade
gracefully — the function is OOM-killed mid-inference, which drops the lease
without a result, and the photo waits for its five-minute lease to expire before
the recovery cron retries it, so over-provisioning trades a small latency win for
much worse tail latency.

The compatible native build remains a prepared-cache workflow: see
[scripts/native/README.md](../scripts/native/README.md). Private models/libraries
are ignored build assets and must be preserved or restored from their upstream
sources. No assets are downloaded during a function invocation.

The temporary runtime patch is still required for reliable `WaitUntil` execution;
see [background-runtime-results.md](background-runtime-results.md). It fixes the
invocation lifetime, while the database and cron supply recovery. No sustained
load test or live forced-process-crash test was performed.

A different task deployed production during verification. Those newer native-auth
files were incorporated without changes, then the combined build was redeployed.
Original checkout modifications remain untouched; this implementation lives on
`codex/vercel-image-processing`. Future deployments must include these changes or
will remove hosted processing again.

Rollback: redeploy the previous native-auth production deployment
`dpl_CHg4tw5HYnd6jkDSKrw6WE9mxpdw` and resume the existing desktop processor.
Set `DAILY_MIRROR_HOSTED_PROCESSING=0` on a newly deployed build to disable hosted
processing. Existing leases expire; disabling does not cancel an invocation already
running. Keep the shared cron secret consistent when redeploying older source.

## PR preparation

Rebased onto `60d3872` after native authentication merged in PRs #6 and #7.
The PR preserves main's expanded session tests and removes duplicate native-auth
changes from its diff. Application behavior matches the verified deployment;
subsequent changes are formatting and test coverage. The artifact inventories
above describe the deployed build, before that history/formatting cleanup.
The recovery endpoint was invoked again while preparing the PR: HTTP 200,
59 complete and no pending, leased, or failed jobs.

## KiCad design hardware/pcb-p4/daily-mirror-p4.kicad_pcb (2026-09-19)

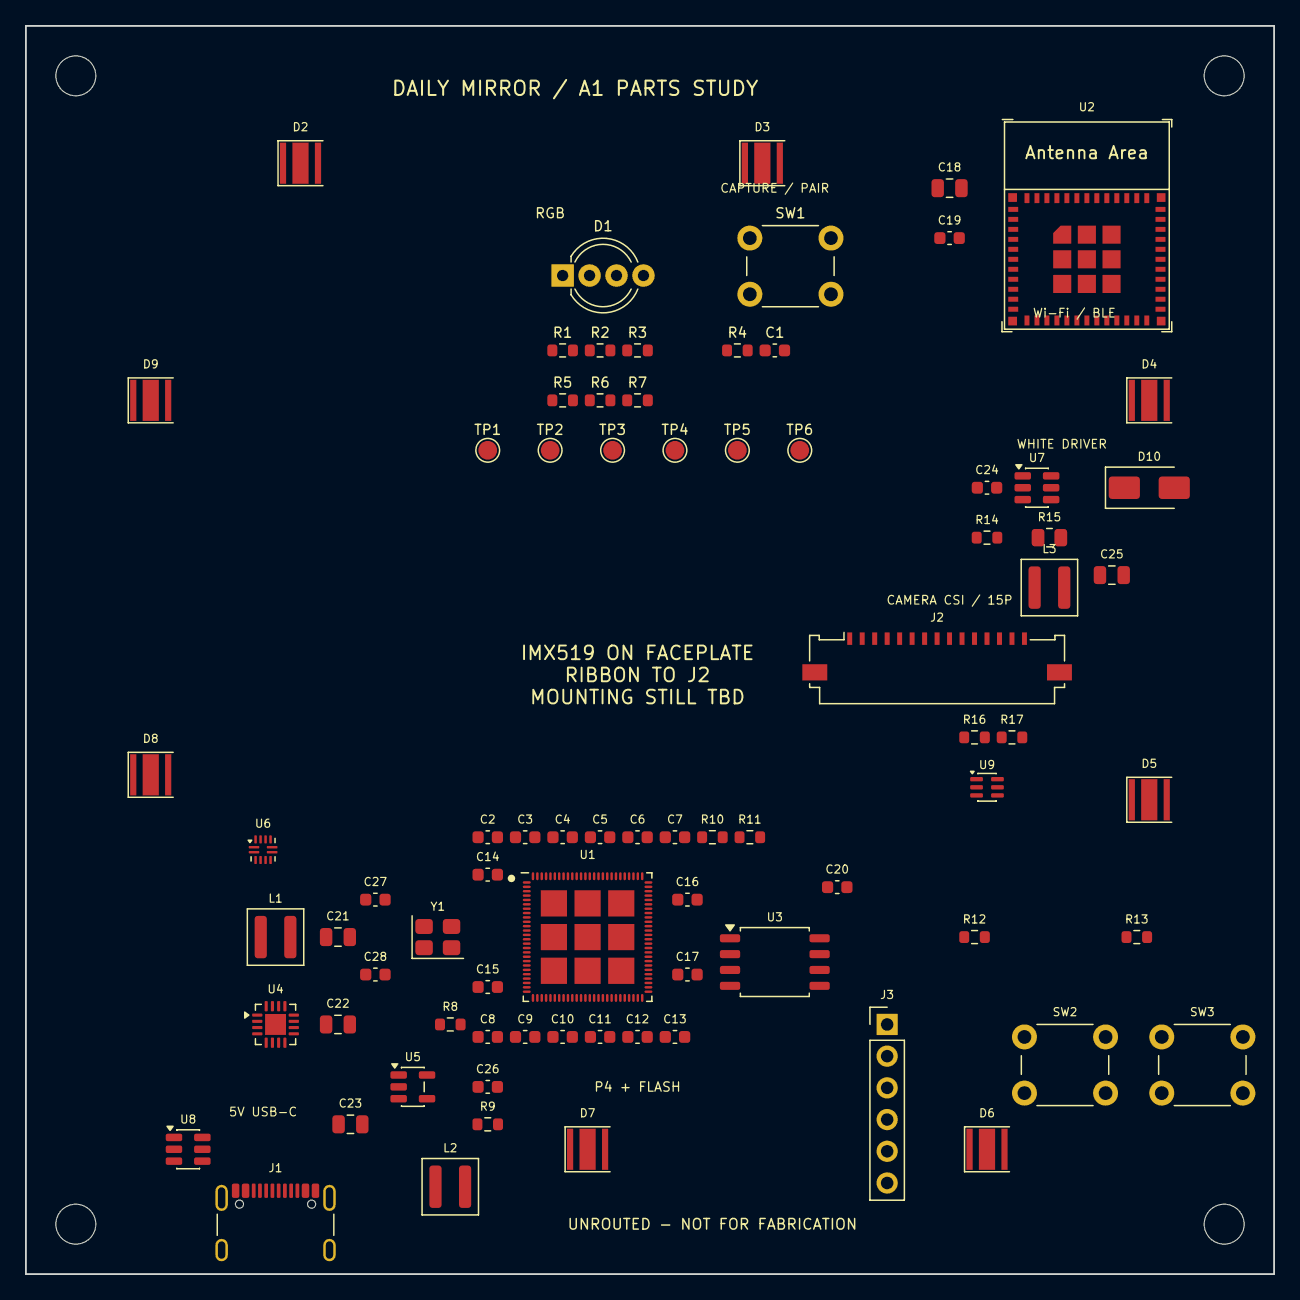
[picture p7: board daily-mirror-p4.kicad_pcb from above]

Board: 4 copper layers, 100.0 x 100.0 mm, 84 parts (0 on the bottom side), 9 nets, no tracks yet.

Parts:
C1, C2, C3, C4, C5, C6, C7, C8, C9, C10, C11, C12, C13, C14, C15, C16, C17, C19, C20, C24: 100nF; C_0603_1608Metric
C18, C21, C22, C23: 10uF; C_0805_2012Metric
C25: 1uF; C_0805_2012Metric
C26: 22pF; C_0603_1608Metric
C27, C28: TUNE pF; C_0603_1608Metric
D1: RGB common anode; LED_D5.0mm-4_RGB_Wide_Pins
D2, D3, D4, D5, D6, D7, D8, D9: White 5000 K / CRI90; LED_Cree-XP-G
D10: SS16-E3/61T; D_SMA
H1, H2, H3, H4: MountingHole_3.2mm_M3
J1: USB-C / 5 V; USB_C_Receptacle_GCT_USB4105-xx-A_16P_TopMnt_Horizontal
J2: Pi-style CSI camera - 15 pin; Molex_200528-0150_1x15-1MP_P1.00mm_Horizontal
J3: Service UART / boot; PinHeader_1x06_P2.54mm_Vertical
L1, L2: 2.2 uH; L_Coilcraft_XAL4020-XXX
L3: 10 uH; L_Coilcraft_XAL4040-XXX
R1, R2, R3: 1k (start); R_0603_1608Metric
R4, R12, R13: 10k; R_0603_1608Metric
R5, R6, R7, R14: 100k; R_0603_1608Metric
R8, R9: 499k; R_0603_1608Metric
R10, R11: 4.02k; R_0603_1608Metric
R15: 2 ohm; R_0805_2012Metric
R16, R17: 2.2k; R_0603_1608Metric
SW1: Momentary NO; SW_PUSH_6mm_H4.3mm
SW2: RESET; SW_PUSH_6mm_H4.3mm
SW3: BOOT; SW_PUSH_6mm_H4.3mm
TP1: +3V3; TestPoint_Pad_D1.5mm
TP2: GND; TestPoint_Pad_D1.5mm
TP3: STATUS_B_N; TestPoint_Pad_D1.5mm
TP4: STATUS_G_N; TestPoint_Pad_D1.5mm
TP5: STATUS_R_N; TestPoint_Pad_D1.5mm
TP6: USER_BUTTON_N; TestPoint_Pad_D1.5mm
U1: ESP32-P4NRW32X; ESP32-P4
U2: ESP32-C6-MINI-1-N4; ESP32-C6-MINI-1
U3: W25Q128JVSIQ; SOIC-8_5.3x5.3mm_P1.27mm
U4: TPS62132RGTR; VQFN-16-1EP_3x3mm_P0.5mm_EP1.68x1.68mm
U5: TLV62569DBVR; SOT-23-5
U6: TUSB320IRWBR; Texas_X2QFN-12_1.6x1.6mm_P0.4mm
U7: TPS61165DBVR; SOT-23-6
U8: USBLC6-2SC6; SOT-23-6
U9: TPS22919DCKR; SOT-363_SC-70-6
Y1: 40 MHz / 10 pF; Crystal_SMD_3225-4Pin_3.2x2.5mm

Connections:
/+3V3: D1.3, R4.1, R5.1, R6.1, R7.1, TP1.1
/GND: C1.2, SW1.2, TP2.1
/LED_B_K: D1.1, R1.2
/LED_G_K: D1.2, R2.2
/LED_R_K: D1.4, R3.2
/STATUS_B_N: R1.1, R5.2, TP3.1
/STATUS_G_N: R2.1, R6.2, TP4.1
/STATUS_R_N: R3.1, R7.2, TP5.1
/USER_BUTTON_N: C1.1, R4.2, SW1.1, TP6.1

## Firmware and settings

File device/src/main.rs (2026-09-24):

use std::collections::BTreeMap;
use std::convert::Infallible;
use std::fs::{self, File};
use std::io::{Read, Seek, SeekFrom};
use std::path::{Path, PathBuf};
use std::process::{Child, Command};
use std::sync::atomic::{AtomicBool, Ordering};
use std::sync::{Arc, Mutex, RwLock};
use std::thread;
use std::time::{Duration, Instant};

use anyhow::{Context, Result, anyhow, bail};
use axum::body::Body;
use axum::extract::{Path as AxumPath, State};
use axum::http::StatusCode;
use axum::response::sse::{Event, KeepAlive, Sse};
use axum::response::{Html, IntoResponse, Response};
use axum::routing::{get, post};
use axum::{Json, Router};
use chrono::Utc;
use clap::{Parser, Subcommand};
use reqwest::blocking::Client;
use reqwest::header::{AUTHORIZATION, CONTENT_LENGTH, HeaderName, HeaderValue};
use reqwest::{Method, Url};
use rppal::gpio::{Gpio, InputPin, OutputPin};
use serde::{Deserialize, Serialize};
use tokio::sync::watch;
use uuid::Uuid;

mod camera_profile;
mod capture_metadata;
mod capture_mode;
use capture_metadata::{CaptureMetadata, CaptureSidecar, CaptureTrigger};
mod photo_settings;
use photo_settings::PhotoSettings;
mod lab;
use camera_profile::CameraProfile;
use capture_mode::CaptureMode;
mod led;
mod local_photos;

use led::LedMode;

use lab::{CameraLab, CameraOrientation, LabSettings, load_orientation};

const RETRY_INTERVAL: Duration = Duration::from_secs(60);
const BUTTON_POLL_INTERVAL: Duration = Duration::from_millis(20);
const DEBOUNCE_INTERVAL: Duration = Duration::from_millis(60);

#[derive(Parser)]
#[command(about = "Raspberry Pi camera, button, LED, and upload service for Daily Mirror")]
struct Cli {
    #[command(subcommand)]
    command: DeviceCommand,
}

#[derive(Subcommand)]
enum DeviceCommand {
    /// Take one photograph. The durable queue retains it if upload fails.
    CaptureOnce {
        /// Keep the captured JPEG locally without attempting an upload.
        #[arg(long)]
        no_upload: bool,
    },
    /// Queue and upload an existing JPEG. Useful before GPIO is wired.
    Upload { path: PathBuf },
    /// Retry every JPEG already in the durable queue.
    Retry,
    /// Run continuously with the physical button and configured status LEDs.
    Run,
}

#[derive(Clone, Debug)]
struct Config {
    server_url: Option<String>,
    /// The legacy shared Pi upload token. Photographs sent with it land as
    /// `capture_source: legacy` with no device attached.
    upload_token: Option<String>,
    /// This camera's own token, issued when it paired. Preferred over the
    /// shared token for every server call when it is configured.
    device_token: Option<String>,
    queue_dir: PathBuf,
    camera_command: String,
    camera_args: Vec<String>,
    camera_settings_path: PathBuf,
    admin_bind: String,
    button_pin: u8,
    green_led_pin: u8,
    yellow_led_pin: u8,
    red_led_pin: u8,
    led_mode: LedMode,
    camera_profile: CameraProfile,
    photo_settings: Arc<RwLock<PhotoSettings>>,
    photo_settings_path: PathBuf,
    local_dir: PathBuf,
}

impl Config {
    fn from_env() -> Result<Self> {
        let camera_profile = CameraProfile::parse(
            &std::env::var("DAILY_MIRROR_CAMERA_PROFILE").unwrap_or_else(|_| "imx519".into()),
        )?;
        let capture_mode = CaptureMode::parse(
            &std::env::var("DAILY_MIRROR_CAPTURE_MODE").unwrap_or_else(|_| "upload".into()),
        )?;
        let camera_command = std::env::var("DAILY_MIRROR_CAMERA_COMMAND")
            .unwrap_or_else(|_| detect_camera_command());
        let camera_args = std::env::var("DAILY_MIRROR_CAMERA_ARGS")
            .ok()
            .map(|value| shlex::split(&value).ok_or_else(|| anyhow!("invalid camera arguments")))
            .transpose()?
            .unwrap_or_else(|| camera_profile.capture_args());

        let queue_dir = std::env::var_os("DAILY_MIRROR_QUEUE_DIR")
            .map(PathBuf::from)
            .unwrap_or_else(|| PathBuf::from("data/pending"));
        let local_dir = std::env::var_os("DAILY_MIRROR_LOCAL_DIR")
            .map(PathBuf::from)
            .unwrap_or_else(|| PathBuf::from("data/local"));
        fs::create_dir_all(&queue_dir)?;
        fs::create_dir_all(&local_dir)?;
        if fs::canonicalize(&queue_dir)? == fs::canonicalize(&local_dir)? {
            bail!("Local photo directory must be separate from the upload queue");
        }
        let photo_settings_path = std::env::var_os("DAILY_MIRROR_PHOTO_SETTINGS_PATH")
            .map(PathBuf::from)
            .unwrap_or_else(|| PathBuf::from("data/photo-settings.json"));
        let photo_settings = match fs::read(&photo_settings_path) {
            Ok(bytes) => serde_json::from_slice::<PhotoSettings>(&bytes)
                .context("read saved photo settings")?,
            Err(error) if error.kind() == std::io::ErrorKind::NotFound => PhotoSettings {
                test_mode: capture_mode == CaptureMode::Local,
                profile: "configured".into(),
            },
            Err(error) => return Err(error.into()),
        };
        photo_settings.validate(camera_profile)?;
        Ok(Self {
            camera_profile,
            photo_settings: Arc::new(RwLock::new(photo_settings)),
            photo_settings_path,
            local_dir,
            server_url: std::env::var("DAILY_MIRROR_SERVER_URL").ok(),
            upload_token: non_empty("DAILY_MIRROR_UPLOAD_TOKEN"),
            device_token: non_empty("DAILY_MIRROR_DEVICE_TOKEN"),
            queue_dir,
            camera_command,
            camera_args,
            camera_settings_path: std::env::var_os("DAILY_MIRROR_CAMERA_SETTINGS_PATH")
                .map(PathBuf::from)
                .unwrap_or_else(|| PathBuf::from("data/camera-settings.json")),
            admin_bind: std::env::var("DAILY_MIRROR_ADMIN_BIND")
                .unwrap_or_else(|_| "0.0.0.0:8080".to_owned()),
            button_pin: env_pin("DAILY_MIRROR_BUTTON_PIN", 2)?,
            green_led_pin: env_pin("DAILY_MIRROR_GREEN_LED_PIN", 17)?,
            yellow_led_pin: env_pin("DAILY_MIRROR_YELLOW_LED_PIN", 27)?,
            red_led_pin: env_pin("DAILY_MIRROR_RED_LED_PIN", 22)?,
            led_mode: LedMode::parse(
                &std::env::var("DAILY_MIRROR_LED_MODE").unwrap_or_else(|_| "discrete".to_owned()),
            )?,
        })
    }

    fn capture_mode(&self) -> CaptureMode {
        self.photo_settings
            .read()
            .unwrap_or_else(|e| e.into_inner())
            .mode()
    }

    fn upload_url(&self) -> Result<String> {
        let base = self
            .server_url
            .as_deref()
            .ok_or_else(|| anyhow!("DAILY_MIRROR_SERVER_URL is required for uploads"))?;
        Ok(format!("{}/api/uploads", base.trim_end_matches('/')))
    }
}

fn main() -> Result<()> {
    dotenvy::dotenv().ok();
    let cli = Cli::parse();
    let config = Config::from_env()?;
    if matches!(cli.command, DeviceCommand::CaptureOnce { no_upload: true }) {
        config.photo_settings.write().unwrap().test_mode = true;
    }
    let device = Device::new(config)?;

    match cli.command {
        DeviceCommand::CaptureOnce { no_upload } => {
            let capture = device.camera.capture(CaptureTrigger::Cli)?;
            println!("captured {}", capture.display());
            if !no_upload && device.config.capture_mode() == CaptureMode::Upload {
                match device.uploader.upload(&capture) {
                    Ok(()) => println!("uploaded {}", capture.display()),
                    Err(error) => {
                        eprintln!("upload failed; retained for retry: {error:#}");
                    }
                }
            }
        }
        DeviceCommand::Upload { path } => {
            if device.config.capture_mode() == CaptureMode::Local {
                bail!("Uploads are disabled in local mode");
            }
            let queued = device.camera.queue_existing(&path)?;
            device.uploader.upload(&queued)?;
            println!("uploaded {}", path.display());
        }
        DeviceCommand::Retry => {
            let remaining = device.uploader.retry_all()?;
            println!("retry complete; {remaining} photo(s) remain queued");
        }
        DeviceCommand::Run => device.run()?,
    }
    Ok(())
}

struct Device {
    config: Config,
    camera: Camera,
    uploader: Uploader,
    operation_lock: Arc<Mutex<()>>,
    runtime_status: watch::Sender<RuntimeStatus>,
    started_at: Instant,
}

impl Device {
    fn new(config: Config) -> Result<Self> {
        let camera = Camera::new(&config)?;
        let uploader = Uploader::new(&config)?;
        let (runtime_status, _) = watch::channel(RuntimeStatus::default());
        Ok(Self {
            config,
            camera,
            uploader,
            operation_lock: Arc::new(Mutex::new(())),
            runtime_status,
            started_at: Instant::now(),
        })
    }

    fn run(&self) -> Result<()> {
        let gpio = Gpio::new().context("initialize Raspberry Pi GPIO")?;
        let button = gpio
            .get(self.config.button_pin)
            .with_context(|| format!("open button GPIO {}", self.config.button_pin))?
            .into_input_pullup();
        let leds = Arc::new(Mutex::new(LedPanel::new(
            &gpio,
            &self.config,
            self.runtime_status.clone(),
        )?));
        let lab = CameraLab::new(
            Arc::clone(&self.camera.camera_lock),
            Arc::clone(&self.camera.orientation),
            self.camera.orientation_path.clone(),
            self.config.camera_profile,
        );
        let led_test_active = Arc::new(AtomicBool::new(false));
        self.start_admin_server(Arc::clone(&leds), Arc::clone(&led_test_active), lab.clone())?;
        let mut last_retry = Instant::now() - RETRY_INTERVAL;

        println!(
            "ready: button BCM {}, LEDs green/yellow/red BCM {}/{}/{}",
            self.config.button_pin,
            self.config.green_led_pin,
            self.config.yellow_led_pin,
            self.config.red_led_pin
        );

        loop {
            if last_retry.elapsed() >= RETRY_INTERVAL {
                let _operation = self
                    .operation_lock
                    .lock()
                    .unwrap_or_else(|poisoned| poisoned.into_inner());
                let retry_result = self.uploader.retry_all();
                let test_active = led_test_active.load(Ordering::Relaxed);
                let remaining = match retry_result {
                    Ok(remaining) => {
                        if !test_active {
                            let message = if remaining == 0 {
                                "Ready".to_owned()
                            } else {
                                format!("Ready; {remaining} photo(s) waiting to upload")
                            };
                            set_runtime_status(&self.runtime_status, "ready", message);
                        }
                        remaining
                    }
                    Err(error) => {
                        eprintln!("queued upload retry failed: {error:#}");
                        if !test_active {
                            set_runtime_status(
                                &self.runtime_status,
                                "error",
                                format!("queued upload retry failed: {error:#}"),
                            );
                        }
                        1
                    }
                };
                if !test_active {
                    leds.lock()
                        .unwrap_or_else(|poisoned| poisoned.into_inner())
                        .ready(remaining > 0);
                }
                last_retry = Instant::now();
            }

            if button.is_low() && pressed_after_debounce(&button) {
                led_test_active.store(false, Ordering::Relaxed);
                if let Err(error) = lab.stop_preview() {
                    eprintln!("stop lab preview for physical capture: {error:#}");
                }
                self.capture_cycle(&leds);
                wait_for_release(&button);
                last_retry = Instant::now();
            }
            thread::sleep(BUTTON_POLL_INTERVAL);
        }
    }

    fn capture_cycle(&self, leds: &Arc<Mutex<LedPanel>>) {
        let _operation = self
            .operation_lock
            .lock()
            .unwrap_or_else(|poisoned| poisoned.into_inner());
        set_runtime_status(
            &self.runtime_status,
            "countdown",
            "Get ready — camera starting",
        );
        let pending = match self.camera.start_capture(CaptureTrigger::Button) {
            Ok(pending) => pending,
            Err(error) => {
                eprintln!("capture failed: {error:#}");
                set_runtime_status(
                    &self.runtime_status,
                    "error",
                    format!("capture failed: {error:#}"),
                );
                leds.lock()
                    .unwrap_or_else(|poisoned| poisoned.into_inner())
                    .error();
                return;
            }
        };
        leds.lock()
            .unwrap_or_else(|poisoned| poisoned.into_inner())
            .countdown();
        set_runtime_status(
            &self.runtime_status,
            "capturing",
            "Countdown complete — taking the photo",
        );
        let capture = match pending.finish() {
            Ok(path) => path,
            Err(error) => {
                eprintln!("capture failed: {error:#}");
                set_runtime_status(
                    &self.runtime_status,
                    "error",
                    format!("capture failed: {error:#}"),
                );
                leds.lock()
                    .unwrap_or_else(|poisoned| poisoned.into_inner())
                    .error();
                return;
            }
        };

        set_runtime_status(
            &self.runtime_status,
            "processing",
            self.config.capture_mode().processing_message(),
        );
        leds.lock()
            .unwrap_or_else(|poisoned| poisoned.into_inner())
            .begin_processing();
        let upload = leds
            .lock()
            .unwrap_or_else(|poisoned| poisoned.into_inner())
            .while_processing(|| self.uploader.upload(&capture));
        match upload {
            Ok(()) => {
                set_runtime_status(
                    &self.runtime_status,
                    "success",
                    self.config.capture_mode().success_message(),
                );
                leds.lock()
                    .unwrap_or_else(|poisoned| poisoned.into_inner())
                    .success();
                set_runtime_status(&self.runtime_status, "ready", "Ready");
            }
            Err(error) => {
                eprintln!("upload failed; retained for retry: {error:#}");
                set_runtime_status(
                    &self.runtime_status,
                    "error",
                    format!("upload failed; retained for retry: {error:#}"),
                );
                leds.lock()
                    .unwrap_or_else(|poisoned| poisoned.into_inner())
                    .error();
            }
        }
    }

    fn start_admin_server(
        &self,
        leds: Arc<Mutex<LedPanel>>,
        led_test_active: Arc<AtomicBool>,
        lab: CameraLab,
    ) -> Result<()> {
        let listener = std::net::TcpListener::bind(&self.config.admin_bind)
            .with_context(|| format!("bind admin server to {}", self.config.admin_bind))?;
        listener.set_nonblocking(true)?;
        let local = listener.local_addr()?;
        let state = AdminState {
            config: self.config.clone(),
            camera: self.camera.clone(),
            uploader: self.uploader.clone(),
            operation_lock: Arc::clone(&self.operation_lock),
            runtime_status: self.runtime_status.clone(),
            leds,
            led_test_active,
            lab,
            started_at: self.started_at,
        };

        thread::Builder::new()
            .name("daily-mirror-admin".to_owned())
            .spawn(move || {
                let runtime = tokio::runtime::Builder::new_current_thread()
                    .enable_all()
                    .build()
                    .expect("build admin Tokio runtime");
                runtime.block_on(async move {
                    let listener = tokio::net::TcpListener::from_std(listener)
                        .expect("adopt admin TCP listener");
                    let app = admin_router(state);
                    if let Err(error) = axum::serve(listener, app).await {
                        eprintln!("admin server stopped: {error}");
                    }
                });
            })?;
        println!("admin: http://{local}");
        Ok(())
    }
}

#[derive(Clone)]
struct Camera {
    profile: CameraProfile,
    command: String,
    args: Vec<String>,
    photo_settings: Arc<RwLock<PhotoSettings>>,
    local_dir: PathBuf,
    queue_dir: PathBuf,
    camera_lock: Arc<Mutex<()>>,
    orientation: Arc<RwLock<CameraOrientation>>,
    orientation_path: PathBuf,
}
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

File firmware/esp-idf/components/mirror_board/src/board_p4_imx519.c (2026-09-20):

/*
 * SPDX-License-Identifier: Apache-2.0
 *
 * Portions adapted from the imx708_wifi_snapshot example in
 * mushBrainDave/esp32-p4-imx-camera (Apache-2.0); see ../../../NOTICE.
 *
 * Board adapter: Waveshare ESP32-P4 + Arducam IMX519 (AK7375 autofocus).
 *
 * MIPI-CSI through esp_video, the ISP doing AE/AWB/AF, and the P4's hardware
 * JPEG encoder. A capture task keeps the pipeline running and republishes the
 * newest RGB565 frame into PSRAM; captures encode from that copy.
 *
 * Serving straight from a dequeued V4L2 buffer would be simpler and wrong. The
 * camera does not stop while a response is on the wire, and with BUFFER_COUNT
 * buffers - one held by a handler - the driver runs out of places to put
 * incoming frames and recycles the one being read: clean at the top, junk at
 * the bottom. Keeping the stream running between captures also means AE, AWB
 * and autofocus stay converged, so a press returns a settled frame rather than
 * the first frame after a cold start.
 */
#include <string.h>
#include <fcntl.h>
#include <unistd.h>
#include <inttypes.h>
#include <sys/ioctl.h>
#include <sys/mman.h>

#include "freertos/FreeRTOS.h"
#include "freertos/task.h"
#include "freertos/semphr.h"
#include "esp_log.h"
#include "esp_heap_caps.h"
#include "driver/gpio.h"
#include "driver/ledc.h"
#include "driver/jpeg_encode.h"
#include "linux/videodev2.h"
#include "esp_video_init.h"
#include "esp_video_device.h"

#include "mirror_board.h"

static const char *TAG = "board_p4";

#define CAM_SCCB_I2C_PORT 0
#define CAM_SCCB_FREQ_HZ  100000
#define BUFFER_COUNT      2

static const esp_video_init_csi_config_t s_csi_config[] = {{
    .sccb_config = {
        .init_sccb = true,
        .i2c_config = {
            .port = CAM_SCCB_I2C_PORT,
            .scl_pin = CONFIG_MIRROR_CAM_SCCB_SCL_GPIO,
            .sda_pin = CONFIG_MIRROR_CAM_SCCB_SDA_GPIO,
        },
        .freq = CAM_SCCB_FREQ_HZ,
    },
    .reset_pin = -1,   /* the IMX519 module brings out neither */
    .pwdn_pin  = -1,
}};

/*
 * The AK7375 VCM is a separate chip from the sensor (I2C 0x0c on the same
 * bus), so esp_video probes for it separately and needs its own entry -
 * without one the motor auto-detect array is never walked and the lens never
 * moves, which looks exactly like a broken lens.
 */
static const esp_video_init_cam_motor_config_t s_motor_config[] = {{
    .sccb_config = {
        .init_sccb = true,
        .i2c_config = {
            .port = CAM_SCCB_I2C_PORT,
            .scl_pin = CONFIG_MIRROR_CAM_SCCB_SCL_GPIO,
            .sda_pin = CONFIG_MIRROR_CAM_SCCB_SDA_GPIO,
        },
        .freq = CAM_SCCB_FREQ_HZ,
    },
    .reset_pin  = -1,
    .pwdn_pin   = -1,
    .signal_pin = -1,
}};

static const esp_video_init_config_t s_cam_config = {
    .csi = s_csi_config,
    .cam_motor = s_motor_config,
};

/* The published frame. */
static uint8_t *s_frame;
static size_t s_frame_len;
static volatile uint32_t s_frame_seq;
static SemaphoreHandle_t s_frame_lock;
static uint32_t s_w, s_h;
static char s_status[72] = "camera not started";

struct capture_ctx {
    int fd;
    uint8_t **buffer;   /* the mmap'd V4L2 buffer table, indexed by buf.index */
};

static void capture_task(void *arg)
{
    struct capture_ctx *ctx = arg;
    const int type = V4L2_BUF_TYPE_VIDEO_CAPTURE;

    for (;;) {
        struct v4l2_buffer buf = { .type = type, .memory = V4L2_MEMORY_MMAP };
        if (ioctl(ctx->fd, VIDIOC_DQBUF, &buf) != 0) {
            ESP_LOGE(TAG, "DQBUF failed - capture task stopping");
            vTaskDelete(NULL);
            return;
        }
        if (xSemaphoreTake(s_frame_lock, pdMS_TO_TICKS(1000)) == pdTRUE) {
            memcpy(s_frame, ctx->buffer[buf.index], s_frame_len);
            s_frame_seq++;
            xSemaphoreGive(s_frame_lock);
        }
        /* Straight back to the driver: the publish above is a memcpy, so a
         * buffer is never held across anything slow. */
        ioctl(ctx->fd, VIDIOC_QBUF, &buf);
    }
}

const char *board_name(void) { return "ESP32-P4 + IMX519"; }
const char *board_id(void)   { return "esp32p4-imx519"; }
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

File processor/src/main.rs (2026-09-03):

use std::sync::Arc;
use std::sync::atomic::{AtomicBool, Ordering};

use std::path::PathBuf;

use anyhow::{Context, Result};
use clap::{Parser, Subcommand, ValueEnum};
use daily_mirror_processor::mediapipe_engine::MediaPipeFaceEngine;
use daily_mirror_processor::opencv_engine::{
    InferenceTarget, OpenCvFaceEngine, OpenCvFaceEngineOptions,
};
use daily_mirror_processor::{
    FaceProcessor, HttpQueueClient, ProcessorRunner, QueueClient, configured_pipeline_version,
};

#[derive(Parser)]
#[command(about = "Intermittent Rust photo processor for Daily Mirror")]
struct Cli {
    #[command(subcommand)]
    command: Command,
}

#[derive(Subcommand)]
enum Command {
    /// Show how many photos are pending, leased, complete, or failed.
    Status,
    /// Drain queued photos with face detection, landmarks, and SFace embeddings.
    Process {
        #[arg(long, default_value_t = 20)]
        batch_size: u16,
        #[arg(long, value_enum, default_value_t = EngineKind::MediaPipe)]
        engine: EngineKind,
        #[arg(long, value_enum, default_value_t = Device::Auto)]
        device: Device,
        #[arg(
            long,
            env = "DAILY_MIRROR_MEDIAPIPE_FACE_LANDMARKER_MODEL",
            default_value = "models/face_landmarker.task"
        )]
        landmarker_model: PathBuf,
        #[arg(
            long,
            env = "DAILY_MIRROR_YUNET_MODEL",
            default_value = "models/face_detection_yunet_2023mar.onnx"
        )]
        detector_model: PathBuf,
        #[arg(
            long,
            env = "DAILY_MIRROR_SFACE_MODEL",
            default_value = "models/face_recognition_sface_2021dec.onnx"
        )]
        recognizer_model: PathBuf,
        #[arg(long, env = "DAILY_MIRROR_YUNET_MAX_EDGE", default_value_t = 1_600)]
        detector_max_edge: u32,
        #[arg(
            long,
            env = "DAILY_MIRROR_YUNET_SCORE_THRESHOLD",
            default_value_t = 0.8
        )]
        detector_score_threshold: f32,
    },
}

#[derive(Clone, Copy, Debug, Default, ValueEnum)]
enum Device {
    #[default]
    Auto,
    Cpu,
    OpenCl,
    Cuda,
}

#[derive(Clone, Copy, Debug, Default, ValueEnum)]
enum EngineKind {
    #[default]
    MediaPipe,
    YuNet,
}

#[tokio::main]
async fn main() -> Result<()> {
    load_environment()?;
    let cli = Cli::parse();
    let client = configured_client()?;
    let pipeline = configured_pipeline_version();

    match cli.command {
        Command::Status => {
            let status = client.status(&pipeline).await?;
            println!(
                "Pipeline: {}\nPending: {}  Leased: {}  Complete: {}  Failed: {}",
                status.pipeline_version,
                status.pending,
                status.leased,
                status.complete,
                status.failed
            );
        }
        Command::Process {
            batch_size,
            engine,
            device,
            landmarker_model,
            detector_model,
            recognizer_model,
            detector_max_edge,
            detector_score_threshold,
        } => {
            let shutdown = install_shutdown_handler();
            let (engine, target_label): (Box<dyn FaceProcessor>, _) = match engine {
                EngineKind::MediaPipe => {
                    let engine = MediaPipeFaceEngine::new_with_options(
                        &detector_model,
                        &landmarker_model,
                        &recognizer_model,
                        pipeline,
                        OpenCvFaceEngineOptions {
                            detector_max_edge,
                            detector_score_threshold,
                        },
                    )?;
                    let label = engine.target_label();
                    (Box::new(engine), label)
                }
                EngineKind::YuNet => {
                    let engine = OpenCvFaceEngine::new_with_options(
                        &detector_model,
                        &recognizer_model,
                        pipeline,
                        device.into(),
                        OpenCvFaceEngineOptions {
                            detector_max_edge,
                            detector_score_threshold,
                        },
                    )?;
                    let label = engine.target_label();
                    (Box::new(engine), label)
                }
            };
            println!("inference target: {target_label}");
            let worker_id = std::env::var("DAILY_MIRROR_PROCESSOR_ID")
                .unwrap_or_else(|_| "desktop-processor".to_owned());
            let mut runner = ProcessorRunner::new(client, engine, worker_id, batch_size, shutdown)?;
            let summary = runner.drain().await?;
            println!(
                "finished: {} claimed, {} complete, {} failed, {} skipped",
                summary.claimed, summary.completed, summary.failed, summary.skipped
            );
        }
    }
    Ok(())
}

fn load_environment() -> Result<()> {
    let Ok(environment) = std::env::var("DAILY_MIRROR_ENV") else {
        dotenvy::dotenv().ok();
        return Ok(());
    };
    let path = environment_path(&environment)?;
    dotenvy::from_path(&path).with_context(|| {
        format!(
            "could not load processor environment from {}",
            path.display()
        )
    })?;
    eprintln!("processor environment: {environment} ({})", path.display());
    Ok(())
}

fn environment_path(environment: &str) -> Result<PathBuf> {
    let valid = !environment.is_empty()
        && environment.len() <= 40
        && environment
            .bytes()
            .all(|byte| byte.is_ascii_alphanumeric() || matches!(byte, b'-' | b'_'));
    if !valid {
        anyhow::bail!("processor environment must use only letters, numbers, '-' or '_'");
    }
    Ok(PathBuf::from(format!(".env.{environment}")))
}

impl From<Device> for InferenceTarget {
    fn from(value: Device) -> Self {
        match value {
            Device::Auto => Self::Auto,
            Device::Cpu => Self::Cpu,
            Device::OpenCl => Self::OpenCl,
            Device::Cuda => Self::Cuda,
        }
    }
}

fn configured_client() -> Result<HttpQueueClient> {
    let server_url =
        std::env::var("DAILY_MIRROR_SERVER_URL").context("DAILY_MIRROR_SERVER_URL is required")?;
    let token = std::env::var("DAILY_MIRROR_PROCESSOR_TOKEN")
        .context("DAILY_MIRROR_PROCESSOR_TOKEN is required")?;
    HttpQueueClient::new(server_url, &token)
}
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

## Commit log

2026-08-30 Revive Daily Mirror device and gallery
2026-09-02 Add focus calibration controls to Pi admin
2026-09-04 Add focus/sharpness experiment harness and findings
    Empirical sweep on the Pi shows AF lands at the true focus peak while the
    lab's 0.82-dioptre preset is 3x off; the dominant blur source is low light
    (60ms shutter at 4.4x gain), not focus. Documents recommended camera args
    (--sharpness 1.5, --exposure sport, restored metadata logging).
2026-09-04 Document AF-window root cause and validated camera args
    Live testing with a subject in frame showed production AF back-focuses
    0.4-0.5 dioptres without an autofocus window; a centered window doubles
    measured sharpness and makes AF repeatable. Updates the recommended
    DAILY_MIRROR_CAMERA_ARGS and .env.example accordingly.
2026-09-04 Rotate stills losslessly after capture instead of on the sensor
    Sensor-side flips (--rotation 180) change the IMX519 Bayer phase and
    break autofocus: identical scenes focus at lens position ~1.2 instead of
    ~2.5 with half the focus figure-of-merit, and production captures were
    landing at infinity. Stills now capture unrotated and are transformed
    with jpegtran -rotate 180 (lossless, requires libjpeg-turbo-progs on the
    Pi). The lab live preview keeps sensor rotation since it is only used
    for framing.
    [main.rs]
2026-09-08 Run image recognition in isolated Vercel functions with cron recovery (#8)
    * Isolate hosted image inference and recover jobs with NextRS cron
    * Prepare image-processing changes against current main
    * Record hosted processor binding dependency in lockfile
    [main.rs]
2026-09-09 Support camera profiles, local captures, and common-anode RGB LEDs
2026-09-09 Add parametric Pi enclosure concept and adjustable-height mounting plan
    [Base.step, Base.stl, CameraAdapter.step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]
2026-09-09 Add Pi local capture gallery with EXIF viewer and camera profiles
2026-09-16 Simplify Archive header, speed up photo edits, add flipbook exclusion and face labels
    Mobile: the Archive header is one row with a date chip that opens filters;
    rotation shows immediately while the server saves; deletion closes the viewer
    and drops the photo from the grid at once; the viewer gains a flipbook
    include/exclude toggle and a face-label overlay with name tags.
    Server: photos carry a durable flipbook_excluded flag (PUT
    /api/photos/{id}/flipbook) filtered out of flipbook frames and person photos,
    and GET /api/photos/{id}/faces exposes per-photo face bounds and identities.
2026-09-16 Add device pairing plan and platform-neutral mirror-core crate (#9)
    Records the 2026-09-15 decisions: the ESP32-P4 with IMX519 is the product
    target, the Pi stays as the experiment rig, pairing uses a short-lived claim
    token exchanged for a per-device token, SoftAP provisioning first with BLE
    later, press-to-confirm proof of possession, one household per device, and a
    20 s hold plus triple-click full reset.
    crates/mirror-core holds the pure device logic every adapter shares: the
    state machine with every transition in the plan tested, the button gesture
    detector, the ring vocabulary, adapter traits, and the request/response
    models for the two new server routes.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
    [button.rs]
2026-09-19 Onboarding, device pairing, and ESP32 camera firmware in one branch (#15)
    * Add device pairing plan and platform-neutral mirror-core crate
    detector, the ring vocabulary, adapter traits, and the request/respo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
    [partitions.csv]
2026-09-19 Build server bundles in a self-contained image (#16)
    * Build server bundles in a self-contained image
    `nextrs deploy` and `vercel build` both compile on the host, where OpenCV 5
    links against glibc 2.44. Vercel's runtime is far older, so those binaries
    cannot run there; the vision bundle has to be built against Debian 11.
    Make the build image carry everything it needs. It already built OpenCV
    4.12 from source, but borrowed Rust, cargo-nextrs, cargo-zigbuild and zig
    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
2026-09-19 Add P4 board, enclosure v2, and modular prototype design sources
    Vendor references, libraries, generated output, revision snapshots, and
    fab quotes stay local via .gitignore.
    [candidate-parts.csv, daily-mirror-p4.kicad_pcb, daily-mirror-p4.kicad_sch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]
2026-09-20 Persist Pi capture policy in shared photo settings
    The Raspberry Pi client decided test-versus-upload mode and the camera
    profile in two places: the physical button path and the admin HTTP
    actions. They could disagree, and neither survived a restart.
    Move the policy into a single `photo_settings` module that validates the
    profile against the detected sensor and is persisted to disk, so the
    button and the admin API always agree and the choice outlives a reboot.
    Drop the now-unused LED helpers and update the local capture tests and
    the device README to match.
    [main.rs]
2026-09-20 Record IMX519 calibration and the burst/banding experiment
    The rpi2 camera module was replaced with an IMX519 (AK7375 focus
    actuator) whose stock tuning ships no autofocus algorithm, so the
    sensor needed its own overlay, tuning file and profile before it could
    be trusted. Separately, we wanted to know whether a multi-frame burst
    could beat single-shot capture and whether a 60 Hz display causes
    visible banding.
    Write both up with the scripts that produced them: tuning preparation,
    a Tk calibration target, burst capture on the Pi, offline processing
    and its test. Keep the measured manifests and settings under
    docs/evidence/ (all small JSON) so the numbers in the documents can be
    checked later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
2026-09-20 Add the CoreDevice tailnet bridge script
    Xcode only offers a wireless device when it can see the iPhone's
    CoreDevice Bonjour advertisement on the local link, which a Tailscale
    connection cannot provide. Builds therefore could not be driven from
    the dev machine to the phone over the tailnet.
    Add a temporary relay, run on the paired Mac, that re-advertises the
    captured Bonjour instance and forwards the CoreDevice TCP and UDP
    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
2026-09-20 Pair the ESP32-S3 over BLE and claim it for a household
    The server and the app already had the whole pairing contract; the
    camera was the missing half, so a new unit could not be added to a
    household at all. Wi-Fi setup also had to stop being a "join the
    camera's access point" step, because that is the part of the flow
    people actually fail.
    Implement the device side as Espressif Wi-Fi provisioning over BLE
    (NimBLE), matching the five things the app's ESPProvision call fixes:
    transport, the lowercase "mirror-<mac>" name, the default service UUID,
    protocomm security 2 with an SRP6a salt/verifier derived at start-up,
    and a "daily-mirror" endpoint carrying {server_url, claim_token} in and
    a Pro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
    [mirror_press.c]
2026-09-20 Spool captures to flash and retry uploads until they land
    The first photos from the newly paired camera never arrived. Two root
    causes, both found on real hardware: the device had no clock, so it
    minted implausible capture ids the server would not accept, and a press
    uploaded inline exactly once, so any failure silently dropped the photo
    after the ring had already flashed green.
    Give the device time (SNTP) and real capture ids
    (`YYYYMMDDTHHMMSSZ-<8 hex>`). A capture taken before the clock is valid
    is held rather than stamped with a 1970 date, which is seconds at worst
    and preserves capture order either way.
    Put every capture on flash before the network is touched: a LittleFS
    `spool` partit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
    [partitions.csv]
2026-09-20 Give the ring layers so a press always wins
    The ring was a single variable owned by whoever wrote to it last, so
    every caller had to know what to put back when it finished - and got it
    wrong the moment two overlapped. An upload completing would wipe the
    countdown of the press that had interrupted it.
    Model the ring as three layers - BASE (idle, pairing, claiming, reset),
    UPLOAD (the spool) and CAPTURE (a press) - and render the topmost
    active one, so a layer clearing restores what is underneath by itself.
    A button press therefore always wins immediately. Pairing is the one
    inversion: it sits on BASE but outranks UPLOAD, because "press the
    button to confirm" must not be hidden by a photo goi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
2026-09-20 Add the capture flash and sharpen the board abstraction
    Indoor captures in the evening are the blur we keep chasing, so the
    board layer grows a flash: on/off rather than a brightness, because the
    pin is driven directly today and there is nothing to dim. Arming it
    starts a hard timeout inside the board adapter, so nothing above is
    trusted to be the thing that switches the light off. When the MOSFET
    stage arrives a board_flash_set_level() lands beside it and no caller
    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
2026-09-20 Set a camera up over Bluetooth instead of its own Wi-Fi
    The old flow asked people to leave their home network, join the
    camera's access point and come back, which is the step setup actually
    dies on. The firmware now provisions over BLE, so the app can scan,
    show nearby cameras in a list and stay on Wi-Fi throughout.
    Make BLE the transport and drop the join-Wi-Fi step; SoftAP stays
    available as a bench fallback, so both permission sets are still
    requested. Match the device's lowercase `mirror-` advertisement prefix,
    and pass the proof of possession and username the way ESPDevice.connect
    expects - getting either wrong failed the handshake before any data
    moved.
    Two bugs found while pairing r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
2026-09-20 Share one pull-to-refresh hook so the spinner clears
    The refresh spinner stuck at the top of Account, Archive and Flipbooks
    and only cleared when the screen was touched. Each screen had wired
    RefreshControl's `refreshing` to a background `isFetching` flag, which
    flips faster than the control can animate and leaves it stranded.
    Put the pattern in one `usePullToRefresh` hook that owns the refreshing
    flag for the duration of an explicit pull only, and use it from the
    screens that had the glitch, so the fix lands once rather than three
    times.
2026-09-20 Sign in with a passkey without typing a username
    Native passkeys had been switched off while the Apple Developer
    membership lapsed, because Associated Domains needs a paid team. The
    membership is active again on the same Team ID, so re-enable them - and
    fix the thing that made them awkward even when they worked: the app
    demanded a username before it would offer a passkey, which is the one
    credential that does not need one.
    Make the username optional on both the native and web passkey start
    endpoints. A request without one runs a discoverable ceremony: the
    server returns a challenge with an empty allowCredentials, the
    authenticator picks the account, and finish identifies it from the
    asserti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
2026-09-20 Resolve one household everywhere, with roles and a rename
    "Your household could not be loaded" and cameras landing nowhere had
    the same cause: two different answers to "which household is this
    account in". Pairing used `household_users` and auto-created a "Home"
    row when it found nothing; the Household screen used
    `users.household_id`, which is NULL for any account predating
    onboarding. Some paths then fell back to the oldest household in the
    database, which on a multi-tenant server is a data leak waiting to
    happen.
    Resolve the household one way, and never guess: an account with no
    household gets a clear 409 rather than someone else's. Give accounts an
    `admin` or `member` standing in that h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
2026-09-20 Record how each photograph was taken
    A blurry or badly exposed photo could only be traced as far as
    `photos.device_id`, so "why does this one look wrong" had no answer.
    Record the provenance per photo as real, typed, nullable columns rather
    than a JSON blob, so it can be queried, indexed and shown: firmware
    version, sensor, dimensions, JPEG quality, exposure, gain, focus state,
    flash, trigger and source. Every column is nullable because each sensor
    reports what it can and older photographs report nothing; units are
    documented in docs/capture-metadata.md.
    Devices send the metadata with the upload grant; phone captures record
    source=phone with what the camera module knows. The photo detail vi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
2026-09-20 Bring the docs in step with BLE pairing and the paid team
    The firmware roadmap and the integration notes still described SoftAP
    provisioning and a `Mirror-XXXX` service name, which is neither what
    the firmware advertises nor what the app scans for. The mobile docs
    still said native passkeys were off for a free Personal Team, which
    stopped being true when the membership was renewed.
    Correct all four, document the deploy script's environment loading and
    the migrate step in docs/deployment.md, and record the enclosure v2 CAD
    revision (Pi 4 B, whole-enclosure rail mount) in the enclosure plan.
2026-09-24 Register a camera that cannot run the claim flow
    The original Pi rig predates pairing: it has no way to redeem a claim
    token, so it still uploads with the deployment-wide shared token and its
    photographs land with no device, no household, and none of the capture
    columns the rest of the fleet now fills in.
    `daily-mirror-onboarding register-device` gives such a camera the same
    credential a paired one gets. It mints through `random_token` and stores
    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
2026-09-24 Give the Pi its own token and let it say how it shot
    The Pi has been uploading with the deployment-wide shared token since
    before pairing existed, so every photograph it contributes lands with no
    device, no household, and every capture column empty — next to an ESP32
    whose photographs carry all of it.
    `DAILY_MIRROR_DEVICE_TOKEN` is now preferred over the shared token for
    the grant, the upload and the completion call alike. It is only a
    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
2026-10-04 Add S3 wiring drawing for the 12V COB photo-light strip
    GPIO 47 already drives the capture flash, but nothing showed how to hang a
    12V strip off it: a logic-level N-MOSFET on the low side, 100 ohm gate
    resistor, 10k pulldown so the strip stays dark through boot, and a ground
    shared with the 12V supply.
